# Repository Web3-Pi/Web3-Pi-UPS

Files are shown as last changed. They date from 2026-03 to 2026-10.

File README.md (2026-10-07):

# Web3 Pi UPS

**Open-source DC Uninterruptible Power Supply for Raspberry Pi 5**

**[Product page](https://www.web3pi.io/products/ups)** · **[Watch on YouTube](https://www.youtube.com/watch?v=3EgSPatHWfY)** · **[Web panel](https://panel.web3pi.io)** · **[User guide](https://docs.web3pi.io/ups/)**

<p align="center">
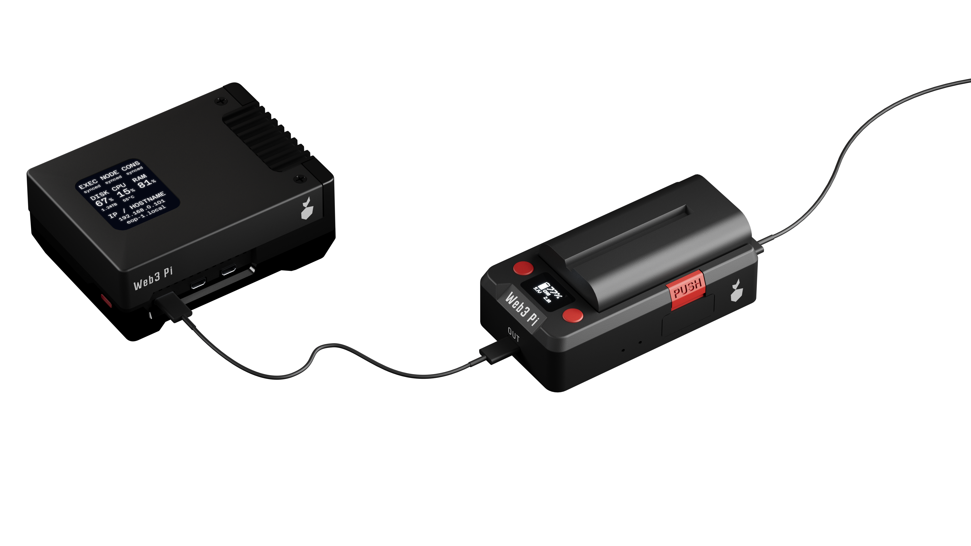
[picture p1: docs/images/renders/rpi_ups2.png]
Web3 Pi UPS with Raspberry Pi 5
  
</p>

Start with the [hardware quick start](docs/QuickStart.md), then install the
[Raspberry Pi host service](https://github.com/Web3-Pi/Web3-Pi-UPS-Service)
for OS telemetry and graceful shutdown. Firmware builds and the companion
projects are listed below.

The Web3 Pi UPS is a purpose-built, compact DC UPS designed specifically for the Raspberry Pi 5. Born from the [Web3 Pi](https://www.web3pi.io) project — a platform for running Ethereum nodes on Raspberry Pi — it exists because nothing else on the market solved the problem properly.

Running an Ethereum node requires 24/7 uptime. A power outage doesn't just interrupt service — it can corrupt the node database, requiring hours or even days of re-synchronization. For solo stakers, downtime means missed attestations and real financial penalties. We needed a UPS that actually fits the Raspberry Pi form factor, and when we couldn't find one, we built it ourselves.

## Why Not an Existing UPS?

Traditional UPS units are massive compared to a Raspberry Pi. They convert mains AC to DC to charge a battery, then invert DC back to AC for output, only for your Raspberry Pi's power supply to convert it back to DC again. Each conversion wastes energy and generates heat.

HAT-style UPS boards for Raspberry Pi stack on top via GPIO, making them incompatible with most enclosures and adding mechanical complexity.

**Web3 Pi UPS takes a different approach.** It sits between your charger and the Raspberry Pi, connected by a single USB-C cable. No GPIO, no stacking, no enclosure conflicts. It's a true DC UPS — power flows from input to battery to output without any AC conversion. Compact, silent, and efficient.

<p align="center">
  Web3 Pi UPS — multiple battery sizes
</p>

## Key Features

### Three Independent Power Sources

The UPS accepts power from three sources — any single one is enough to keep the output running:

- **USB-C PD input** (9–20 V profiles, selected through HUSB238) — primary power from a USB-C PD charger
- **DC barrel jack** (12–20 V) — alternative input for standard DC power supplies
- **Sony NP-F battery** — backup power when both external sources are lost

The power path seamlessly and instantly switches between sources with zero interruption. When external power is present, the battery charges. When external power drops, the battery takes over — no gap, no glitch.

### Sony NP-F Battery Ecosystem

<p align="center">
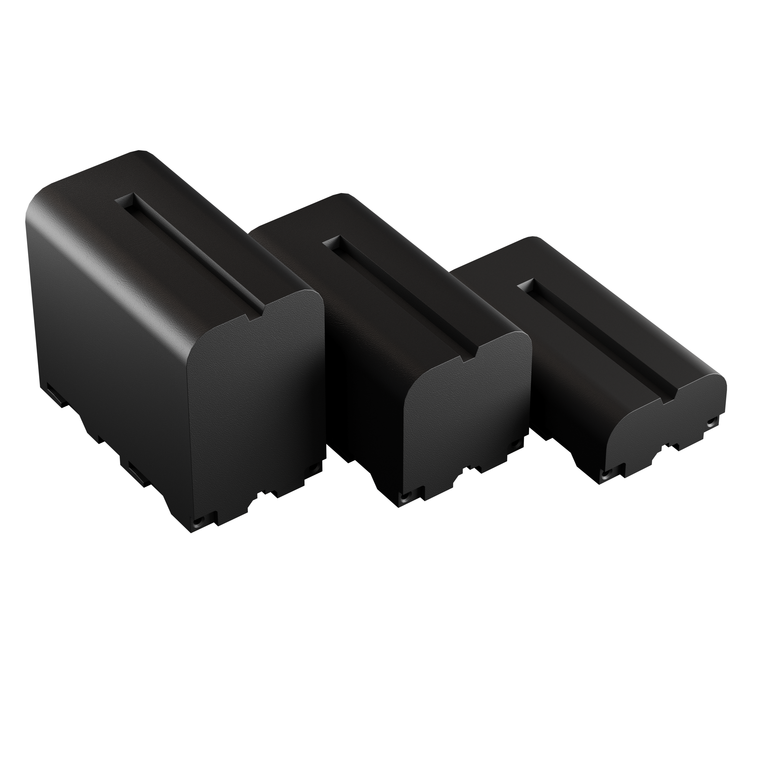
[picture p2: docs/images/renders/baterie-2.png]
Sony NP-F batteries
  
</p>

We chose the Sony NP-F battery system for a reason. These Li-ion cells are one of the most popular battery standards in the world, widely used in photography and videography equipment. You can buy them anywhere — online, in camera stores, globally. They come in multiple capacities to match your needs:

| Battery | Typical Capacity | Approximate Runtime* |
|---|---|---|
| NP-F570 | 2900 mAh | Shorter runtime, most compact |
| NP-F770 | 5200 mAh | Mid-range |
| NP-F970 | 6600 mAh | Longest runtime |

*Runtime depends on your Raspberry Pi's workload and connected peripherals.*

Batteries are **hot-swappable** — you can replace them while the system is running, as long as external power is connected. No downtime, no shutdown. You can also mix and match different NP-F sizes depending on your use case.

### Single USB-C Cable for Power and Communication

Here's something most people don't know: the USB-C port on the Raspberry Pi 5 isn't just for power. It also supports USB data transfer when enabled in `config.txt`. Web3 Pi UPS takes advantage of this — **one USB-C cable carries both power delivery and a data channel** between the UPS and the Raspberry Pi.

This data link enables:

- **Graceful shutdown** — when battery reaches a critical level, the UPS tells the OS to shut down cleanly, preventing filesystem and database corruption
- **Real-time telemetry** — battery level, charging status, input source, voltage, current, and temperature are all accessible from the Raspberry Pi
- **Remote monitoring** — integrate UPS status into your monitoring stack (Grafana, scripts, etc.)

### Built-in User Interface

The UPS has an OLED display (SSD1306) and two tactile buttons for local status monitoring and configuration — no need to SSH in just to check battery level. An onboard buzzer provides audible alerts for power events.

<p align="center">
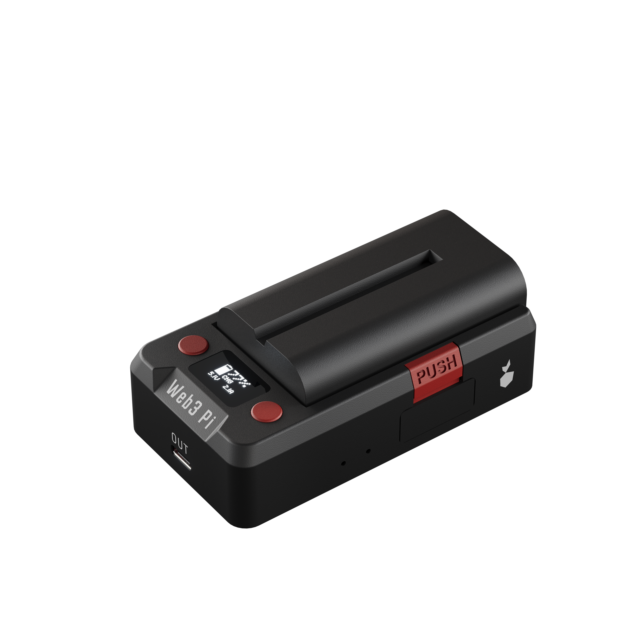
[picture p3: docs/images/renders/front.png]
Web3 Pi UPS — front view
  
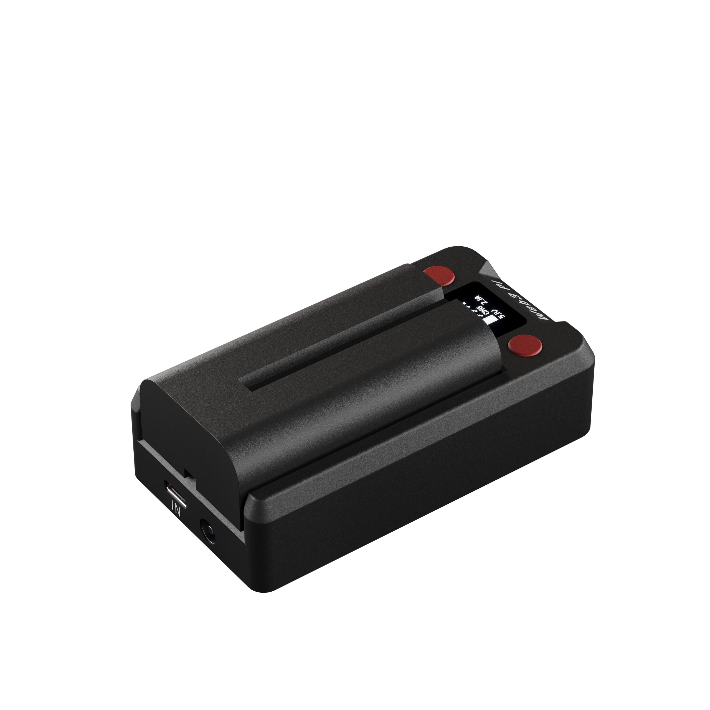
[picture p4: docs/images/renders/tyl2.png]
Web3 Pi UPS — rear view
  
</p>

### USB-C PD Output

The output port supports USB Power Delivery with multiple voltage profiles:

- **5 V / 5 A, 9 V / 3 A, 12 V / 2.25 A, 15 V / 1.8 A** — four advertised profiles, up to **27 W**
- Fully compatible with Raspberry Pi 5 power requirements
- Also works with other USB-C PD powered devices

### Smart Battery Management

The onboard charger (MP2762A) handles 2S Li-ion charging with temperature monitoring via an LM75B sensor. The power path management reduces battery wear by limiting charge when the battery is full — extending its lifespan over hundreds of cycles.

## A Raspberry Pi for Raspberry Pi

A fun detail: the UPS uses a **Raspberry Pi RP2040** microcontroller for the UI panel and system monitoring. So it's a Raspberry Pi-powered device, built for Raspberry Pi.

The current rev.3 power board uses a **CH32X035** RISC-V MCU for USB-PD
output and power management. A separate **HUSB238** negotiates USB-C input
power. The RP2040 also routes the shared WUPS binary protocol between the
power controller, Raspberry Pi host service and optional LTE-M card.

### Optional LTE-M Expansion

The **W3P MODEM V1** M.2 card combines an **ESP32-S3** with a **SIM7080G**
modem. It provides telemetry, authenticated remote commands and ESP32/RP2040
firmware updates over MQTT, HTTP or Arkiv while operating independently of
the Raspberry Pi's local network. The current firmware targets **LTE Cat-M1
on B3/B20**. See the [LTE-M firmware README](firmware-ESP32-LTE-M/README.md)
for hardware details, APN profiles and update requirements.

<p align="center">
  <a href="docs/images/lte-m-module-perspective.png">
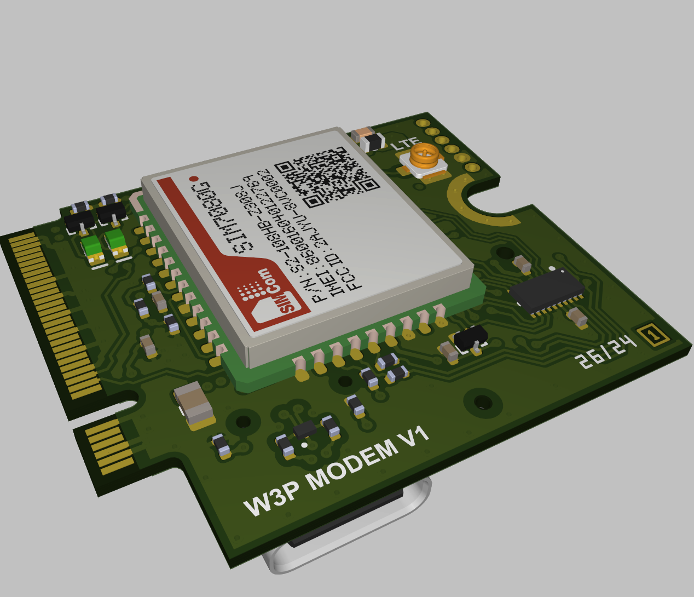
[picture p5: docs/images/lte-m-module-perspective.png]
W3P MODEM V1 M.2 LTE-M expansion card — perspective render
    
  </a>
</p>
<p align="center">
  <a href="docs/images/lte-m-module-modem-side.png">
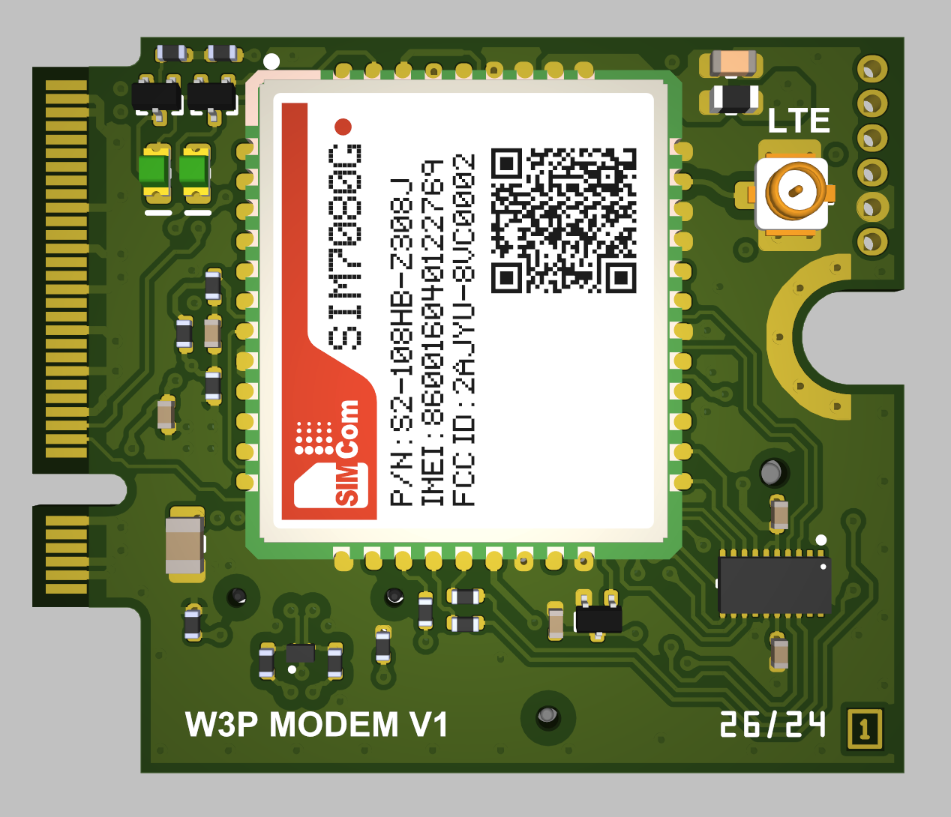
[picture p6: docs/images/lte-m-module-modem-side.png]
W3P MODEM V1 — SIM7080G modem and LTE antenna connector side
    
  </a>
  <a href="docs/images/lte-m-module-reverse.png">
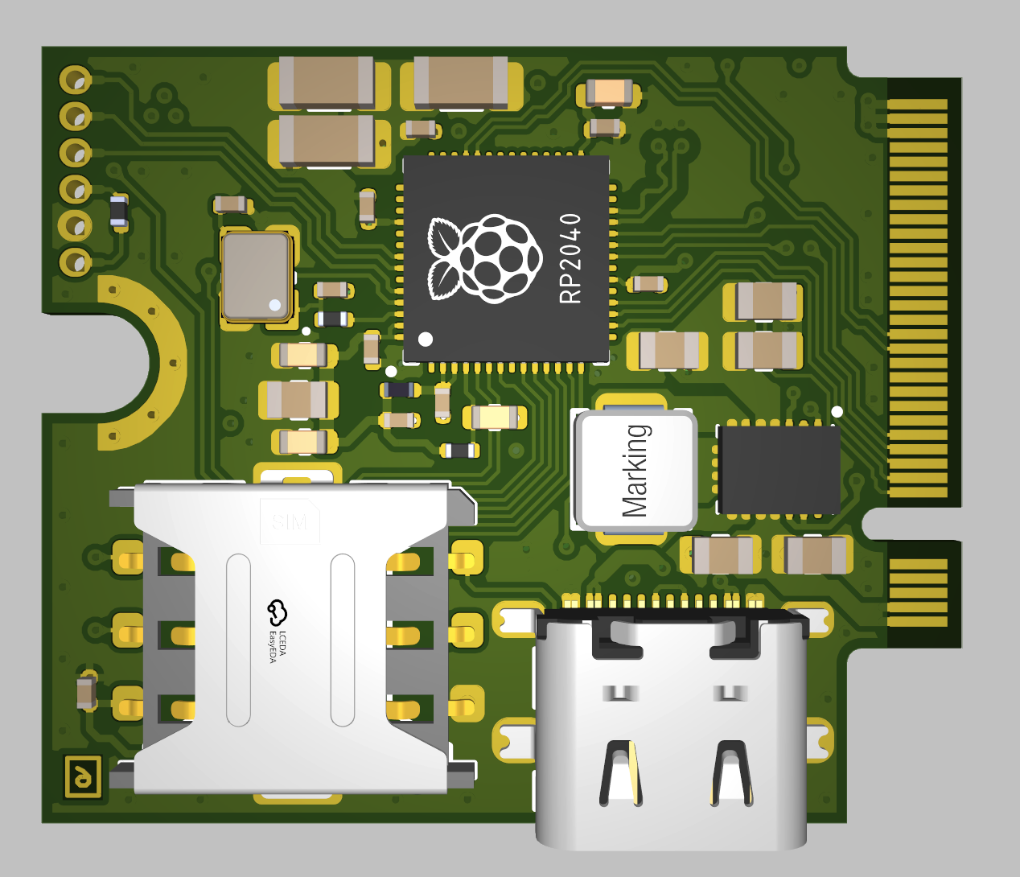
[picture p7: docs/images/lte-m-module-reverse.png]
W3P MODEM V1 — reverse-side render with SIM holder and USB-C connector
    
  </a>
</p>

*W3P MODEM V1 — 3D design renders. The RP2040 marking on the reverse-side
render differs from the current module's documented ESP32-S3 MCU.*

## Web Panel and Remote Management

The [Web3 Pi Control Panel](https://panel.web3pi.io) lets you monitor and
manage your UPS from a browser. With the LTE-M expansion, the UPS communicates
independently of the Raspberry Pi's local network.

<p align="center">
  <a href="https://panel.web3pi.io">
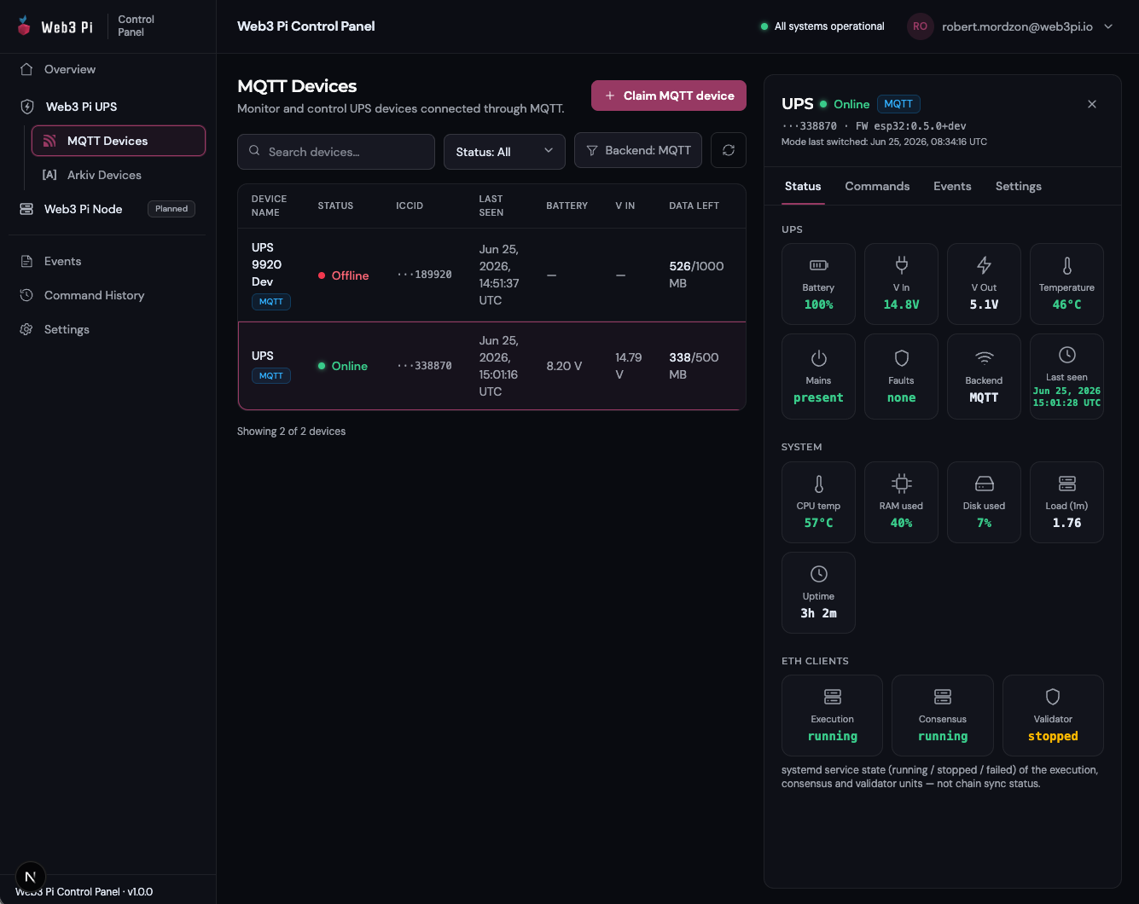
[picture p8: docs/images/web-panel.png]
Web3 Pi web panel showing the MQTT device list, UPS power telemetry, Raspberry Pi metrics and Ethereum service states
    
  </a>
</p>

*MQTT device list and status view, from the project documentation (June 2026).*

- **Live monitoring** — battery, input/output power, temperature, faults,
  LTE radio quality and remaining SIM data.
- **Raspberry Pi status** — CPU temperature, memory, disk, uptime and
  execution/consensus/validator service states, supplied by the
  [host service](https://github.com/Web3-Pi/Web3-Pi-UPS-Service).
- **Remote control and history** — manage the UPS output, reboot or shut
  down the Pi, start/stop/restart allowed services, and review events and
  command results.
- **Firmware updates** — update the ESP32 or RP2040 over LTE and follow
  update progress in the panel.

MQTT devices use an account and sticker claim token; Arkiv devices use
owner-wallet claims and encrypted telemetry. See the
[web panel guide](https://docs.web3pi.io/ups/connectivity/web-panel/) for
setup and the [panel repository](https://github.com/Web3-Pi/Web3-Pi-UPS-Panel)
for source code.

## Technical Summary

| Parameter | Specification |
|---|---|
| **Output** | USB-C PD: 5 V / 5 A, 9 V / 3 A, 12 V / 2.25 A, 15 V / 1.8 A |
| **Input 1** | USB-C PD through HUSB238; 9–20 V profile selection |
| **Input 2** | DC barrel jack (12–20 V) |
| **Input 3** | Sony NP-F battery (Li-ion, 2S) |
| **Battery** | Sony NP-F series — NP-F570 / NP-F770 / NP-F970 |
| **Hot-swap** | Yes (with external power connected) |
| **Communication** | USB data over the same USB-C power cable |
| **Display** | SSD1306 OLED |
| **Controls** | 2 tactile buttons + buzzer |
| **MCU (power)** | CH32X035F8U6 (RISC-V, USB-PD 3.0 PHY) |
| **MCU (UI / protocol router)** | Raspberry Pi RP2040 |
| **Optional connectivity** | W3P MODEM V1: ESP32-S3 + SIM7080G, LTE-M B3/B20 |
| **DC-DC** | TPS55289 buck-boost (3-30V range) |
| **Charger** | MP2762A (2S Li-ion, temp monitored) |
| **Enclosure** | 3D-printed (FDM), snap-fit assembly |

## Electronics

### Main Board

4-layer PCB with USB-PD controller, charger, DC-DC converter, and NP-F battery connector.

<p align="center">
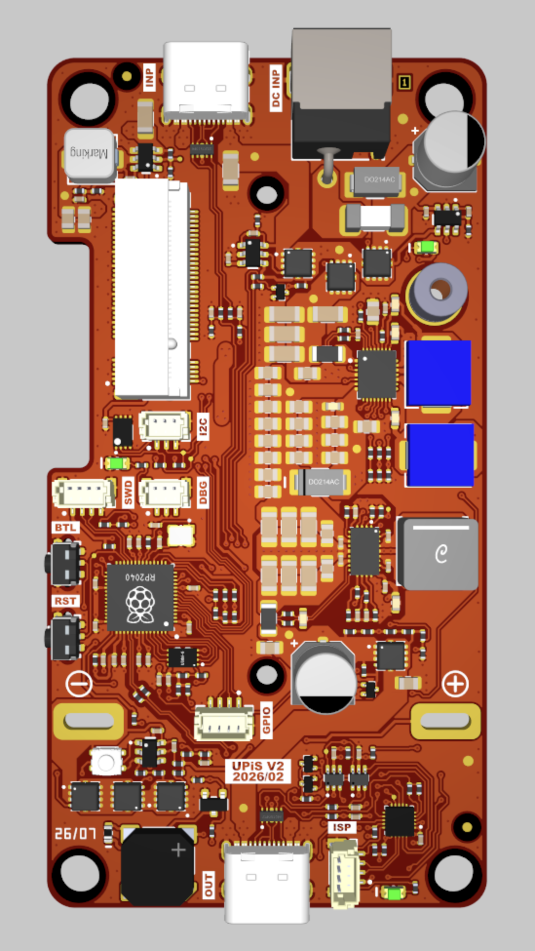
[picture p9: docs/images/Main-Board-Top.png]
Main Board — top
  
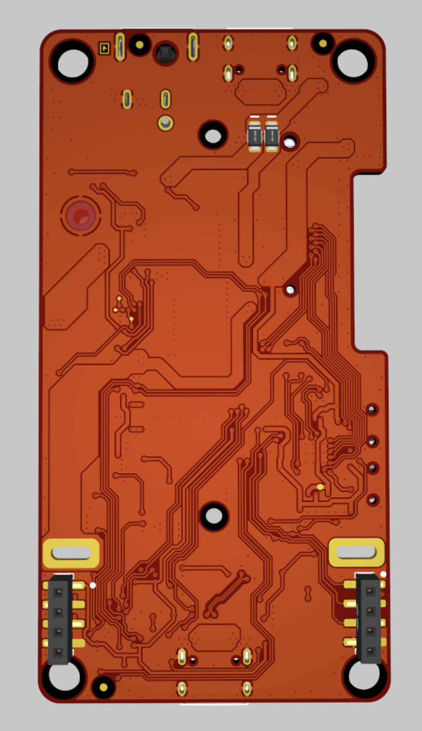
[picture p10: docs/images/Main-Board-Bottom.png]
Main Board — bottom
  
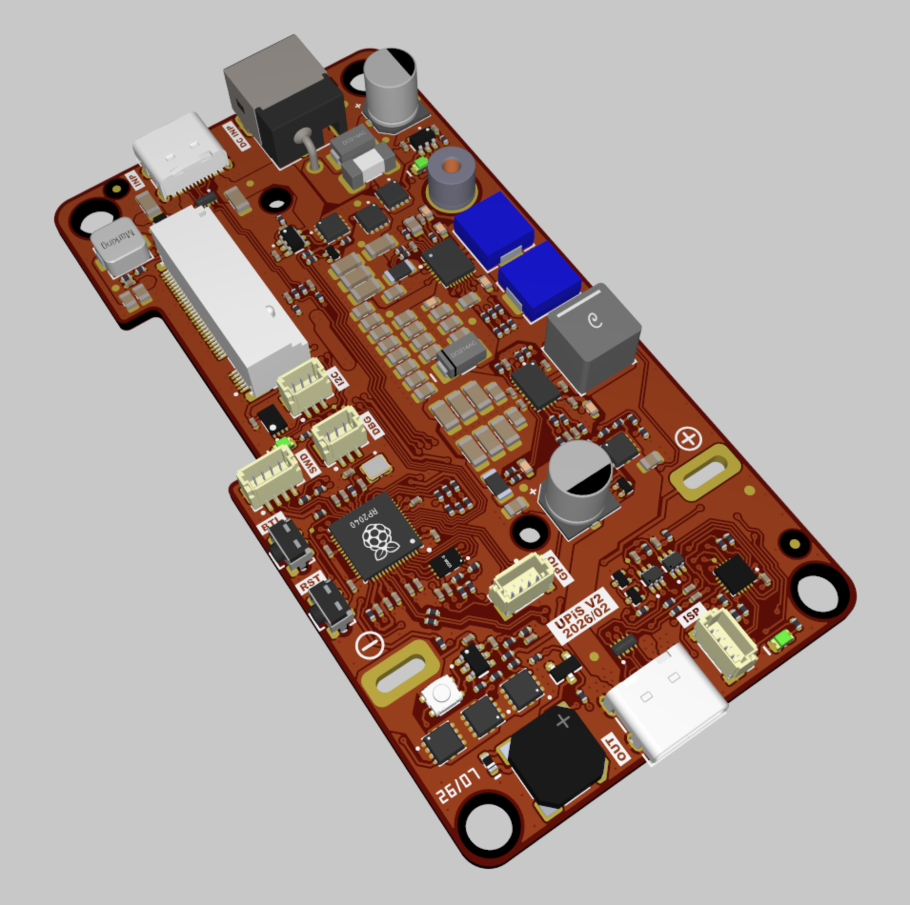
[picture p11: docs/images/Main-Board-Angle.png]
Main Board — angle
  
</p>

### UI Panel

2-layer PCB with SSD1306 OLED display, two tactile buttons, and RP2040 controller.

<p align="center">
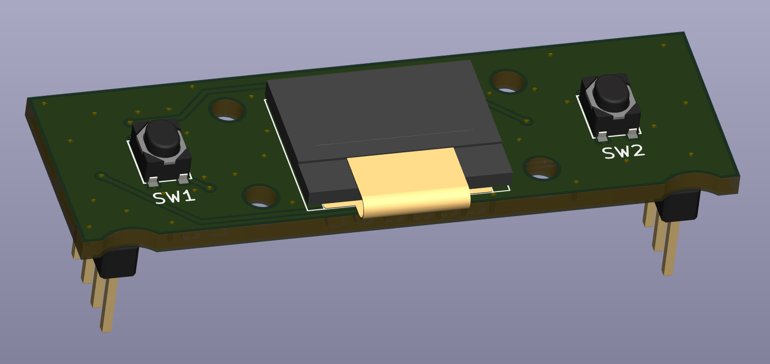
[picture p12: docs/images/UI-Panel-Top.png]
UI Panel — top
  
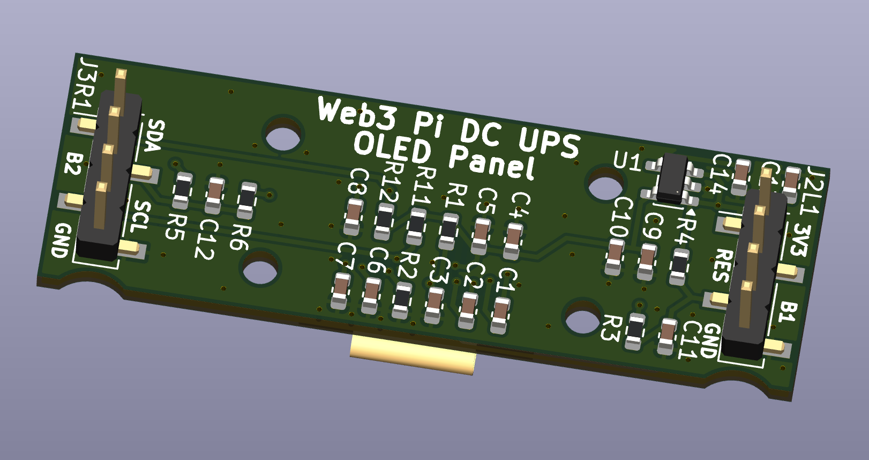
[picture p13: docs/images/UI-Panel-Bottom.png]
UI Panel — bottom
  
</p>

## Enclosure

3D-printed enclosure designed for FDM printing. Multi-part assembly with snap-fit battery latch.

<p align="center">
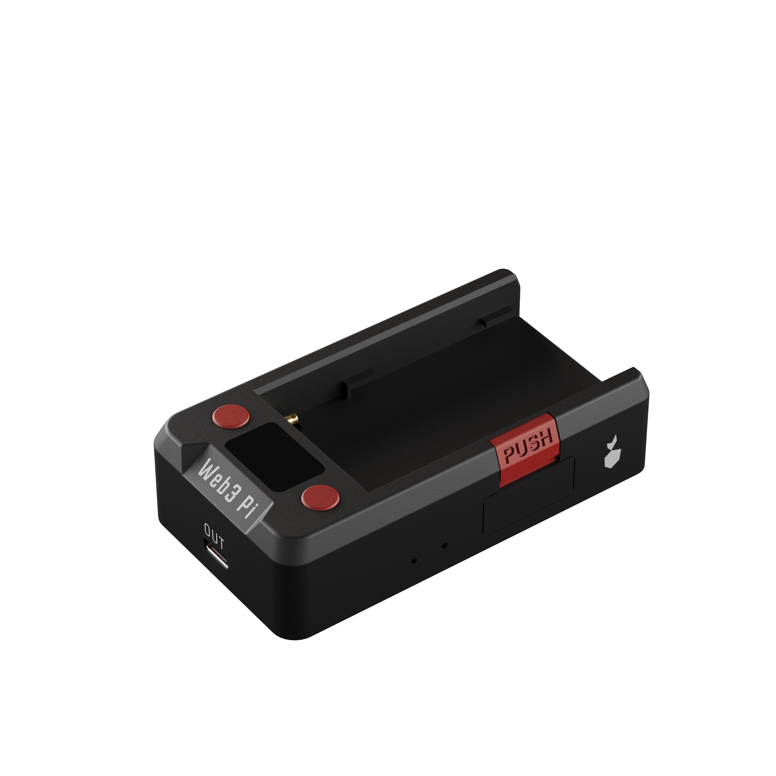
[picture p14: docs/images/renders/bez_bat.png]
Web3 Pi UPS — battery bay
  
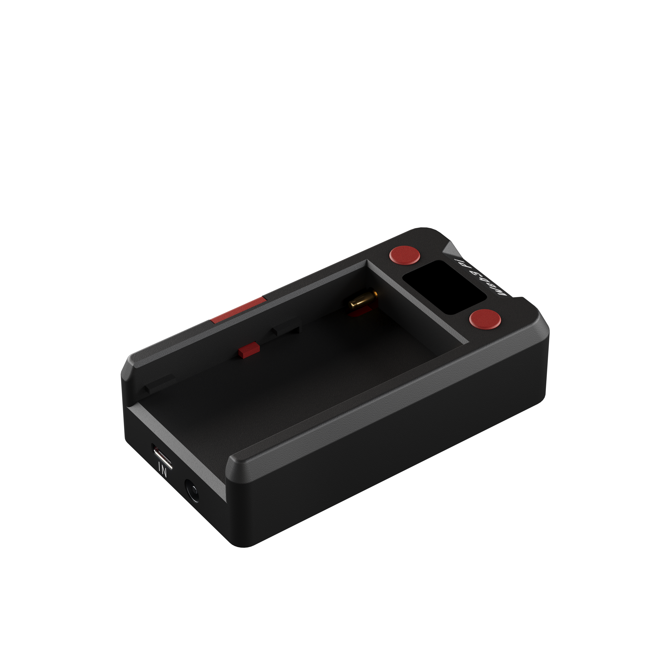
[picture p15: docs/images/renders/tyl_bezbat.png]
Web3 Pi UPS — rear without battery
  
</p>

**Parts:** Enclosure Main, Enclosure Bottom, Side Cover, Buttons, Lock, Press Lock Button, OLED Dimmed Window

Full STEP assembly: [`hardware/enclosure/Web3_Pi_UPS_3DPrinted.step`](hardware/enclosure/Web3_Pi_UPS_3DPrinted.step)

## Repository Structure

```
firmware-ch32x/                     CH32X035 firmware — USB-PD source, power management
firmware-rp2040/                    RP2040 firmware — OLED UI, protocol router, local update receiver
firmware-ESP32-LTE-M/               ESP32-S3 firmware — LTE-M, backends, commands, OTA
common/                            Shared WUPS binary protocol and human-readable specification
tools/                             Host regression tests and development utilities
examples/http-control-server/      Reference HTTP backend
service/                           Historical placeholder; host service is a separate repository
hardware/
├── electronics/
│   ├── main-board/                 Main power board — schematic, STEP, Gerber, BOM, PnP
│   └── ui-panel/                   OLED + buttons panel — schematic, STEP, Gerber, BOM
└── enclosure/                      3D-printed enclosure — STEP assembly, STL parts
docs/images/                        Renders and photos
```

## Firmware and Builds

These are the versions declared in the current source tree; they do not
identify which firmware is installed on a particular device.

| Target | Source version | Build tool | Details |
|---|---|---|---|
| CH32X035 power controller | `ch32x:1.1.1` | WCH GCC / MounRiver Studio 2 | [README](firmware-ch32x/README.md) |
| RP2040 UI and router | `rp2040:1.2.4` | PlatformIO, arduino-pico 5.6.1 | [README](firmware-rp2040/README.md) |
| ESP32-S3 LTE-M card | `esp32:0.8.18` | ESP-IDF v6.0.2 | [README](firmware-ESP32-LTE-M/README.md) |

Build from this repository root, with the corresponding toolchain available:

```sh
# CH32X035: WCH riscv-none-embed-gcc, output in firmware-ch32x/build/
make -C firmware-ch32x

# RP2040: output in firmware-rp2040/.pio/build/pico/
pio run -d firmware-rp2040 -e pico

# ESP32-S3: activate ESP-IDF v6.0.2 first
cd firmware-ESP32-LTE-M
idf.py set-target esp32s3       # first build in a fresh checkout
idf.py build
```

Use each firmware README for flashing instructions and device-specific update
requirements. RP2040 1.2.4 defaults to OLED brightness **Lvl 1/6** and migrates
older saved brightness settings while preserving the sound preference. ESP32
0.8.18 keeps the backend-outage clock across watchdog modem resets, so a
continuous backend outage reaches the `NO UPLINK` alert (issue #20).
0.8.17 uses 300-second MQTT deadlines and 5-second retransmission, building
on 0.8.16 bounded MQTT service and recovery fixes plus the CPU/UART work
from `research`; SINR telemetry and separately selectable fixed-APN builds
remain available. See the ESP32 README for persistent UART migration and
legacy downgrade requirements.

[GitHub Actions](.github/workflows/firmware-ci.yml) builds all three targets
and runs host regressions for MQTT, modem recovery, OTA and protocol handling.
CI builds the default automatic-APN ESP32 image; fixed-APN variants need their
own builds. CI does not flash hardware or establish field reliability.

## Protocol and Companion Projects

The canonical wire definitions are in [common/protocol.h](common/protocol.h),
with a [human-readable protocol guide](common/protocol_desc.md). USB-CDC and
MCU UART links carry binary WUPS frames.

| Project | Role |
|---|---|
| [Web3-Pi-UPS-Service](https://github.com/Web3-Pi/Web3-Pi-UPS-Service) | Raspberry Pi host agent, USB communication, host telemetry and graceful shutdown |
| [Web3-Pi-UPS-Panel](https://github.com/Web3-Pi/Web3-Pi-UPS-Panel) | Web dashboard, device telemetry and remote management |
| [Web3-Pi-UPS-Workbench](https://github.com/Web3-Pi/Web3-Pi-UPS-Workbench) | Local USB diagnostics, HTTP-mode configuration and firmware updates |

For a custom backend, see [HTTP control mode](docs/http-control-mode.md), the
[HTTP server example](examples/http-control-server/README.md) and
[MQTT server setup](docs/mqtt-server-setup.md).

## Links

- [Web3 Pi UPS — product page](https://www.web3pi.io/products/ups)
- [Web3 Pi UPS — video on YouTube](https://www.youtube.com/watch?v=3EgSPatHWfY)
- [Web3 Pi Control Panel](https://panel.web3pi.io)
- [Web3 Pi — project homepage](https://www.web3pi.io)

## License

This project uses dual licensing:

| Component | License | File |
|---|---|---|
| Project firmware and software | [GPL-3.0](LICENSE-SOFTWARE) | `LICENSE-SOFTWARE` |
| `hardware/` | [CERN-OHL-S v2](LICENSE-HARDWARE) | `LICENSE-HARDWARE` |

Bundled third-party components retain their own license notices.

---

*Disclaimer: Raspberry Pi is a trademark of Raspberry Pi Ltd. Sony NP-F is a trademark of Sony Corporation. The use of these trademarks here is solely for descriptive purposes.*

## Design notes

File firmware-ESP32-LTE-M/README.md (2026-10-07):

# Web3 Pi UPS — firmware-ESP32-LTE-M

Firmware for the **W3P MODEM V1 LTE-M expansion card** for Web3 Pi UPS.
Provides cellular telemetry, authenticated commands and firmware updates over
MQTT, HTTP or Arkiv, independently of the Raspberry Pi's local network.

The current firmware uses **LTE Cat-M1 only**, on **B3 (1800 MHz) and B20
(800 MHz)**. NB-IoT selection is disabled. Version 0.8.18 keeps the
[backend-outage clock across watchdog modem resets](docs/RELEASE-0.8.18.md),
so a continuous backend outage reaches the `NO UPLINK` alert (issue #20).
Version 0.8.17 adds
[300-second MQTT deadlines and 5-second retransmission](docs/RELEASE-0.8.17.md).
Version 0.8.16 added
[bounded MQTT/TLS service and guarded modem recovery](docs/MQTT-RECOVERY-15-17.md).
The [0.8.15 release added SINR telemetry and fixed-APN build variants](docs/RELEASE-0.8.15.md).
For the underlying radio and recovery behavior, see the
[0.8.14 integration and validation notes](docs/RELEASE-0.8.14.md).

## Hardware

The committed defaults target the W3P MODEM V1 M.2 card:

- **MCU:** ESP32-S3FH4R2 at 240 MHz, 4 MB flash; PSRAM is disabled.
- **Modem:** SIMCom SIM7080G, controlled over UART1; the configured rate is
  230400 baud. The migration safeguards below may temporarily use 115200.
- **Power:** hardware supplies the modem's 3.8 V rail; this card has no AXP2101
  PMU. The LilyGo PMU path is disabled.
- **UPS link:** UART2 carries the WUPS protocol to the RP2040.

| Modem signal | ESP32 GPIO |
|---|---|
| PWRKEY control | 1 |
| ESP32 TX → modem RX | 2 |
| ESP32 RX ← modem TX | 4 |
| DTR, held low | 5 |
| RI, currently unused by firmware | 6 |

The M.2 connector uses a custom pinout. The earlier
[LilyGo board notes](docs/info.md) and
[LilyGo schematic](docs/T-SIM7080G_Schematic.pdf) are prototype references;
their flash size, GPIO assignments and PMU setup differ from this target.

## Current state

The firmware establishes PPP using `esp_modem`, supervises the selected backend,
exchanges telemetry and commands with the RP2040, and supports ESP32 HTTPS OTA
and relayed RP2040 updates. MQTT producers use bounded application queues;
an independent monitor checks fresh publication proof. ESP32 OTA has bounded
download retries, checked HTTP Range resumption and rollback protection.

The modem's radio configuration is read back and verified before registration.
`CSCLK=0`, `CPSMS=0` and disabled LTE-M eDRX keep the UART and data path available.
The firmware reads these settings before changing them, avoids redundant
persistent writes, and verifies the active PSM/eDRX state after registration.

The default APN profile uses the existing fleet classification: the five
known legacy SIM ICCIDs use `iot.1nce.net`; other SIMs use `sensor.net`. A
fixed-APN build overrides this classification. In either case, the selected
APN is applied to the DCE and `AT+CGDCONT` before PPP and retained on retries.
The profiles below are separate build choices; the firmware does not switch
between APNs automatically after a connection failure.

Version 0.8.15 adds SINR to `net.status` v3, alongside RSRP, RSRQ and RSSI.
Missing or invalid SINR uses the signed `-128` sentinel; `0 dB` is a valid
reading. MQTT and Arkiv carry the extended frame, and HTTP includes `sinr_db`
when available. A compatible panel is needed to display the new measurement.

Full `AT+CEREG?`, `AT+COPS?` and `AT+CPSI?` replies are logged at startup and
during CMUX supervision. Additional diagnostics include `AT+CGDCONT?`,
`AT+CPSMS?`, `AT+CPSMRDP`, `AT+CEDRXS?`, `AT+CEDRX?`, `AT+CEDRXRDP`,
`AT+CSCLK?`, `AT+CPSMCFG?` and `AT+CPSMCFGEXT?`. Captures are bounded and report
completion/truncation status. UTC correlation is labelled synchronized only
after SNTP confirmation; earlier captures are marked unsynchronized.
Optional diagnostics yield to OTA and PPP loss. Plain DATA-mode fallback has
no concurrent AT channel, so periodic modem diagnostics are unavailable there.

See [MQTT resilience and its verification limits](docs/MQTT-RESILIENCE.md) for
queue ownership, recovery and image-confirmation behavior. Short bench tests
and host fault injection do not establish that field LTE outages are resolved.

## Requirements

- **ESP-IDF v6.0.2**, with its ESP32-S3 compiler and Python dependencies.
- macOS / Linux. Windows untested (Bash wrappers, POSIX signals).
- For flashing or monitoring, USB access to the ESP32-S3 programming/console
  interface on the W3P MODEM V1 card.

## Build / flash / monitor

From this directory, with ESP-IDF v6.0.2 activated:

```sh
idf.py set-target esp32s3       # first build in a fresh checkout
idf.py build
```

`tools/idf` is a local wrapper around the same commands. It currently refers to
the maintainer's EIM installation and v6.0.2 checkout; use an activated `idf.py`
directly on another machine. The wrapper coordinates with `tools/serial-monitor`
when an operation needs the serial port:

```sh
# Pane A: serial monitor in the foreground (log → logs/serial.log)
tools/serial-monitor --truncate

# Pane B: build + flash (the monitor yields the port automatically and reconnects after the flash)
tools/idf build
tools/idf flash
```

The generated `sdkconfig` is ignored by Git. For a clean build from the committed
defaults, preserve any intentional local overrides, remove the stale generated
configuration, then reconfigure. Verify **4 MB flash**, the custom two-slot
partition table, rollback support and the incremental MQTT packet-ID option.

The component lock and local MQTT/HTTPS OTA components are part of the build.
Do not remove the local overrides or change their source hashes to bypass a
configuration error; the patches and adapter must be reviewed together.

The research work also provides optional modem CPU1 affinity, unbuffered TX
and sparse CPU/UART diagnostics. The hardware image `0.8.16-1nce-240-c1`
used `CONFIG_WUPS_MODEM_CORE1=y` and `CONFIG_WUPS_MODEM_TX_UNBUFFERED=y`;
these switches remain off in the inherited clean-build defaults. The two
0.8.17 fixed-APN release images retain this profile via `sdkconfig.release-c1`;
see [the release build commands](docs/RELEASE-0.8.17.md). The synthetic
traffic and reconnect benchmarks are test-only options and default off.

### UART speed and OTA rollback

The SIM7080G persists `AT+IPR` across resets. The earlier `main` firmware
through 0.8.15 expects 115200 baud, so changing the saved rate during an
unconfirmed OTA boot would make automatic rollback lose modem communication.
Version 0.8.16 selects the configured rate only when the running partition
already has OTA state `VALID` at modem initialization. Every other state,
including `UNDEFINED`, or a failed state query selects 115200. That selection
is retained for the entire boot, even after publication proof confirms the
image. A subsequent boot of a confirmed image selects the configured 230400
rate. Serial-flashed images without a `VALID` OTA state therefore also retain
115200.

This protects the first OTA migration from a modem initially at 115200. It
cannot undo an earlier change to 230400 before this firmware gets to run.

Before manually installing a legacy 115200-only image, boot a current image
configured with `CONFIG_WUPS_MODEM_UART_115200=y` and verify its UART/IPR log
first. This restores the persistent modem setting before the downgrade.

Production Arkiv images require the locally supplied, gitignored
`main/arkiv_ws_token.h`. Fresh public checkouts and CI compile with the committed
placeholder instead: WSS push cannot connect and command handling falls back
to HTTP polling. Keep the real header out of commits and source archives.

### APN Build Profiles

Use separate build directories so the CMake cache keeps each profile isolated.
From this directory with ESP-IDF activated:

```sh
# Default fleet classification (legacy ICCID list -> 1nce, other SIMs -> sensor)
idf.py -B build-auto -DPROJECT_VER=0.8.18 -DWUPS_FIXED_APN= build

# Always use iot.1nce.net, independent of ICCID
idf.py -B build-1nce -DPROJECT_VER=0.8.18-1nce -DWUPS_FIXED_APN=iot.1nce.net build

# Always use sensor.net, independent of ICCID
idf.py -B build-sensor -DPROJECT_VER=0.8.18-sensor -DWUPS_FIXED_APN=sensor.net build
```

Each directory contains `firmware-ESP32-LTE-M.bin`, the application image for
the existing two-slot OTA layout. The version suffix is also reported in the
runtime `esp32:` identity. A fixed-APN image must match the intended SIM's data
service. Neither profile includes per-device provisioning or changes APN
when registration or data transfer fails. See the
[0.8.15 release notes](docs/RELEASE-0.8.15.md) for validation scope.

### One-time migration to the two-OTA partition table (OTA-1)

The first flash of the OTA-1 layout (`ota_0`/`ota_1` + `otadata`) on a unit
that ran the old single-`factory` table **must erase the old `nvs` region
first**: the partition shrank 0x6000 → 0x4000 in place and `idf.py flash`
never touches it, so a truncated wear-leveled NVS can silently resurrect a
stale WS-9 anti-replay counter (`last_ctr`) or trip
`ESP_ERR_NVS_NO_FREE_PAGES`, which auto-erases all runtime state (including
`backend_mode`). With the serial monitor stopped (or yielded):

```sh
ESPPORT=/dev/cu.usbmodemXXXX  # replace with the connected device
esptool.py --port "$ESPPORT" erase_region 0x9000 0x6000
idf.py -p "$ESPPORT" flash
```

**Never** use `erase_flash` on a provisioned unit — it wipes the per-device
`prov` partition at 0x310000. After the `erase_region`, cmdauth reseeds
`cur_epoch` from `prov` and `last_ctr` restarts at 0 (the panel's counter is
monotonically higher), so no re-provisioning is needed. This jump cannot be
taken over the air; fielded factory-layout devices need this USB flash once.

Reset the currently installed firmware without reflashing (configuration changes
require a rebuild and flash before they take effect):

```sh
tools/reset
```

## Layout

```
firmware-ESP32-LTE-M/
├── CMakeLists.txt           # top-level ESP-IDF project
├── README.md                # this file
├── version.txt              # ESP-IDF application version
├── components/              # local components, including reviewed SDK patches
├── main/
│   ├── CMakeLists.txt
│   ├── main.c               # application initialization and supervision
│   ├── modem.c              # SIM7080G, registration, PPP and diagnostics
│   ├── mqtt.c               # SDK owner, producer queues and health monitor
│   └── fw_ota.c             # ESP32 OTA and RP2040 update relay
├── docs/
│   ├── RELEASE-0.8.15.md     # SINR telemetry and fixed-APN variants
│   ├── RELEASE-0.8.14.md     # integrated changes and validation evidence
│   ├── MQTT-RESILIENCE.md    # behavior, tests and remaining hardware gates
│   ├── info.md              # historical LilyGo prototype reference
│   ├── datasheets/          # PDFs: ESP32-S3-WROOM + SIM7080G (AT, MQTT, TCP/UDP, SSL, SPEC)
│   ├── T-SIM7080G_Schematic.pdf
│   └── LilyGo-T-SIM7080G/   # optional local clone of the upstream repo (gitignored)
└── tools/                   # local copies of the ESP32-Ai-Dev-Loop tools
    ├── idf                  # idf.py wrapper + serial port coordination with the monitor
    ├── idf-mcp-server       # launcher for `idf.py mcp-server`
    ├── serial_monitor.py    # core: serial monitor with auto-reconnect + log file
    ├── serial-monitor       # monitor launcher (uses the IDF venv Python)
    └── reset                # RTS pulse to reset the chip without reflashing
```

## Documentation

In this repo:

- [0.8.15 release notes](docs/RELEASE-0.8.15.md) — SINR telemetry and fixed-APN variants
- [0.8.14 integration notes](docs/RELEASE-0.8.14.md) — modem/PPP/MQTT/OTA changes and validation
- [MQTT resilience](docs/MQTT-RESILIENCE.md) — ownership, proof, recovery and tests
- [MQTT stopped-task adapter](../docs/mqtt-sdk-adapter.md) — pinned SDK contract
- [Local MQTT patch](components/espressif__mqtt/WEB3PI_PATCH.md) and
  [local HTTPS OTA patch](components/esp_https_ota/PROVENANCE.md) — provenance and regressions
- [docs/info.md](docs/info.md) — historical LilyGo prototype pinout and power domains
- [docs/T-SIM7080G_Schematic.pdf](docs/T-SIM7080G_Schematic.pdf) — LilyGo prototype schematic
- [docs/datasheets/](docs/datasheets/) — the datasheets we actually use:
  - [ESP32-S3-WROOM-1/1U Datasheet](docs/datasheets/esp32-s3-wroom-1_wroom-1u_datasheet_en.pdf)
  - [SIM7080G AT Command Manual V1.05](docs/datasheets/SIM7070_SIM7080_SIM7090_AT_Command_Manual_V1.05.pdf) — the canonical AT reference
  - [SIM7080G MQTT(S) Application Note V1.03](docs/datasheets/SIM7070_SIM7080_SIM7090_MQTTS_Application_Note_V1.03.pdf)
  - [SIM7080G TCP/UDP(S) Application Note V1.03](docs/datasheets/SIM7070_SIM7080_SIM7090_TCPUDPS_Application_Note_V1.03.pdf)
  - [SIM7080G SSL Application Note V1.00](docs/datasheets/SIM7070_SIM7080_SIM7090_SSL_Application_Note_V1.00.pdf)
  - [SIM7080 Series Spec](docs/datasheets/SIM7080_Series_SPEC_20200427.pdf)

Upstream reference (not committed to this repo, but useful):

- [LilyGo-T-SIM7080G](https://github.com/Xinyuan-LilyGO/LilyGo-T-SIM7080G) — official board repo: full set of Arduino examples (AT, MQTT, MQTTS, GPS, sleep modes, NB-IoT), 30+ datasheets (Chinese editions, FOTA, GNSS, low-power), pre-built firmware, libraries (TinyGSM, XPowersLib).
  Clone it locally into `docs/LilyGo-T-SIM7080G/` (gitignored) if you need offline access:
  ```sh
  git clone https://github.com/Xinyuan-LilyGO/LilyGo-T-SIM7080G.git docs/LilyGo-T-SIM7080G
  ```

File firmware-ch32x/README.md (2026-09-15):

# Web3 Pi UPS — CH32X035 Power Controller

USB-PD output and power-management firmware for **Web3 Pi UPS hardware
rev.3**. The current source reports **`ch32x:1.1.1`**.

## Architecture

The **CH32X035** controls the USB-C output as a PD source, the TPS55289
buck-boost converter and the MP2762A battery charger. The separate **HUSB238**
handles USB-C input negotiation. CH32X reads the HUSB238 source capabilities
and requests a suitable profile over I²C.

```text
USB-C charger -> HUSB238 input negotiation --+
DC barrel input ----------------------------+-> power path / battery charger
Sony NP-F battery --------------------------+-> TPS55289 -> USB-C output -> Pi
                                                   ^
                               CH32X035: output PD + power control
                                                   |
                                      USART2 / binary WUPS
                                                   |
                                             RP2040 router
```

Earlier board revisions shared SOURCE/SINK duties through a CC mux. The
current main loop no longer runs that role-switching manager: on rev.3, input
PD belongs to HUSB238 and CH32X's PD state machine serves the output port.

## Features

- Four output PD profiles: **5 V / 5 A, 9 V / 3 A, 12 V / 2.25 A,
  15 V / 1.8 A**, with Raspberry Pi 5 PSU identification.
- HUSB238 input profile selection in the **9–20 V** range: prefer a profile
  supplying at least 45 W in the order **15, 12, 18, 20, 9 V**. For weaker
  sources, select near the highest available power with the same voltage
  preference. See [User/husb238.h](User/husb238.h) for the complete policy.
- MP2762A charging and telemetry for a protected 2S Sony NP-F battery pack.
- Voltage/current setpoints, input contract, charger status and fault reporting.
- Binary WUPS status/events and output enable, disable, cycle and reset commands.

## Hardware Interfaces

| Component | Function | I²C address |
|---|---|---|
| HUSB238 | USB-C input PD negotiation | `0x08` |
| LM75B | Board temperature | `0x48` |
| MP2762A | Battery charger and ADC telemetry | `0x5C` |
| TPS55289 | Buck-boost output converter | `0x75` |

The I²C bus uses **PC18 SCL / PC19 SDA**. The RP2040 link is **USART2**, with
**PA2 TX / PA3 RX at 921600 baud**. See [User/main.c](User/main.c) for the
current GPIO map and the [main README](../README.md) for hardware files.

## Building

### Option 1 — MounRiver Studio 2

The project is set up for **[MounRiver Studio 2](http://mounriver.com) (MRS2) V2.4.0**. After cloning:

1. Open MRS2 → **File → Open Folder…** → select this `firmware-ch32x/` directory.
2. The Solution Explorer should populate from the committed `.project` / `.cproject` / `USB-PD.wvproj` files.
3. Build (Ctrl/Cmd + B). Artifacts go to `obj/`.
4. For flashing see **Flashing (macOS)** below — the project does not require a WCH-Link, the CH32X035 USB ISP bootloader is used directly. MRS2 generates a local `.mrs/launch.json` from `USB-PD.wvproj` on first run (it is git-ignored — contains your absolute path).

### Option 2 — Standalone GCC

Use the **WCH** `riscv-none-embed-gcc` toolchain (GCC 8.2 in the CI
MounRiver V1.92 bundle), which supports `rv32imacxw` and WCH interrupt
attributes. Run from this directory:

```bash
make            # build into build/
# Or select the WCH toolchain explicitly:
make CROSS=/path/to/toolchain/bin/riscv-none-embed-
make clean      # remove command-line build artifacts
```

### Output Files

| Build route | Artifacts |
|---|---|
| Committed [Makefile](Makefile), used by CI | `build/USB-PD.elf`, `build/USB-PD.hex`, `build/USB-PD.map` |
| MounRiver Studio 2 | `obj/USB-PD.elf`, `obj/USB-PD.hex`, `obj/USB-PD.map`, `obj/USB-PD.lst` |

The commands below use the MRS2 `obj/` image. Substitute `build/USB-PD.hex`
when flashing a command-line build directly with `wchisp`. The `flash.sh`
helper currently reads `obj/USB-PD.hex` only.

### Toolchain Details

- Compiler: `riscv-none-embed-gcc` (or `riscv32-wch-elf-gcc` in newer MRS_Toolchain bundles)
- Architecture: RV32IMACXW (RISC-V with multiply, atomic, compressed, WCH custom extensions)
- ABI: ilp32
- Optimization: `-Os` (size)
- Linker script: `Ld/Link.ld`

## Flashing (macOS)

Programming uses the **CH32X035 built-in USB ISP bootloader** — no WCH-Link required. On macOS the open-source [`wchisp`](https://github.com/ch32-rs/wchisp) CLI handles erase / program / verify / reset.

### Prerequisites

This project uses a **locally-patched fork of `wchisp`** that adds a `flash --unprotect` flag (`-U`). The flag does WRITE_CONFIG → ISP_KEY → ERASE → PROGRAM → VERIFY in a **single USB session**, mirroring what WCHISPTool's GUI does. With upstream `wchisp` 0.3.0 you have to run `wchisp config unprotect` separately, which sends `IspEnd(1)` and resets the MCU out of the bootloader, forcing a second BOOT+RESET — the patch eliminates that.

The patch is not bundled in this repository. A public checkout of upstream
`wchisp` does not by itself provide the `--unprotect` flag. If using the
maintainer's patched build, verify the capability first:

```sh
wchisp flash --help | grep -- --unprotect
```

With stock upstream, use the documented two-step first-flash sequence below.
The `flash.sh --first` helper requires the patched build and checks for its
flag. Ordinary re-flashing does not require that patch.

### Entering boot mode

The CH32X035 enters USB ISP mode when **BOOT pin is pulled high during reset**. With the board powered off USB:

1. Hold the BOOT button (or jumper BOOT to VCC).
2. Press and release RESET.
3. Release BOOT.
4. The MCU enumerates as a WCH ISP device (USB VID `4348` / `1a86`, PID `55e0`).

Verify it is detected:

```bash
wchisp probe
# Device #0: CH32X035F8U6[0x5e23]
```

### First flash on a fresh CH32X035

Factory chips ship with **read-out protection enabled** (`RDPR = 0xFF`, not `0xA5`). Without unprotecting first, `wchisp flash` writes the firmware fine but **`verify` fails with `mismatch`** because the bootloader returns `0xFF` on read.

With the **patched `wchisp`** (see Prerequisites), one BOOT+RESET is enough:

```bash
wchisp flash --unprotect obj/USB-PD.hex
```

This sends WRITE_CONFIG (unprotect) → ISP_KEY → ERASE → PROGRAM → VERIFY → RESET in one USB session — same flow as WCHISPTool GUI.

> **Stock upstream `wchisp` (no patch)** — you'd need two CLI calls and **two** BOOT+RESET sequences:
> ```bash
> wchisp config unprotect              # sends IspEnd(1) → MCU resets out of bootloader
> # BOOT + RESET again here
> wchisp flash obj/USB-PD.hex
> ```

### Subsequent flashes during development

Once unprotected, the chip stays unprotected across power cycles. BOOT + RESET, then:

```bash
wchisp flash obj/USB-PD.hex
```

### Production flashing

For a chip that still has **RDPR engaged**, the existing production flow
keeps that protection and bypasses readback verification:

```bash
wchisp flash --no-verify obj/USB-PD.hex
```

This skips the readback verification pass and leaves existing protection
unchanged. It does **not** enable protection on an already-unprotected chip;
check the device configuration as part of production programming.

### Helper script: `flash.sh`

A ready-made wrapper lives at [`firmware-ch32x/flash.sh`](flash.sh). Build the `.hex` in MRS2 first, then:

```bash
./flash.sh                    # Dev re-flash (chip already unprotected)
./flash.sh --first            # Fresh chip — single-session unprotect + flash (one BOOT+RESET).
                              # Requires patched wchisp; the script aborts if the --unprotect flag is missing.
./flash.sh --prod             # Production — flashes with --no-verify, RDPR stays engaged
./flash.sh --help             # Usage summary
```

The script waits for the MCU to enter boot mode before flashing, so the batch loop is: plug in next board → BOOT + RESET → script auto-detects and flashes → `✓ Flashed at HH:MM:SS`.

### Troubleshooting

| Symptom | Cause / fix |
|---|---|
| `No WCH ISP USB device found (4348:55e0 ...)` | Not in boot mode. Re-do BOOT + RESET sequence. |
| `Verify failed, mismatch` after `flash` on a fresh chip | RDPR engaged. Use `wchisp flash --unprotect` (patched build) or `wchisp config unprotect` + re-enter boot + `wchisp flash` (upstream), or `--no-verify` for production. |
| `flash.sh --first` aborts with "this wchisp build doesn't support 'flash --unprotect'" | `~/.cargo/bin/wchisp` is the upstream build. Use a build containing the local patch, or the upstream two-step sequence above. |
| Device disappears after `wchisp config unprotect` | Expected — upstream `unprotect` resets the chip via `IspEnd(1)`. Re-enter boot mode, or use the patched `flash --unprotect` instead. |
| Charge-only USB cable | Use a known-good USB-C / USB-A data cable. |

## Binary Status and Commands

The current firmware uses **WUPS wire protocol v1**. It sends
`power.status` **v2** once per second to the RP2040 and emits power events
for mains changes, faults and charge thresholds. Status includes input/output
measurements, the HUSB238 input contract, battery/charger state, temperatures
and fault flags. The old JSON interface is no longer the command/status API.

The authoritative payload definitions are in
[../common/protocol.h](../common/protocol.h), included by
[User/wups_proto.h](User/wups_proto.h). The
[protocol guide](../common/protocol_desc.md) describes addressing, frame
checksums and routing. Diagnostic ASCII may share the UART with framed data;
receivers must synchronize to valid WUPS frames rather than parse lines.

Supported requests include `system.ping`, `system.status_query` and
`power.enable`, `power.disable`, `power.cycle`, `power.reset`. Power-control
commands can interrupt the Raspberry Pi's supply. Coordinate an OS shutdown
through the host service before deliberately cutting power.

## Project Structure

```
Core/           RISC-V core definitions
Debug/          UART debug printf utility (debug.c/h)
Ld/             Linker script (62 KB Flash, 20 KB RAM)
Peripheral/     CH32X035 HAL drivers
  inc/          peripheral headers
  src/          peripheral implementations
Startup/        startup assembly
User/           application code
  main.c             entry point, GPIO/I²C/UART init, main loop
  PD_Process.{c,h}   USB-PD output state machine
  husb238.{c,h}      input PD capabilities, profile selection and telemetry
  wups_proto.h      shared binary protocol include
  tps55289.{c,h}     buck-boost driver
  mp2762a.{c,h}      charger driver
  lm75b.{c,h}        temperature sensor driver
  i2c_lib.{c,h}      software-bitbang I²C
  ch32x035_it.{c,h}  interrupt handlers
  system_ch32x035.{c,h}  clock setup
Makefile        headless build into build/
USB-PD.wvproj   MounRiver Studio 2 project
.project        Eclipse / CDT project descriptor
.cproject       Eclipse / CDT build configuration
.template       MRS chip / toolchain metadata
```

## USB-PD Implementation Notes

- The output PD PHY is integrated in CH32X035. Timing-sensitive responses
  share the main loop with charger and converter polling; avoid adding
  blocking work to interrupt handlers or between PD service calls.
- The HUSB238 input contract is read back after attach. USB-C detach re-arms
  profile selection, independently of barrel-input power.
- The rev.3 board's `PDS_EN` pull-down means a CH32X reset can interrupt the
  output supply. Do not assume a controller reset or flash is transparent
  to a connected Raspberry Pi.

See [the battery-mode telemetry fix](../docs/ch32x-battery-mode-telemetry-fix.md)
for the distinction between charger readings and battery-only operation.

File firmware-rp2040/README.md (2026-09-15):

# Web3 Pi UPS — RP2040 Firmware

Firmware for the Web3 Pi UPS OLED panel and WUPS protocol router. The current
source reports **`rp2040:1.2.4`**. It uses the Arduino framework with the
pinned arduino-pico **5.6.1** core and PlatformIO configuration in
[platformio.ini](platformio.ini).

## What It Does

- Displays input, output, battery and system telemetry on a **64 × 32
  SSD1306 OLED**, with local voltage measurements and two-button navigation.
- Routes binary WUPS frames between the Raspberry Pi host, CH32X035 power
  controller and optional ESP32-S3 LTE-M card.
- Provides a local menu for brightness, sound, information and output power
  control. These settings work without the LTE card; **Network** opens the
  ESP32 menu when the card is present.
- Displays device trust prompts, remote notices, modem alerts and firmware
  update progress.
- Receives RP2040 updates from the ESP32 or a USB host, verifies their SHA-256
  digest, stages them in LittleFS and supports rollback after an unconfirmed
  update.

On the home screen, **hold LEFT** to open the local menu. LEFT moves through
items or changes a value; RIGHT selects. Cutting output power requires the
menu's confirmation screen.

### Current UI Behavior

Version 1.2.4 sets the factory brightness to **Lvl 1/6**. On the first boot
with older version-1 settings, brightness is reset to this level and the saved
sound setting is preserved. Subsequent brightness choices persist. Muting
sound silences all buzzer output, including battery and power alarms.

The **FW UPDATE** banner is silent and displays update progress without the
modem's “no uplink” error line. Ordinary remote notices have their own display
layer and expire after 60 seconds or a button press. They do not replace the
modem alarm state.

## Connections

Pin assignments below come from [src/main.cpp](src/main.cpp).

| Interface | RP2040 pins / transport |
|---|---|
| OLED I²C | GPIO8 SDA, GPIO9 SCL; address `0x3C` |
| CH32X035 | UART0: GPIO16 TX, GPIO17 RX; 921600 baud |
| ESP32-S3 M.2 card | UART1: GPIO20 TX, GPIO21 RX, GPIO22 CTS, GPIO23 RTS; 921600 baud |
| Raspberry Pi host | USB-CDC through the UPS output USB-C port |
| Debug probe UART | J350: GPIO0 TX, GPIO1 RX; PIO UART at 921600 baud |
| Buttons | GPIO13 LEFT, GPIO14 RIGHT; active low |
| Buzzer | GPIO15 |
| Local ADC | GPIO28 battery voltage, GPIO29 output voltage |

The RP2040 is the routing hub. The wire format and payload structures are
shared through [../common/protocol.h](../common/protocol.h); see also the
[protocol guide](../common/protocol_desc.md). USB-CDC carries binary frames,
so a text-only serial monitor is not a telemetry decoder. Use the
[host service](https://github.com/Web3-Pi/Web3-Pi-UPS-Service) or
[Workbench](https://github.com/Web3-Pi/Web3-Pi-UPS-Workbench).

## Build

Install PlatformIO and put `pio` on `PATH` (a standard local installation also
provides `~/.platformio/penv/bin/pio`). Run from this directory:

```sh
pio run -e pico
```

Dependencies include Adafruit GFX, Adafruit SSD1306 and QRCode; PlatformIO
installs them from the committed configuration. Keep the platform commit and
arduino-pico core pins together when upgrading the toolchain.

Build artifacts are in `.pio/build/pico/`: `firmware.uf2`, `firmware.bin` and
`firmware.elf`. The `pico_swd` environment writes to `.pio/build/pico_swd/`.
[CI](../.github/workflows/firmware-ci.yml) builds the `pico` environment.

## Flashing

### SWD — Raspberry Pi Debug Probe

SWD keeps the Raspberry Pi 5 connected to the UPS output USB-C port.

- Wire the Debug Probe's **D** connector to **J401** (4-pin JST SH):
  SC → J401.3 SWCLK, GND → J401.4, SD → J401.2 SWDIO.
- Power the UPS from PD input, barrel jack or battery. The probe does not
  supply the board's 3.3 V rail.

```sh
pio run -e pico_swd -t upload
```

This uses OpenOCD and CMSIS-DAP; a successful upload reports verification.

### USB-C — picotool

Connect the development machine to the UPS **output** USB-C port for bench
flashing. The Raspberry Pi must be disconnected from that port during this
operation.

```sh
pio run -e pico -t upload
```

### Relayed Firmware Updates

The `net.fw_xfer_*` receiver in [src/fw_update.cpp](src/fw_update.cpp) accepts
a firmware image over WUPS. The existing firmware stages the new image and a
rollback snapshot in LittleFS. The new firmware confirms itself after valid
WUPS traffic; missing confirmation or repeated failed boots can trigger
rollback. Failure before the update code can run requires physical recovery.

Keep `board_build.filesystem_size = 1m` stable across compatible updates so
the staged image, rollback snapshot and pending-verification state remain at
the same flash location. Inspect the flash-layout notes in `platformio.ini`
before changing it.

## Source Layout

| File | Purpose |
|---|---|
| [src/main.cpp](src/main.cpp) | Hardware initialization, screens, telemetry and frame dispatch |
| [src/wups_router.cpp](src/wups_router.cpp) | Per-port deframing and WUPS routing |
| [src/local_menu.cpp](src/local_menu.cpp) | Local menu and ESP32 network-menu handoff |
| [src/ui_settings.cpp](src/ui_settings.cpp) | Persisted brightness/sound settings and migration |
| [src/trust_ui.cpp](src/trust_ui.cpp) | Prompts rendered for the ESP32 |
| [src/fw_update.cpp](src/fw_update.cpp) | Update staging, verification and rollback |

See the [main project README](../README.md) for hardware and the other firmware
targets.

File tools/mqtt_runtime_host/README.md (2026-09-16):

# MQTT runtime host boundary tests

`../test_mqtt_runtime.py` compiles the complete current production `mqtt.c`
unchanged, plus the real dispatch queue, health state machine and packet guard.
Each case runs in a fresh process with three pthread-backed FreeRTOS tasks.

The SDK boundary requires every SDK call to come from `mqtt_owner`, outside
the application lock and outside SDK callbacks. The main isolation case holds
the enqueue boundary for **15 real seconds**. Throughout that hold, it checks
that producer, supervisor-style start requests, receipt polling and diagnostics
return within 100 ms on the host. DATA callbacks copy into a bounded command
queue while a separate command handler simulates blocked UART transmission.
It also verifies copied binary data, empty retained messages, queue rejection,
initialization cleanup/retry, pre-initialization OTA state and reconnect backoff
driven by the actual SDK return value.

The `pressure` case controls reported SDK outbox occupancy and injects one
SDK enqueue failure at a time. At 24 KiB, normal traffic waits while critical
traffic can use the reserve; at 32 KiB, both wait. Clearing pressure preserves
retry deadlines and FIFO. Both full (`-2`) and allocation failure (`-1`) leave
messages pending without duplicate SDK admission or same-class overtaking.

The `probe` case publishes a complete cached net.status v2 frame and delivers
PUBACK inside SDK enqueue before it returns. It checks the actual ARMING,
packet-result and health-admission sequence, rejects unrelated and pre-reconnect
ACKs, and requires a new proof after OTA. With the outbox full and then the owner
held at its SDK boundary, the independent monitor reaches admission failure at
the exact virtual 60-second deadline without a producer or diagnostics call
advancing the state first. This case uses virtual time, not another wall-clock
15-second hold.

The 100 ms ceiling is a host regression threshold, not a measured ESP32 latency
guarantee. The UART ACK check is a synthetic next RX-dispatch step; this harness
does not execute the real UART driver or `wups_rx`. Its controlled monotonic
clock accelerates retry deadlines separately from the real SDK hold.

SDK calls are stubs, not a network or TLS emulation. The SDK adapter stub models
its stopped-client contract; a separate adapter test verifies its actual pinned
SDK implementation. Heap/stack metric stubs are fixed synthetic values used for
compilation, not resource measurements. Production client lifetime continues
until reboot; the harness frees it only after all worker threads have joined.

The `ppp_transport` and `ppp_auth` cases replace a PPP generation during a
120-second reconnect backoff. The former must retry promptly once; the latter
must retain the authentication deadline. Repeated start requests cannot bypass
the deadline. `recovery_commit` checks the production reset guard against a
new MQTT connection/generation, OTA, a stalled worker and authentication refusal.
The full runtime suite now contains eleven independently started cases.

Default sanitizer selection is `address,undefined`. Set `MQTT_TEST_SANITIZERS`
to `undefined` or an empty string explicitly on hosts without working ASan.
`MQTT_TEST_SDK_STALL_MS=0` permits a faster development pass; final regression
evidence should use the default full 15-second hold. No silent fallback occurs.
`MQTT_TEST_RUNTIME_CASES=pressure` selects one case; comma-separated names select
a subset. Omit it to run the complete eight-case suite.

## Optional local Linux runner

A native ASan startup failure can be checked in an isolated Linux container:

```sh
docker build -t wups-mqtt-host:local tools/mqtt_runtime_host
docker run --rm --network none --read-only --cap-drop ALL \
  --security-opt=no-new-privileges --tmpfs /tmp:rw,nosuid,nodev,exec \
  --mount type=bind,src="$PWD",dst=/workspace,readonly \
  wups-mqtt-host:local python3 tools/test_mqtt_runtime.py
```

The mount is read-only, there is no runtime network, and compiled tests live in
the disposable executable `/tmp`. Building the image downloads public compiler
packages. The 2026-09-14 Linux GCC 14.2 ASan+UBSan runs passed all eight runtime cases,
including a real 15,000 ms hold and the separately added SDK pressure and probe
cases. This is host evidence, not an ESP32 timing result.

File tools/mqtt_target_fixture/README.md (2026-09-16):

# ESP32 MQTT / TLS loopback qualification

This standalone ESP-IDF 6.0.2 application exercises the repository's actual
opt-in MQTT service, ESP-TLS, mbedTLS and lwIP on an ESP32-S3. A second task is a
minimal TLS 1.2 MQTT broker at `127.0.0.1:18884`. No modem, Wi-Fi, internet,
provisioning, NVS or real MQTT credentials are used. The self-signed certificate
and private key in `main/` are disposable, public test fixtures, unsuitable for
any deployed service. Certificate verification remains enabled. The test sets
its own wall clock to September 2026 so the fixture certificate is valid.

The eight cases cover:

- PUBLISH and PINGRESP combined into one TLS application record, including PUBACK.
- A complete TLS record delivered in small ciphertext fragments.
- Positive ciphertext trickle exceeding the aggregate RX deadline.
- A TLS record prefix followed by silence.
- A missing PINGRESP with a finite response deadline.
- A delayed PINGRESP inside the response interval.
- Real TCP/TLS transmit backpressure with an aggregate operation deadline.
- Stop/cancellation while transmit progress remains blocked.

After the handshake, a custom **server** BIO splits real encrypted record bytes;
the client TLS and network stack are unmodified. Small TCP windows make the
backpressure cases reproducible. Host regression tests separately cover exact
packet ordering, the grace packet limit, outbox expiry and ownership.

Build from this directory with the installed ESP-IDF 6.0.2 environment:

```sh
source /path/to/esp-idf-v6.0.2/export.sh
IDF_COMPONENT_MANAGER=0 idf.py set-target esp32s3 build
```

All component inputs are local, so the component manager is unnecessary. The
app uses the repository vendor component via a relative CMake path. Its flash
header is configured for 4 MB to match the UPS hardware profile.

**Do not flash this fixture's generated partition table or bootloader onto a
provisioned UPS.** Preserve the original flash/partition data and install only
`build/web3pi_mqtt_loopback_test.bin` into an explicitly selected test slot. On
the tested UPS layout, OTA0 begins at `0x10000` and has size `0x180000`; verify the
actual device layout and binary size before using those values. Restore the
full firmware after qualification. Building this fixture never flashes a device.

The application runs once after boot and emits `CASE_RESULT` for every case,
followed by `FIXTURE_RESULT cases=8 failures=0 result=PASS`. Failure tests require
the intended delay and preconditions, so an immediate unrelated disconnect
does not count as a successful timeout test. Results include observed maximum
SDK mutex hold time, cancellation time, and independent observer-call duration.
Every case checks heap integrity after client destruction and reports free and
minimum free heap; TLS caches and task cleanup mean exact baseline equality is
not required.
These measurements cover the controlled loopback workload, not LTE performance
or a universal execution-time bound. The 10 ms service slice is a scheduling
budget; an individual cryptographic operation is not preempted at that limit.
The controlled fixture requires observed maximum lock hold at most 1000 ms,
independent observer calls at most 1000 microseconds, and stop completion below
500 ms. It does not establish a worst-case bound for arbitrary certificates or
workloads. A build or host test pass is not a device
qualification result.

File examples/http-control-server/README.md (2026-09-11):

# HTTP control-mode reference server

A tiny, dependency-free worked example for driving a Web3 Pi UPS from **your
own** infrastructure over HTTP — no EMQX, no Arkiv. This is the HTTP-2
deliverable of plan §4.18a; the interface it speaks is defined in
[`HTTP-1-design-note.md`](../../../web3pi_scope/milestones/M1/evidence/HTTP-1-design-note.md)
and implemented on the device in
[`firmware-ESP32-LTE-M/main/http_backend.c`](../../firmware-ESP32-LTE-M/main/http_backend.c).

## How it works

The UPS (ESP32-S3) is a pure HTTP **client**. On a fixed cadence (~30 s) it
makes one signed `POST` carrying telemetry; your server's **response** to that
POST carries any queued commands; the device dispatches them onto its in-board
bus and **acks** them on the next POST (an ack = dispatched, not executed — see
"What an ack means" below). Nothing connects *to* the device, so it works
behind the 1nce LTE-M carrier NAT exactly like the MQTT and Arkiv backends.

```
[ UPS / ESP32-S3 ] --outbound HTTP(S)--> [ your server ]
   telemetry up in the POST body
   commands down in the POST response
   acks up on the next POST
```

```
POST /api/v1/devices/{device_id}/telemetry
X-W3PUPS-Device: {device_id}
X-W3PUPS-Ts:     {unix_seconds}
X-W3PUPS-Nonce:  {random_hex}
X-W3PUPS-Sig:    hex(HMAC_SHA256(secret, Ts || Nonce || raw_body))
Content-Type:    application/json

{ "ts":…, "fw_ver":…, "uptime_s":…, "power":{…}, "host":{…}, "net":{…}, "acks":[…],
  "rejected":[{"id":…,"reason":…}], "resp_dropped":{"bytes":…,"max":2047} }   // last two optional, esp32:0.8.10+
```

Response:

```json
{ "commands": [ { "id": "c-0007", "cmd": "ui.beep", "args": { "freq_hz": 2000, "dur_ms": 200 } } ] }
```

**Both directions are authenticated** with **HMAC-SHA256**, keyed by the
device's **HTTP key** — a short code the device generates and shows on its OLED
(menu → HTTP Key), separate from the MQTT/Arkiv secret and re-rollable on the
device:

- **Request**: signed over `Ts || Nonce || raw_body`. The timestamp gives a
  ±300 s replay window and the nonce is remembered to reject exact replays.
- **Response**: the server signs `request_Nonce || raw_response_body` and
  returns it in the response `X-W3PUPS-Sig` header. The device verifies this
  before executing any command, so **commands can't be injected even over
  plain HTTP**.

Because of this, **TLS is optional** — it only adds confidentiality (hiding
telemetry contents on the wire). The simplest deployment is "run this on a VPS
and point the device at `http://<ip>:8080`". Add a domain + TLS later if you
want privacy (see below).

## Files

| File | What it is |
|---|---|
| [`server.py`](server.py) | The reference server. Verifies signatures, prints telemetry (incl. the per-cycle `Δtx`/`Δrx` byte readout), lets you enqueue commands from the terminal, returns them within the device's limits (`--max-commands`, ≤ 2047 B), clears them via acks, drops the ones the device reports as `rejected`, and expires any command not acked within `--cmd-max-age` seconds of being queued, delivered or not. |
| [`send_config.py`](send_config.py) | Run on the **RPi host**: points a fielded device at your server by sending a `net.config` frame over the serial link (no ESP32 re-flash). Needs pyserial (`sudo apt install -y python3-serial`). |
| [`test_client.py`](test_client.py) | Simulates a device POST (correct signature) so you can smoke-test the server — or a public TLS deployment — without hardware. |

## Quick start (no hardware)

```bash
# 1. pick a key (with real hardware this is the "HTTP Key" code shown on the
#    device OLED; for a dry run any string works as long as both sides match)
SECRET="ABCD EFGH JKLM NPQR"

# 2. start the server
python3 server.py --secret "$SECRET" --device-id TESTDEV --port 8080
#    (optional: --max-commands 8 --cmd-max-age 600 are the defaults — see
#     "Device limits" below; --cmd-max-age 0 keeps commands forever)

# 3. in another terminal, pretend to be the device
python3 test_client.py --secret "$SECRET" --device-id TESTDEV --url http://127.0.0.1:8080

# 4. back in the server terminal, type a command at the prompt:
> beep 2000 200
# the next POST from the device (or test_client) returns it; the one after,
# carrying acks, clears it.
```

## Supported commands

These map 1:1 onto the WUPS command frames the firmware already understands
(identical to what the web panel emits — see
`Web3-Pi-UPS-Panel/apps/api/src/lib/commands.ts`):

| Prompt | `cmd` / `args` | Effect |
|---|---|---|
| `beep [freq_hz] [dur_ms]` | `ui.beep` | Buzzer on the RP2040 — the easiest end-to-end proof a command landed. |
| `msg <text>` | `ui.display_msg {text}` | Show text on the OLED as a plain **info notice**: 40 visible chars (4 rows × 10 cols, `\n` breaks a row, no word wrap), one short chirp, 60 s, any button closes it. Needs `rp2040:1.2.2`+ — older RP2040 firmware showed it as the MODEM alarm banner. The ESP32 accepts up to 64 B of text; the rest is cut. |
| `shutdown [delay_s]` | `host.shutdown {delay_s}` | Shut down the Raspberry Pi (via the RPi agent). `delay_s` is currently **ignored** by the host service (immediate). |
| `reset [delay_s]` | `host.reset {delay_s}` | Reboot the Raspberry Pi. `delay_s` is currently **ignored** (immediate). |
| `powercycle [off_ms]` | `power.cycle {off_ms}` | Power-cycle the output (via CH32X). `off_ms` is accepted but the CH32X firmware currently always uses **1500 ms**. |

**What an ack means.** The device acks a command once it has dispatched the
corresponding WUPS frame onto its in-board bus (ESP32 → RP2040 → RPi host /
CH32X). It does **not** confirm execution — verify that out of band: hear the
beep, see the OLED, watch the `host` object disappear from the telemetry /
`host.uptime_s` reset after a shutdown or reboot (the spec, §5 "Verifying that
a command took effect", lists the per-command hints). Commands are
**idempotent by `id`**: if the device already applied an id (but the server
hadn't yet seen the ack), it re-acks without re-executing.

**Device limits** (`esp32:0.8.10`+, mirrored by `server.py`). The device
applies at most **8 commands per response**, drops a response body larger than
**2047 B** whole (and reports it back as `resp_dropped`), rejects command ids
longer than **47 chars**, and reports refused commands in a `rejected` list
(`unsupported_cmd` / `bad_args` / `bad_id`) — rejected ids are never acked, so
`server.py` drops them from its queue. It sends at most `--max-commands`
(default 8) commands per response and keeps the body under the cap (both caps
are off with `--max-commands 0`, which exists only to provoke the device's
overflow path), and it expires any command not acked within `--cmd-max-age`
seconds of being queued — delivered or not (default 600; 0 = never).
Full description: spec §4 "Command feedback", §5 "Receiver limits" and
"Server-side requirements" in
[`docs/http-control-mode.md`](../../docs/http-control-mode.md).

**Per-cycle data readout.** Each telemetry line prints the modem's cumulative
`bytes_tx` / `bytes_rx`; whenever a fresh sample arrives (the device refreshes
them every ~60 s, so not on every POST) the server adds
`Δtx=… Δrx=… B since previous net.status sample` — the on-wire cost of the
last cycle(s). Measured on the bench: plain `http://` at 30 s ≈ 1.6 KB per
cycle ≈ 4.7 MB/day. `https://` is **not measured** — estimated at several
times more (≈ 16–26 MB/day), because every POST opens a fresh TLS connection
with a full handshake. The bundled SIM is a 1NCE prepaid pool of 500 MB per
SIM or 10 years, whichever comes first — a lifetime allowance, not a monthly
quota — so see spec §9 before choosing TLS or a cadence.

## Pointing a real device at your server

1. **Get the HTTP key**: on the device, OLED menu → **HTTP Key**. Note the code
   (e.g. `ABCD EFGH JKLM NPQR`); start the server with it as `--secret`.
   (Re-roll anytime with **New key** — then update the server.)
2. **Set the URL** from the RPi (the device chooses its backend on the OLED
   menu: MQTT / Arkiv / **HTTP**; the URL can be set in any mode beforehand):

```bash
# on the Raspberry Pi attached to the UPS
sudo apt install -y python3-serial   # pyserial
python3 send_config.py --url http://<your-vps-ip>:8080   # or https://… if you added TLS
# the serial port is auto-detected (USB descriptor "Web3_Pi_UPS");
# `--list` shows candidates, `--port` overrides.
```

   **Note — the port is held by the `w3p-ups` service.** It owns the serial
   link, so stop it for the moment you run this, then start it again:
   ```bash
   sudo systemctl stop w3p-ups
   python3 send_config.py --url http://<your-vps-ip>:8080
   sudo systemctl start w3p-ups
   ```
   (Long-term this belongs as a `w3p-ups set-http-url` service subcommand — see
   the HTTP-2 evidence note.)

3. **Switch to HTTP mode** on the OLED (menu → Mode → HTTP). The device reboots
   into HTTP mode and starts posting within ~30 s.

The device appends `/api/v1/devices/{device_id}/telemetry` itself.
`device_id` defaults to the SIM ICCID; override it with
`send_config.py --device-id …` if your server keys devices differently.

For a bench/dev build you can instead bake a default into the firmware via
`HTTP_ENDPOINT_BASE` in `main/endpoints.h` — but the runtime `net.config`
value always wins.

## Optional: TLS

`server.py` speaks plain HTTP and that is a fine, secure-against-forgery setup
(both directions are HMAC-signed). Add TLS only if you want **confidentiality**
— i.e. to stop an on-path observer from *reading* your telemetry/commands.
Terminate it with any reverse proxy, e.g. Caddy (automatic Let's Encrypt):

```
ups.example.com {
    reverse_proxy 127.0.0.1:8080
}
```

…or nginx/Traefik with a Let's Encrypt cert. Keep the
`/api/v1/devices/{device_id}/telemetry` path intact, then point the device at
the `https://` URL. The certificate must be publicly trusted (the device
verifies against the Mozilla CA bundle with hostname checking — no self-signed
certs; an IP-literal `https://` URL needs an IP SAN), the URL must have no
trailing slash, and redirects are not followed — point the device at the final
URL. On the bundled SIM every `https://` POST costs a full TLS handshake
(spec §9 — a lifetime 500 MB pool, not a monthly quota), so prefer plain
`http://` there.

## Security notes (read before self-hosting)

- **Keep the HTTP key secret.** It authenticates *both* directions — anyone with
  it can forge telemetry and forge signed commands. It's shown on the OLED on
  request and re-rollable there; it's separate from the MQTT/Arkiv secret, so
  leaking it doesn't affect those backends.
- **Clock**: the device timestamps requests from network time (SNTP). If your
  server clock is wildly off, valid requests look stale — keep NTP running.
- **Nonce store** here is in-memory and per-process: a restart forgets recent
  nonces (a brief replay window). A production server should persist them (or a
  short-TTL store like Redis) and scope them per device.
- **One device, one secret** in this stub. A multi-device server looks the
  secret up by the `{device_id}` in the path / `X-W3PUPS-Device` header.
- This is an **example**, not hardened infrastructure. It has no auth on the
  command prompt, no persistence, and no rate limiting.

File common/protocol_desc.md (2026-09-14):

# Web3 Pi UPS — wire protocol v1

This document describes the binary protocol used between the four firmware
images of the UPS:

- **RPi 5** host service (`Web3-Pi-UPS-Service`, Rust)
- **RP2040** UI / hub firmware (`firmware-rp2040`)
- **CH32X035** power-path firmware (`firmware-ch32x`)
- **ESP32-S3** LTE-M / Arkiv firmware (`firmware-ESP32-LTE-M`)

The canonical machine-readable spec is [`protocol.h`](protocol.h). This file
is the human companion: structure, rationale, routing rules, examples.

## Topology

```
   +-------+   USB-CDC    +---------+   UART0    +--------+
   | RPi 5 | <----------> | RP2040  | <--------> | CH32X  |
   +-------+              |  (hub)  |            +--------+
                          |         |   UART1
                          |         | <-------> +---------+
                          +---------+           | ESP32-S3 |
                                                +---------+
```

RP2040 is the only node connected to all others. It acts as a router for
frames whose `DST` is not itself or a broadcast address.

## Frame format

```
+-----+-----+-----+-----+-------+----+-------+-----+-------+-------+
|0xAA |0x55 | DST | SRC | CLASS | OP | FLAGS | SEQ | LEN_L | LEN_H |
| 1B  | 1B  | 1B  | 1B  |  1B   | 1B |  1B   | 1B  |  1B   |  1B   |
+-----+-----+-----+-----+-------+----+-------+-----+-------+-------+
| payload  ...  LEN bytes (0..240)                                |
+-----------------------------------------------------------------+
| CK_A  | CK_B  | 0x55  | 0xAA  |
|  1B   |  1B   |  1B   |  1B   |
+-------+-------+-------+-------+
```

- **SYNC**: `0xAA 0x55`. Receiver scans for these to start frame parsing.
- **DST / SRC**: see address table below.
- **CLASS / OP**: dispatch keys (e.g. `power.status` = `0x02 0x01`).
- **FLAGS** bitmap:
  - bit 0 `REQ` — request expecting a RESP.
  - bit 1 `RESP` — response. `SEQ` echoes the originating REQ's `SEQ`.
  - bit 2 `EVENT` — unsolicited (periodic status or change event).
  - bit 7 `NEED_ACK` — reserved, no implementation in v1.
- **SEQ**: u8 incrementing counter, scoped per (`SRC`, `DST`). Wraps at 256.
  RESP must echo the REQ's SEQ for correlation.
- **LEN**: u16 little-endian payload length. `0 ≤ LEN ≤ 240`.
- **PAYLOAD**: `LEN` bytes. First byte is conventionally a `version` field
  (matches the v1 suffix on every struct in `protocol.h`).
- **CK_A / CK_B**: Fletcher-8 over `DST..LEN_H..payload[LEN-1]`. Same algo
  as u-blox UBX. SYNC and end marker are NOT covered.
- **End marker**: `0x55 0xAA`. Aids resynchronization after corruption.
- **Guard byte (byte streams only, since 2026-09)**: senders on UART / USB-CDC
  emit one `0x00` (`WUPS_GUARD_BYTE`) after the end marker. It is NOT part of
  the frame (never stored, never relayed inside MQTT payloads or Arkiv
  entities, not covered by the checksum); receivers drop it while hunting
  for SYNC. Rationale below ("Receive state machine").

Total frame size = `14 + LEN` bytes. Max frame = 254 bytes (+1 guard byte on the wire).

## Endianness and alignment

- All multi-byte fields are **little-endian**.
- All four targets are little-endian, so direct struct overlay is byte-correct.
- However, payload buffers are not guaranteed to be aligned, and CH32X
  (Cortex-M0) and RP2040 (Cortex-M0+) **fault on unaligned word access**.
  Always copy structs in/out of the payload buffer with `memcpy`. All structs
  in `protocol.h` are `__attribute__((packed))` as belt-and-suspenders.

## Addresses

| Value | Name | Meaning |
|---|---|---|
| 0x00  | NULL | Unused. Frames with DST=NULL must be dropped. |
| 0x01  | RPI | Raspberry Pi 5 (host service over USB-CDC). |
| 0x02  | RP2040 | UI / hub controller. |
| 0x03  | CH32X | Power path / PD output controller. |
| 0x04  | ESP32 | M.2 LTE-M card (or current devkit T-SIM7080G-S3). |
| 0x05  | INTERNAL  | Multicast to all MCUs **but not** RPi. |
| 0xFF  | BROADCAST | Multicast to all nodes including RPi. |

### Routing rules (RP2040 hub)

For an incoming frame on port `P`:

1. If `DST == self` (RP2040): consume.
2. If `DST == 0xFF` (BROADCAST): consume **and** retransmit on every other
   port (USB-CDC, UART0, UART1) except `P`.
3. If `DST == 0x05` (INTERNAL): consume **and** retransmit on every MCU
   port except `P`. Never forward to USB-CDC.
4. Otherwise: forward on the single port mapped to `DST` (table below).
   If port unknown, drop and emit `system.log` with level=warn.

| Address | Port |
|---|---|
| RPI | USB-CDC (Serial) |
| CH32X | UART0 (GPIO16/17)  |
| ESP32 | UART1 (GPIO4/5) |

Loop prevention: a hub never retransmits a broadcast/internal back on the
port it arrived from. With a star topology this rule is sufficient (no
cycles possible).

## Versioning

- `WUPS_PROTO_VERSION = 1` is the global protocol version. Every node sends
  its `proto_version` in `system.hello` on boot. A mismatch is logged and the
  remote is treated as offline.
- Each payload struct has a `version u8` first byte. New fields are appended
  to a new versioned struct (`_v2_t`). Receivers may accept v1 with reduced
  data while a rolling upgrade is in progress.
- Capabilities are advertised in `system.hello.caps_classes` (u16 bitmap).
  Bit `N` set means the sender implements class `N`.

## Class / Op catalogue

### Class 0x01 SYSTEM (every node)

| Op | Name | Direction | Payload struct |
|---|---|---|---|
| 0x01 | ping | REQ ↔, RESP ← | empty / `wups_sys_pong_v1_t`  |
| 0x02 | hello | EVENT (broadcast)  | `wups_sys_hello_v1_t` |
| 0x03 | status_query | REQ | empty |
| 0x04 | log | EVENT | `wups_sys_log_v1_hdr_t` + ASCII text |
| 0x05 | reset | REQ ↔, RESP ← | `wups_sys_reset_v1_t` (optional) / 1 result byte |

### Class 0x02 POWER (CH32X)

| Op | Name | Direction | Payload struct |
|---|---|---|---|
| 0x01 | status | EVENT (CH32X→RP2040 @1Hz), RESP on query | `wups_power_status_v2_t` (was `_v1_t`) |
| 0x02 | enable | REQ | empty |
| 0x03 | disable | REQ | empty |
| 0x04 | cycle | REQ | `wups_power_cycle_v1_t` |
| 0x05 | reset | REQ | empty |
| 0x10 | event | EVENT (broadcast) | `wups_power_event_v1_t` |

CH32X emits `power.status` autonomously every 1 s, **unicast to RP2040**.
RP2040 caches the latest sample and includes the data in its own
`host.aggregate` frames sent to RPi.

Since 2026-06: the payload is **`wups_power_status_v2_t` (version byte = 2,
40 bytes)** — a redesign, not a v1 superset, so every receiver dispatches on
the version byte (offset 0): `1` → `wups_power_status_v1_t` (legacy), `2` →
`wups_power_status_v2_t`. v2 adds separate INPUT (HUSB238) and OUTPUT PD
contracts, real `vsys_mV`/`iin_mA` (v1 aliased these onto `pd_contract_*`),
split LM75B/MP2762A temperatures, and a packed `flags` byte. Roll-out order:
make all readers version-tolerant (RPi host, RP2040) **before** the CH32X
emitter flips to v2; the RP2040 hub must forward the raw payload length, not
`sizeof(v1)`. ESP32 is a transparent forwarder (v2 ≤ 64 B, no change).

### Class 0x03 NET (ESP32)

| Op | Name | Direction | Payload struct |
|---|---|---|---|
| 0x01 | status | EVENT (ESP32→RP2040), RESP | `wups_net_status_v1_t` / `v2_t` / `v3_t` |
| 0x02 | publish | REQ → ESP32 | `wups_net_publish_v1_hdr_t`  |
| 0x10 | downlink | EVENT → destination | `wups_net_downlink_v1_hdr_t` |
| 0x20 | time_sync | EVENT (INTERNAL broadcast) | `wups_net_time_sync_v1_t` |

ESP32 is a dumb pipe: it never inspects payloads of `net.publish` (the
caller composes whatever bytes go to MQTT). It forwards `net.downlink` to
whichever address the cloud directed (typically `RPI`).

`net.status` v3 is 31 bytes: the 20-byte v1 prefix and 10-byte v2 sys-link
tail keep their offsets, with `sinr_dB` (`int8_t`) appended at offset 30.
The version byte is `3`; `-128` means unknown and **0 dB is valid**.
SIM7080G `AT+CPSI?` reports RSSNR codes `0..25`, converted as
`SINR = 2 * RSSNR - 20` dB (`-20..30`). Readers of older v1/v2 payloads must
treat SINR as absent; invalid/missing CPSI fields are never converted to 0.

### Class 0x04 HOST (RPi)

| Op | Name | Direction | Payload struct |
|---|---|---|---|
| 0x01 | status | EVENT (RPi→RP2040 @5s), RESP | `wups_host_status_v1_t` |
| 0x02 | shutdown | REQ | `wups_host_shutdown_v1_t` |
| 0x03 | reset | REQ | `wups_host_shutdown_v1_t` |
| 0x04 | service_restart  | REQ | `wups_host_service_restart_v1_hdr_t` + unit name |
| 0x10 | event | EVENT (broadcast) | `wups_host_event_v1_t` |

`host.service_restart` carries a target systemd unit name (without `.service`
suffix). The agent on the RPi enforces a whitelist configured locally; units
not on the whitelist are rejected. A master `allow_service_restart` switch in
the agent's config disables the op entirely.

### Class 0x05 UI (RP2040)

| Op | Name | Direction | Payload struct |
|---|---|---|---|
| 0x01 | button_event | EVENT (broadcast) | `wups_ui_button_event_v1_t` |
| 0x02 | set_screen | REQ | `wups_ui_set_screen_v1_t` |
| 0x03 | beep | REQ | `wups_ui_beep_v1_t` |
| 0x04 | display_msg | REQ | `wups_ui_display_msg_v1_hdr_t` + text |

`ui.display_msg` rendering depends on the frame's `SRC` (since rp2040:1.2.2):
from the ESP32 (modem supervisor / OTA) it is the persistent **MODEM** alert
banner with buzzer (text ≤ 23 chars; the OTA text `FW UPDATE` is shown
without the "no uplink" line and without buzzer); from any other source (RPi host service,
HTTP or MQTT downlink — `SRC = 0x01` RPI) it is a plain info notice: 40 visible
chars (4 rows × 10 cols, `\n` breaks a row — no word wrap, so put `\n` in the
text for word-aligned rows), 60 s TTL, no alarm (one short chirp when it first
becomes visible), any button press closes it. `text_len == 0` clears only the
sender's own layer (an HTTP operator cannot clear the modem banner). `line`
and `reserved` are reserved for future use: senders should send 0, receivers
ignore any value today.

## Example: RPi pings CH32X

RPi composes:

```
SYNC=AA 55  DST=03  SRC=01  CLASS=01  OP=01  FLAGS=01  SEQ=42
LEN=00 00   payload=(empty)   CK_A=??  CK_B=??   END=55 AA
```

Flow:
1. RPi writes 14 bytes to USB-CDC.
2. RP2040 deframes; `DST=0x03` → forwards on UART0.
3. CH32X deframes, dispatches `system.ping` REQ.
4. CH32X composes RESP with `FLAGS=0x02`, `SEQ=42`, payload =
   `wups_sys_pong_v1_t{version:1, fw_version:0x0103, uptime_ms:12345}`.
5. RP2040 sees `DST=0x01` (RPI) → forwards on USB-CDC.
6. RPi correlates by `SEQ=42`.

## Example: CH32X periodic status

Every 1 s CH32X emits unicast to RP2040:

```
DST=02  SRC=03  CLASS=02  OP=01  FLAGS=04  SEQ=auto
LEN=28 00  payload=wups_power_status_v2_t (40 B)   # v1 was 20 B (LEN=14 00)
```

RP2040 caches it. RP2040's own `host.status`-equivalent frame to RPi
includes the latest power snapshot via the aggregator (see RP2040 firmware).

## Example: power loss broadcast

CH32X detects mains drop:

```
DST=FF  SRC=03  CLASS=02  OP=10  FLAGS=04  SEQ=auto
LEN=02 00  payload={version:1, event:1 (MAINS_LOST)}
```

RP2040 retransmits to USB-CDC and UART1. Every node reacts:
- RP2040: switches OLED to "ON BATTERY", short beep.
- RPi: starts shutdown timer.
- ESP32: composes a `net.publish` next cycle with low-battery topic.

## Receive state machine (sketch)

```
state = SYNC1
loop:
  byte = uart_read()
  switch state:
    SYNC1: state = (byte == 0xAA) ? SYNC2 : SYNC1
    SYNC2: state = (byte == 0x55) ? HEADER_DST : RESET_WITH(byte)
    HEADER_DST..HEADER_LEN_H: accumulate; after LEN_H known, state = PAYLOAD
                              (LEN > 240 -> RESET_WITH(byte))
    PAYLOAD: accumulate LEN bytes
    CK_A: store; state = CK_B
    CK_B: validate Fletcher-8 over header+payload; on mismatch -> RESET_WITH(byte)
    END1: state = (byte == 0x55) ? END2 : RESET_WITH(byte)
    END2: if byte == 0xAA -> deliver frame, state = SYNC1; else RESET_WITH(byte)

  RESET_WITH(byte): state = (byte == 0xAA) ? SYNC2 : SYNC1
```

**`RESET_WITH` is load-bearing (2026-09-07 field incident).** `END2` and
`SYNC1` are both `0xAA`. A receiver that lost sync mid-frame scans that
frame's tail, takes `END2` for `SYNC1`, and then sees the REAL `SYNC1` of the
next frame where it expects `SYNC2`. A naive `-> SYNC1` reset there discards
the real `SYNC1`, the real `SYNC2` is then skipped in `SYNC1` state, the whole
next frame is lost and the collision repeats at its end — the deframer stays
exactly one frame behind **forever**. The only thing it can still lock onto is
an `AA 55` inside a payload — and every `net.publish` carries a complete inner
frame, so the ESP32 kept decoding (and ignoring) inner `power.status` frames
for days while no wrapper ever reached MQTT. Re-evaluating the failed byte as
a `SYNC1` candidate re-locks on the very next `SYNC2`.

Two further, independent safeguards:

- **Guard byte on the wire** (see frame format): lets a receiver still running
  the naive deframer (e.g. a CH32X that cannot be updated remotely) burn its
  bogus `SYNC2` check on the guard and re-lock on the next frame.
- **Idle reset**: a frame is at most 254 B = 2.8 ms at 921600 baud. A receiver
  that is mid-frame and sees no byte for ~50 ms resets to `SYNC1` — the frame
  can no longer complete (peer reset, overflow).

The end marker plus checksum makes a false-positive deframe extremely
unlikely.

## Limits & timeouts

- **Max payload**: 240 B (`WUPS_MAX_PAYLOAD`). Sized to fit in CH32X's
  256 B circular DMA RX buffer with header overhead.
- **Frame timeout**: receiver should reset to `SYNC1` if no byte arrives
  within 100 ms after starting a frame.
- **REQ timeout**: caller waits 1 s for RESP, then retries up to 3× before
  declaring the destination dead.
- **Retransmission**: not implemented in v1. Every link is reliable enough
  (USB-CDC, UART direct). If we observe loss in production, we add it via
  `NEED_ACK` flag.

## Future v2 considerations (not implemented)

- `NEED_ACK` flag with separate `system.ack` op.
- Encryption between RPi and ESP32 only (cloud-bound payloads).
- OTA fragmentation (class 0x06 `update`).
- Capability negotiation (REQ/RESP) replacing the hello-only advertisement.

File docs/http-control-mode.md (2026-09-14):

# HTTP control mode — specification & self-hosting guide (DOC-HTTP)

Deliverable **DOC-HTTP** (plan §4.17). Companion to the HTTP-1 design note
([`../../web3pi_scope/milestones/M1/evidence/HTTP-1-design-note.md`](../../web3pi_scope/milestones/M1/evidence/HTTP-1-design-note.md))
and the working example HTTP-2. This is the normative description of what the
firmware sends and expects; the reference server lives in
[`../examples/http-control-server/`](../examples/http-control-server/).

> **What this is for.** A worked example for users who want to drive the UPS
> from their **own** infrastructure — no EMQX, no Arkiv. It is one of the
> three runtime-selectable backend modes (ADR-0012): MQTT, Arkiv, **HTTP**.

## 1. Model

The UPS (ESP32-S3) is a pure HTTP **client**. It makes outbound requests only,
so it works behind the 1nce LTE-M carrier-grade NAT exactly like the MQTT and
Arkiv backends — no inbound reachability, no public IP, no VPN needed on the
device side.

```
[ UPS / ESP32-S3 ]  --outbound HTTP(S)-->  [ your server (public IP) ]
   telemetry  : up   in the POST body
   commands   : down in the POST response
   acks       : up   on the next POST
```

Commands are delivered by **polling**: they ride in the HTTP response to the
device's periodic telemetry POST (~30 s cadence). There is no server push and
no long-poll — this keeps the radio idle between posts. Command latency is
therefore up to one cadence interval (~30 s); this is a control channel for
shutdown/reset/beep-class actions, not a real-time link.

The bundled SIM is a **1NCE prepaid pool: 500 MB per SIM or 10 years from
activation, whichever comes first** (top-up is possible via the 1NCE portal,
i.e. by Web3 Pi — not by the end user). That is a **lifetime allowance, not a
monthly quota**, and every poll cycle spends part of it — see §9 for the
measured cost per cycle and how to budget it.

## 2. Endpoint

```
POST  {base}/api/v1/devices/{device_id}/telemetry
```

- `{base}` is the operator-supplied URL (see §6 for how it is configured).
  The device appends the rest of the path.
- `{device_id}` defaults to the SIM **ICCID**; it can be overridden (§6).
- A single endpoint carries both directions: telemetry up in the request,
  commands down in the response, acks up on the following request.

## 3. Authentication

**Both directions are HMAC-SHA256 signed** with the per-device secret, so
neither telemetry nor commands can be forged or injected — independently of the
transport. There is no bearer token; the secret never crosses the wire. **TLS
is therefore optional** (it adds confidentiality only — see §8).

> This supersedes the HTTP-1 design note's "TLS mandatory": the command channel
> is secured by the **response signature** below, not by TLS.

### Request signature (device → server)

| Header | Value |
|---|---|
| `X-W3PUPS-Device` | the `device_id` |
| `X-W3PUPS-Ts` | request time, unix seconds (ASCII decimal) |
| `X-W3PUPS-Nonce` | 8 random bytes, lower-case hex (16 chars) |
| `X-W3PUPS-Sig` | `hex( HMAC_SHA256( secret, Ts ‖ Nonce ‖ raw_body ) )` |

- **Signed input** is the byte concatenation of the ASCII `X-W3PUPS-Ts`
  string, the ASCII `X-W3PUPS-Nonce` string, and the **raw request body bytes**
  — in that order. Signature is lower-case hex.
- The server should reject a stale `Ts` (e.g. ±300 s skew) and a
  recently-seen `Nonce` (replay protection).

### Response signature (server → device)

The server signs its response so the device can trust the commands it returns:

| Response header | Value |
|---|---|
| `X-W3PUPS-Sig` | `hex( HMAC_SHA256( secret, request_Nonce ‖ raw_response_body ) )` |

- Binding to the **request nonce** ties the response to that exact request, so
  a captured-and-replayed old response is rejected.
- The device **verifies this before executing any command**. A response that
  carries commands but is missing/invalid-signed is ignored (fail-closed); a
  response with no commands needs no signature.
- This means a network attacker on a plain-HTTP path **cannot inject
  commands** — they don't have the secret.

### Key — the "HTTP key" shown on the OLED

The key for both signatures is a **dedicated HTTP-mode secret**, separate from
the MQTT/Arkiv per-device secret. The device **generates it itself** on first
use and shows it on the OLED (menu → **HTTP Key**); you can re-roll it from the
same menu (**New key**). So a self-hoster never has to extract a factory secret
— they just read the code off the screen.

- Format: 16 characters of Crockford base32 (≈80 bits), shown as two groups of
  8, e.g. `ABCD EFGH JKLM NPQR`.
- The HMAC key is the **ASCII bytes of the code**, normalised to upper-case with
  any spaces/dashes removed. Type it into the server exactly as shown; case and
  separators don't matter (the reference server normalises it the same way).
- Stored in the device's writable `nvs` (`w3http/secret`); survives reboots and
  mode switches; cleared by a factory reset (a new one is generated next time).
- Re-rolling it on the OLED invalidates the old code immediately — update your
  server's `--secret` to match.

Server responses (what the device does with each status):

| Status | Device behaviour |
|---|---|
| `2xx` | accepted: the carried `acks` / `rejected` / `resp_dropped` are dropped from the device, then the returned commands are applied (subject to the receiver limits in §5). Counts as "uplink alive" for the modem watchdog even when the body is over-size and dropped (§4). |
| `3xx` | **not followed** (`disable_auto_redirect`, since `esp32:0.8.10`): nothing applied, nothing dropped. Device log: `redirect N not followed — point the device at the final URL`. Configure the final URL (§6). |
| `401` | signature/identity rejected; nothing dropped, retried next cadence. The reference server sends no `WWW-Authenticate`, so `esp_http_client` fails before the body is read and the device log shows `POST failed: ESP_ERR_NOT_SUPPORTED (HTTP 401, url=…)` followed by `401 — signature/identity rejected`. The *reason* (bad signature / bad or stale timestamp / replayed nonce) is printed only on the **server** console — the device never sees the 401 body. |
| other `4xx`/`5xx` | nothing dropped, retried next cadence. Device log: `server answered N — nothing dropped, retried next cadence`. No backoff escalation. |
| timeout / no response | per-socket timeout 20 s (`HTTP_TIMEOUT_MS`); device log `POST failed: <esp_err> (no response, url=…)`; nothing dropped, retried next cadence. |

Carried `acks`, `rejected` and `resp_dropped` are removed from the device only
after a `2xx`; a failed POST keeps them for the next poll (bench-verified:
server port blocked for 58 s → `POST failed: ESP_ERR_HTTP_CONNECT (no
response)` → the next POST carried the same 8 acks).

**Uplink watchdog (modem supervisor, `esp32:0.8.7`+).** "Uplink alive" above
refers to the modem supervisor in `firmware-ESP32-LTE-M/main/modem.c`: in HTTP
mode the uplink counts as healthy while the last `2xx` is ≤ 90 s old
(`HTTP_UPLINK_FRESH_SECS`); only a `2xx` refreshes it — a `3xx`, `401`, other
non-2xx or a timeout does not. Once it has been unhealthy for 300 s
(`UPLINK_DEAD_SECS`, i.e. ≈ 6.5 min after the last `2xx`, quantised to the
30 s supervise tick) the firmware first probes the internet (DNS to 1.1.1.1 /
8.8.8.8). If the probes answer, the server is the problem (down, wrong URL,
wrong key) and the firmware **holds** — no modem reset; after 1800 s in that
state (`UPLINK_HOLD_ALERT_S`, ≈ 31 min after the last `2xx`) it raises the
OLED alert `! MODEM / NO UPLINK / no uplink` with the buzzer. Only when the
probes fail too is the cellular link torn down and re-established (escalating
to a modem power-cycle on repeated trips). Both the hold and the alert clear on
the next `2xx`.

## 4. Request body (device → server)

`Content-Type: application/json`. Sub-objects appear only when that telemetry
class has a **fresh** snapshot (observed within ~90 s); otherwise they are
omitted rather than sent stale.

Body as sent by `esp32:0.8.9` with a CH32X that emits `power.status` v2 (the
production case). The `power` object is from a real unit on 15 V USB-C mains
with a full battery and the Pi rail up; the remaining objects are illustrative.
Since `esp32:0.8.10` the body may additionally carry the optional `rejected`
and `resp_dropped` fields next to `acks` — see "Command feedback" at the end
of this section:

```json
{
  "ts": 1780047458,
  "fw_ver": "esp32:0.8.9",
  "uptime_s": 137,
  "power": {
    "version": 2, "flags": 31, "charge_state": 3,
    "vbus_in_mv": 14709, "pd_in_mv": 15000, "pd_in_ma": 1750,
    "vbus_out_mv": 5051, "vout_set_mv": 5000, "vout_read_mv": 5046,
    "iout_limit_ma": 5010, "pd_out_mv": 5000, "pd_out_ma": 3000,
    "vbat_mv": 7897, "ibat_ma": 0,
    "vsys_mv": 7900, "iin_ma": 1200,
    "temp_lm_dc": 350, "temp_mp_dc": 440, "temp_dc": 440,
    "faults": 0, "uptime_s": 86272
  },
  "host": {
    "eth_state": 2, "cpu_temp_dc": 451,
    "mem_pct": 40, "disk_pct": 55, "load_x100": 120, "uptime_s": 99999
  },
  "net": {
    "state": 4, "rssi_dbm": -71, "rsrp_dbm": -98, "rsrq_db": -11,
    "bytes_tx": 12345, "bytes_rx": 67890
  },
  "acks": ["c-0042"]
}
```

**Legacy v1 shape** — no `version` key, the eight original keys (`ibus_out_ma`
and `ibat_ma` are signed). It appears only for units whose CH32X still emits
`power.status` v1:

```json
"power": {
  "charge_state": 1,
  "vbus_in_mv": 5012, "vbus_out_mv": 5050, "ibus_out_ma": 1840,
  "vbat_mv": 7920, "ibat_ma": -200, "temp_dc": 253, "faults": 0
}
```

> **Since `esp32:0.8.9`.** Earlier firmware decoded every `power.status`
> payload through the v1 struct, so a v2-emitting CH32X produced the 8 legacy
> keys with scrambled values (`temp_dc` was really `vout_set_mv`, `faults` was
> `pd_out_mv`, `charge_state` was `flags`) — GitHub issue #7. Servers should
> dispatch on `power.version` to tell the two shapes apart.

Field origins map directly onto the WUPS telemetry structs in
[`../common/protocol.h`](../common/protocol.h). The device dispatches on the
wire version byte (offset 0 of the payload): `power.version == 2` ↔
`wups_power_status_v2_t` (40 B); no `version` key ↔ `wups_power_status_v1_t`
(20 B); any other version byte, or a payload shorter than its struct → the
`power` object is omitted and the device logs one warning per boot. `host.*` ← `wups_host_status_v1_t`, `net.*` ←
`wups_net_status_v1_t` (`net.bytes_tx` / `net.bytes_rx` are the modem's
cumulative PPP byte counters, refreshed every ~60 s, so consecutive POSTs may
repeat a sample — §9 uses them to measure the on-wire cost). Units are as named: `*_mv` millivolts, `*_ma`
milliamps (signed where noted), `*_dc` deci-Celsius (253 = 25.3 °C), `*_pct`
percent, `load_x100` = 1-min load × 100, `*_s` seconds.

`net.status` v3 additionally supplies optional `net.sinr_db` in dB (`-20..30`,
including `0`). It is omitted for v1/v2 telemetry or an unavailable/invalid
measurement; the binary `-128` sentinel is never emitted as a JSON reading.
The v1-prefix network fields above keep their existing names and meaning.

`power` v2 keys (since `esp32:0.8.9`), in emission order:

| key | unit | wire field | note |
|---|---|---|---|
| `version` | — | `version` | always `2` for this shape |
| `flags` | bitmask | `flags` | see legend below |
| `charge_state` | enum | `charge_state` | see legend below |
| `vbus_in_mv` | mV | `vbus_in_mV` | input rail after the ideal-diode OR of USB-C and barrel |
| `pd_in_mv` | mV | `pd_in_mV` | negotiated INPUT PD contract (HUSB238); `0` = no contract |
| `pd_in_ma` | mA | `pd_in_mA` | negotiated INPUT PD contract; `0` = no contract |
| `vbus_out_mv` | mV | `vbus_out_mV` | independent ADC measurement of the Pi rail |
| `vout_set_mv` | mV | `vout_set_mV` | TPS55289 commanded output voltage |
| `vout_read_mv` | mV | `vout_read_mV` | TPS55289 output voltage readback |
| `iout_limit_ma` | mA | `iout_limit_mA` | TPS55289 current **limit** — not a load-current measurement |
| `pd_out_mv` | mV | `pd_out_mV` | OUTPUT PD contract to the Pi; `0` = rail off |
| `pd_out_ma` | mA | `pd_out_mA` | OUTPUT PD contract to the Pi; `0` = rail off |
| `vbat_mv` | mV | `vbat_mV` | battery voltage (authoritative ADC) |
| `ibat_ma` | mA, signed | `ichg_mA` | MP2762A **charge** current; `0` on discharge (not measured) |
| `vsys_mv` | mV | `vsys_mV` | MP2762A VSYS rail (feeds the TPS55289) |
| `iin_ma` | mA | `iin_mA` | MP2762A charger input current |
| `temp_lm_dc` | 0.1 °C, signed | `temp_lm_dC` | LM75B board temperature |
| `temp_mp_dc` | 0.1 °C, signed, or `null` | `temp_mp_dC` | MP2762A junction temperature; `null` when the charger is unpowered (wire sentinel −32768) |
| `temp_dc` | 0.1 °C, signed | derived | aggregate: `max(temp_mp_dc, temp_lm_dc)`, or `temp_lm_dc` when `temp_mp_dc` is `null` — same rule as the OLED, the host service and the Workbench |
| `faults` | bitmask | `faults` | see legend below |
| `uptime_s` | s | `uptime_s` | CH32X uptime (restart detection) — distinct from the top-level ESP32 `uptime_s` |

Legends:

- `flags` bits: 0 `DC_IN_EN` (input path enabled), 1 `VBUS_OUT_EN` (Pi rail
  enabled), 2 `BATT_PRESENT`, 3 `POWER_GOOD` (charger ACOK, mains good),
  4 `USB_C_ATTACH` (HUSB238 PD contract present). Bits 5-7 are currently
  unused (0).
  The example's `31` = all five set.
- `charge_state`: 0 not charging, 1 pre-charge (trickle), 2 fast charge,
  3 charge done. Faults are never signalled here — see `faults`.
- `faults` (identical layout in v1 and v2): low byte = MP2762A REG14H fault
  register; bit 8 = TPS55289 SCP, bit 9 = OCP, bit 10 = OVP. `0` = no fault.
- `temp_dc`: the higher of the two sensors; falls back to `temp_lm_dc` when
  the MP2762A is unpowered (`temp_mp_dc` is `null`, e.g. battery-only
  operation).
- There is **no `ibus_out_ma` in v2** — the board has no load-current
  measurement. `iout_limit_ma` is the converter's current *limit*; `ibat_ma`
  is the *charge* current and reads `0` while discharging.

### Command feedback: `acks`, `rejected`, `resp_dropped`

`acks` lists the `id`s of commands the device **dispatched** since its previous
successful POST (empty array if none).

**Ack semantics (normative).** An ack means the ESP32 has verified the
response signature, translated the command into its WUPS frame and dispatched
that frame onto the in-board bus (`net.downlink` to the RP2040, which routes it
on to the RP2040 itself, the Raspberry Pi host service or the CH32X). An ack
does **not** confirm execution: the ESP32 does not wait for the RP2040 / host /
CH32X command RESP, so a frame that is dropped downstream (e.g. `host.*` while
the Pi service is not running) is still acked. Execution is verified **out of
band** — physically or from later telemetry — see §5 "Verifying that a command
took effect". Using the cmd RESP frames on the bus for an "executed / failed"
report is a documented future extension point, not implemented.

Acks are carried until a POST gets a `2xx`; a failed POST keeps them for the
next one (§3). The pending list holds 8 ids (`ACK_PENDING_MAX`) — exactly the
per-response cap, so since `0.8.10` it cannot overflow: a `2xx` drains every
ack the body carried *before* the response is applied, and applying a response
adds at most 8 (§5). `ack_add()` keeps a defensive oldest-evict for that
impossible case (the server would re-send the command and the device would
re-ack it from its dedup ring without re-executing it).

`rejected` (since `esp32:0.8.10`) — present only when non-empty — lists
commands the device **refused** since its previous successful POST:

```json
"rejected": [ { "id": "c-0044", "reason": "unsupported_cmd" } ]
```

| `reason` | Meaning |
|---|---|
| `bad_id` | `id` missing, not a JSON string, empty, or longer than 47 chars. The first 47 chars are echoed when present; an over-long id is **never** truncated into a different id. (Before `0.8.10` ids were cut to 31 chars, so a 36-char UUID was re-executed every cadence.) |
| `unsupported_cmd` | `cmd` is not one of the five names in §5. (Before `0.8.10` unknown names were only logged.) |
| `bad_args` | `cmd` is not a JSON string, or the payload could not be encoded. |

At most 4 entries are carried per POST (`REJ_MAX`; the oldest are dropped),
deduplicated by id — e.g. every entry without an id collapses into a single
`{"id":"","reason":"bad_id"}` report carrying the last reason seen.
**Rejected ids are never acked** — the server must drop them from its queue,
or they are rejected again on every poll.

`resp_dropped` (since `esp32:0.8.10`) — present only after a `2xx` response
whose body exceeded 2047 B (`HTTP_RESP_MAX` − 1). The body was counted, dropped
**whole** (no commands applied, one warning logged) and is reported once:

```json
"resp_dropped": { "bytes": 2310, "max": 2047 }
```

Such a `2xx` still counts as "uplink alive" for the modem watchdog. Before
`0.8.10` an over-size body was silently truncated, failed to parse, produced no
acks and made the server re-send it forever. Treat `resp_dropped` as a bug on
the server side (see §5 "Server-side requirements").

Like `acks`, both fields are cleared from the device only once the POST
carrying them receives a `2xx`.

A body with all three feedback fields (`esp32:0.8.10`; the telemetry objects
are elided here — their content is exactly as in the first example):

```json
{
  "ts": 1780047488,
  "fw_ver": "esp32:0.8.10",
  "uptime_s": 167,
  "power": { "version": 2, "…": "…" },
  "host":  { "…": "…" },
  "net":   { "…": "…" },
  "acks": ["c-0042", "c-0043"],
  "rejected": [
    { "id": "c-0044", "reason": "unsupported_cmd" },
    { "id": "0f8e7d6c-5b4a-4c3d-9e2f-1a0b9c8d7e6f-extra-long", "reason": "bad_id" }
  ],
  "resp_dropped": { "bytes": 2310, "max": 2047 }
}
```

(The second rejected entry shows a 54-char id echoed as its first 47 chars.)

## 5. Response body (server → device)

```json
{
  "commands": [
    { "id": "c-0043", "cmd": "ui.beep", "args": { "freq_hz": 2000, "dur_ms": 200 } }
  ]
}
```

- `{ "commands": [] }` (or any 2xx with no `commands`) means "nothing queued".
- A response **carrying commands must be signed** (`X-W3PUPS-Sig`, §3); the
  device drops the commands otherwise.
- Commands are **idempotent by `id`**: a server that hasn't seen an ack
  re-sends the command; the device re-acks but does **not** re-execute an `id`
  it already applied. The dedup ring holds the last 16 executed ids
  (`EXEC_RING_MAX`) in RAM — it is lost on an ESP32 reboot.
- The device applies **at most 8 commands per response** and reads **at most
  2047 B** of response body — see "Receiver limits" below (since
  `esp32:0.8.10`).

Each `commands[]` entry is checked in this order (since `esp32:0.8.10`):
`id` invalid → `rejected: bad_id`; id already executed → re-ack, skip; `cmd`
not a string → `bad_args`; unknown name → `unsupported_cmd`; payload encode
failure → `bad_args`; otherwise dispatched → executed + acked (§4).

### Command surface

The `cmd` names map 1:1 onto WUPS frames (identical to what the web panel emits
— `Web3-Pi-UPS-Panel/apps/api/src/lib/commands.ts`), so the ESP32 introduces
no new control semantics: it just translates JSON → the existing frame.

| `cmd` | `args` | WUPS class.op | Target | Notes |
|---|---|---|---|---|
| `ui.beep` | `freq_hz`, `dur_ms` (both optional; clamped to 0..65535 by the ESP32; `0` ⇒ RP2040 default 1500 Hz / 150 ms; the RP2040 clamps `dur_ms` to ≤ 5000) | UI 0x05 / 0x03 | RP2040 | best end-to-end "it landed" proof; silent when the unit is muted in the OLED menu |
| `ui.display_msg` | `text` — accepted up to 64 B by the ESP32; the RP2040 shows the first **40 chars** as 4 rows × 10 cols (`\n` breaks a row, no word wrap, DEL / non-ASCII drawn as `?`). `line` is reserved — send `0`, ignored | UI 0x05 / 0x04 | RP2040 | since `rp2040:1.2.2` rendered as a plain **info notice**: no "MODEM" banner, no alarm, one short chirp when first drawn, 60 s TTL, any button closes it. On `rp2040` ≤ 1.2.1 it rendered as the MODEM alarm banner with the alarm sound |
| `host.shutdown` | `delay_s` (default 5; **currently ignored** by the Raspberry Pi host service, which shuts down immediately) | HOST 0x04 / 0x02 | RPi (via RP2040) | reason = remote_cmd |
| `host.reset` | `delay_s` (default 5; **currently ignored** — the host service reboots immediately) | HOST 0x04 / 0x03 | RPi (via RP2040) | reboot |
| `power.cycle` | `off_ms` (default 1500, clamped to ≤ 60000; accepted but **currently fixed at 1500 ms** by the CH32X firmware) | POWER 0x02 / 0x04 | CH32X (via RP2040) | power-cycle the output |

Unknown `cmd` names are reported as `rejected` with reason `unsupported_cmd`
(since `esp32:0.8.10`; earlier firmware only logged them). The `delay_s` /
`off_ms` gaps are protocol-wide (the same frames from the web panel behave the
same way), not HTTP-specific. `host.service_restart` (whitelisted unit restart)
is supported by the protocol but intentionally not wired into the worked
example.

### Verifying that a command took effect

An ack (§4) only says the frame left the ESP32. Confirm execution out of band:

| `cmd` | How to tell it executed |
|---|---|
| `ui.beep` | audible on the unit (RP2040 buzzer); no telemetry trace. A muted unit stays silent. |
| `ui.display_msg` | visible on the OLED for up to 60 s (info notice, `rp2040:1.2.2`+); no telemetry trace. |
| `host.shutdown` | the `host` object **disappears** from subsequent POSTs within ~2 min (90 s freshness + one 30 s poll): `host.status` is only emitted while the Pi service runs, and a class with no snapshot newer than 90 s (`HTTP_FRESHNESS_MS`) is omitted from the body. |
| `host.reset` | `host.uptime_s` drops to a small value in a later POST — the reliable trace. The `host` object may or may not disappear in between: the last pre-reboot snapshot stays "fresh" for 90 s, so a Pi that is back within that window never drops out (its stale `uptime_s` is repeated until the service resumes). |
| `power.cycle` | `power.flags` bit 1 (`VBUS_OUT_EN`) clears and `power.vbus_out_mv` dips in a later `power` object. `power.status` is produced at a 1 s local cadence but the HTTP body samples it once per 30 s poll, so a 1.5 s dip is usually **missed** — the Pi losing its rail reboots it, so `host.uptime_s` restarting (as for `host.reset`) is the reliable trace. |

A richer "executed / failed" report driven by the RP2040 / CH32X command RESP
frames on the in-board bus is a documented future extension point, not
implemented.

### Receiver limits (device side)

Defined in one place — the "Receiver limits" block at the top of
[`firmware-ESP32-LTE-M/main/http_backend.c`](../firmware-ESP32-LTE-M/main/http_backend.c)
— and mirrored by the reference server.

| Limit | Value | Behaviour when exceeded | Since |
|---|---|---|---|
| Response body | ≤ 2047 B (`HTTP_RESP_MAX` 2048 incl. NUL) | a larger `2xx` body is counted, dropped **whole** (no commands applied, one warning logged) and reported once as `resp_dropped {bytes, max}`; the `2xx` still counts as uplink-alive. Before `0.8.10`: silently truncated → unparsable → no acks → endless re-send. | `esp32:0.8.10` |
| Commands applied per response | ≤ 8 (`CMDS_PER_RESP_MAX` = `ACK_PENDING_MAX`) | entries beyond the 8th are neither applied nor acked; the server re-sends them next poll (converges 8 per cycle). | `esp32:0.8.10` |
| Pending-ack list | 8 ids (`ACK_PENDING_MAX`) | cannot overflow since `0.8.10` (8 applied per response = 8 pending; a `2xx` drains the carried acks before the response is applied). `ack_add()` keeps a defensive oldest-evict: the server would re-send, the device re-ack from the dedup ring. | — |
| Executed-id dedup ring | last 16 ids (`EXEC_RING_MAX`), RAM only | older ids fall out and would be re-executed if re-sent; lost on an ESP32 reboot. | — |
| Command `id` | JSON string of 1..47 chars (`ACK_ID_MAX` 48 incl. NUL) | missing / not a string / empty / longer → `rejected: bad_id` (first 47 chars echoed when present); never truncated into another id. Before `0.8.10`: cut to 31 chars. | `esp32:0.8.10` |
| `rejected` entries carried | ≤ 4 per POST (`REJ_MAX`), deduplicated by id | oldest dropped. | `esp32:0.8.10` |
| Redirects | none followed (`disable_auto_redirect`) | `3xx` logged, nothing applied, nothing dropped (§3). | `esp32:0.8.10` |
| Per-socket timeout | 20 s (`HTTP_TIMEOUT_MS`) | POST fails, retried next cadence; carried feedback kept. | — |
| Poll period | 30 s (`HTTP_PERIOD_MS`, compile-time); first POST ~12 s after the backend starts (`HTTP_SETTLE_MS`) | — | — |
| Telemetry freshness | 90 s (`HTTP_FRESHNESS_MS`) | a class with no snapshot newer than this is omitted from the body. | — |
| Request body | ≤ 2047 B (`HTTP_BODY_MAX` 2048) | typical v2 body 505–510 B; 578–580 B with 8 acks; ~550 B with `resp_dropped`. | `esp32:0.8.10` (was 1536) |
| `ui.display_msg` text | 64 B accepted by the ESP32; first 40 chars shown by the RP2040 | silently cut. | — |
| `ui.beep` args | `freq_hz`, `dur_ms` clamped to 0..65535 by the ESP32 | RP2040 maps `0` → 1500 Hz / 150 ms and clamps `dur_ms` ≤ 5000. | — |

### Server-side requirements

1. **Re-send until acked.** Keep every command in the response until its `id`
   appears in `acks` (or it expires on your side). The device re-acks an
   already-executed id without re-executing it.
2. **At most 8 commands per response, body ≤ 2047 B.** Entries beyond the 8th
   are neither applied nor acked; a body over 2047 B is dropped whole.
3. **Drop ids reported in `rejected`.** They are never acked; re-sending them
   only repeats the rejection.
4. **Treat `resp_dropped` as a bug on your side** — shrink the response (fewer
   commands per poll, shorter ids / args).
5. **Never mint ids longer than 47 chars** (a 36-char UUID fits). Ids must be
   non-empty JSON strings.
6. **Point the device at the final URL.** Redirects are not followed; a `3xx`
   applies nothing.
7. **Keep the response bytes unmodified end-to-end.** `X-W3PUPS-Sig` covers
   the exact body bytes: a proxy that re-serialises, pretty-prints or otherwise
   rewrites the JSON breaks the signature and the device drops the commands
   (fail-closed, §3).
8. **Expire stale commands.** A `host.shutdown` delivered an hour late (device
   was offline) is worse than none. The reference server drops any command
   not acked within 600 s of being queued — delivered or not (`--cmd-max-age`).

## 6. Configuring the endpoint (no re-flash)

You do **not** re-flash the ESP32 to point a fielded unit at your server (the
ESP32's USB may not even be accessible in the enclosure). The endpoint is set
at runtime from the **Raspberry Pi
host**, which sends a `net.config` frame (NET op `0x21`, see `protocol.h`) down
the existing serial link. The RP2040 routes RPi→ESP32 frames unchanged (no
RP2040 firmware change), and the ESP32 persists the value in its writable `nvs`
partition (namespace `w3http`, keys `url` / `devid`). It survives reboots and
backend-mode switches (cleared only by a factory reset).

Value rules — the device checks only the **length**; it applies no scheme
check and no normalisation, so a value that breaks the other rules is stored
as-is and every POST then fails:

- `url`: ≤ 200 chars (`HTTP_CFG_URL_MAX`; longer is refused, and
  `send_config.py` refuses it locally too). Must start with `http://` or
  `https://`. **No trailing slash** — the device appends
  `/api/v1/devices/{device_id}/telemetry` verbatim, so `https://host/` yields
  `//api/…` (404 on the reference server).
- `device_id`: ≤ 64 chars (`HTTP_CFG_DEVID_MAX`); used verbatim in the path and
  in `X-W3PUPS-Device`.
- `https://` requires a **publicly trusted certificate**: the device verifies
  the chain against the full Mozilla CA bundle **with hostname verification**.
  Self-signed or private-CA certificates are rejected; an IP-literal
  `https://203.0.113.10` needs a certificate carrying that IP in its SAN. Plain
  `http://` needs nothing (commands stay HMAC-authenticated, §3) and costs far
  fewer bytes per poll (§9).

From the Pi (see [`../examples/http-control-server/send_config.py`](../examples/http-control-server/send_config.py)):

```bash
sudo apt install -y python3-serial   # pyserial
python3 send_config.py --url http://<your-vps-ip>:8080
# the port is auto-detected by USB descriptor ("Web3_Pi_UPS"); pass --port to override
# optional: --device-id <id>   (default = ICCID)
# clear an override:  --url ""
```

> **Port contention.** The `w3p-ups` host service normally **owns** the RP2040
> serial port (it reads telemetry / sends commands). Two writers on one CDC
> corrupt framing, so `send_config.py` opens the port exclusively and will tell
> you to stop the service briefly if it can't:
> ```bash
> sudo systemctl stop w3p-ups && python3 send_config.py --url … && sudo systemctl start w3p-ups
> ```
> The cleaner production path is to have the service set this itself (a
> `w3p-ups set-http-url <url>` subcommand routing a `net.config` frame on the
> port it already owns) — see "Open / follow-ups" in the HTTP-2 evidence note.

A compile-time default (`HTTP_ENDPOINT_BASE` in `main/endpoints.h`) is
honoured only when NVS has no `url` yet — convenient for bench/dev. The
runtime `net.config` value always takes precedence.

Switching the device into HTTP mode itself is done from the **OLED menu**
(ADR-0012: MQTT / Arkiv / HTTP), which reboots into the selected backend.

## 7. Deployment recipe

The minimal path is "run the Python program on a VPS and point the device at
its IP" — **no TLS or domain required**:

1. On the device: OLED menu → **HTTP Key** — note the code shown (e.g.
   `ABCD EFGH JKLM NPQR`). Generate a fresh one with **New key** if you like.
2. Stand up the reference server on a host with a public IP, passing that code:
   ```bash
   python3 examples/http-control-server/server.py \
       --secret "ABCD EFGH JKLM NPQR" --device-id <iccid> --port 8080
   ```
3. From the Pi, point the device at it:
   ```bash
   python3 send_config.py --port <rp2040-cdc> --url http://<your-vps-ip>:8080
   ```
4. Switch the device to HTTP mode on the OLED (menu → Mode → HTTP). Within ~30 s
   you should see the first telemetry POST in the server log.
5. Enqueue a command at the server prompt (e.g. `beep`) — it is delivered on
   the next poll and its ack (bus-dispatch, §4) rides on the one after. Confirm
   execution by ear / on the OLED / in later telemetry (§5).

**Optional — add a domain + TLS** for confidentiality (telemetry contents are
otherwise readable on the wire; commands are authenticated either way). Put any
reverse proxy in front and switch the URL to `https://…`, e.g. Caddy
(automatic Let's Encrypt):

```
ups.example.com {
    reverse_proxy 127.0.0.1:8080
}
```

(nginx/Traefik with an LE cert work equally well; keep the
`/api/v1/devices/{device_id}/telemetry` path intact. Then
`send_config.py --url https://ups.example.com`.)

The M3 self-hosting acceptance check (criterion #8) validates that a tester can
stand the server up **from these docs alone**.

## 8. Security caveats for self-hosters

- **Guard the HTTP key.** It is the sole authenticator for *both* directions —
  anyone holding it can forge telemetry and forge signed commands. It's shown on
  the OLED on request; re-roll it (menu → HTTP Key → New key) if it leaks, and
  update your server. It is independent of the MQTT/Arkiv secret, so exposing it
  doesn't compromise those backends.
- **TLS is optional and only adds confidentiality.** Without it, telemetry and
  command contents are readable by an on-path observer, but they **cannot be
  forged or injected** (both directions are HMAC-signed). Add TLS (a reverse
  proxy + domain) if telemetry contents are sensitive on your network, or if
  you want defence-in-depth. The device accepts `http://` and `https://`.
- **Clock**: the device timestamps from network time (SNTP). Keep your server
  clock on NTP or valid requests will look stale.
- **Nonce store**: persist recent nonces per device (the reference stub keeps
  them in memory and forgets them on restart — a brief replay window).
- **One secret per device**: a multi-device server looks the secret up by the
  `{device_id}` path segment / `X-W3PUPS-Device` header.
- The shipped server is an **example**, not hardened infra: no auth on the
  operator command prompt, no persistence, no rate limiting.
- **Bounded responses.** The reference server sends at most 8 commands / 2047 B
  per response and drops any command not acked within 600 s of being queued,
  delivered or not (`--max-commands`, `--cmd-max-age`) — matching the device's
  receiver limits (§5). A server of your own must respect the same limits.

## 9. Data budget

The bundled SIM is a **1NCE prepaid pool: 500 MB per SIM or 10 years from
activation, whichever comes first** — a lifetime allowance, not a monthly
quota (top-up is possible via the 1NCE portal, i.e. by Web3 Pi, not by the end
user). Every poll cycle spends part of it, so the transport and the cadence
decide how long the pool lasts.

**Connection mechanics.** `esp_http_client` is created and torn down for every
POST: each cycle opens a **new TCP connection** and, for `https://`, runs a
**full TLS 1.2 handshake** (no TLS session resumption in use — the client
handle is destroyed after every POST and esp-tls session tickets are not
enabled, `CONFIG_ESP_TLS_CLIENT_SESSION_TICKETS`; no keep-alive).
The JSON body itself is ~0.5 KB (§5 "Receiver limits"); connection setup is a
large share of the per-cycle cost, and TLS multiplies it.

| Transport / mode (30 s cadence) | Per cycle | Per day | Per 30 days | 500 MB pool lasts | Basis |
|---|---|---|---|---|---|
| HTTP mode, plain `http://` | **1 629 B** (1 130 up + 498 down) | ≈ 4.7 MB | ≈ 141 MB | **≈ 107 days** | **MEASURED** 2026-09-11 on unit ICCID 8988228066680569990, `esp32:0.8.9`, reference server on a VPS, no commands queued: 78 consecutive POSTs over 39 min, figure = delta of the device's own cumulative PPP counters (`net.bytes_tx` / `net.bytes_rx`) |
| HTTP mode, `https://` | ≈ 5.5–9 KB | ≈ 16–26 MB | ≈ 0.5–0.8 GB | **≈ 3–4 weeks** | **ESTIMATE — not measured**: plain-http figure + Let's Encrypt chain 2.2–3.5 KB per handshake + TLS records + extra TCP segments |
| MQTT mode (for comparison) | — | ≈ 1.66 MB | ≈ 50 MB | ≈ 10 months | measured earlier on the MQTT backend (one persistent TLS session, no per-cycle handshake) |

Cost scales **linearly with the cadence**: a 5 min poll period costs ~10× less
than 30 s (plain http ≈ 0.47 MB/day → the pool lasts ≈ 2.9 years; only at a
cadence of ≥ ~17 min does 500 MB outlast the SIM's 10-year validity).

**Guidance.**

- On the bundled SIM prefer **plain `http://`** with the built-in HMAC signing
  (§3 — TLS adds confidentiality only) and the **widest cadence the use case
  tolerates**.
- Use `https://` only with your own SIM or a topped-up pool.
- Do not plan on more than ~3 months of plain-http polling at the default 30 s
  cadence per 500 MB pool.

**Measuring it yourself.** Every POST carries `net.bytes_tx` / `net.bytes_rx`:
the modem's cumulative PPP byte counters. They are refreshed every ~60 s, so
consecutive POSTs may repeat the same sample; the reference server prints
`Δtx=… Δrx=… B since previous net.status sample` for each *distinct* sample
and skips unchanged or backwards (device rebooted) samples. Divide the delta
by the number of POSTs in the window for the per-cycle figure.

**Future options (not implemented).** The poll period is compile-time today
(`HTTP_PERIOD_MS`); a runtime-configurable period, HTTP keep-alive and TLS
session tickets would each cut the per-cycle cost and are candidate follow-ups,
none of them in the firmware at `esp32:0.8.10`.

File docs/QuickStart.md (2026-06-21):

# Web3 Pi UPS — Quick Start

A compact DC UPS for the **Raspberry Pi 5**: powers the Pi over USB‑C, charges
and switches to a battery seamlessly on power loss, and reports its status to
the Pi over the **same cable** plus a small OLED + 2 buttons.

---

## ⚠️ Read this first

- **This is a prototype.** Always operate it **under supervision**. Do not leave it unattended, especially under havy load.
- **The battery MUST have a built‑in BMS / protection.** This board relies on
  the battery pack's own protection (over‑charge, over‑discharge, over‑current,
  short). All Sony NP‑F packs we know of have it — but **verify** before use,
  especially for third‑party/clone packs. Never use a raw, unprotected cell.
- **Li‑ion safety:** use the correct battery type, don't short the terminals,
  don't charge a damaged/swollen pack.

---
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

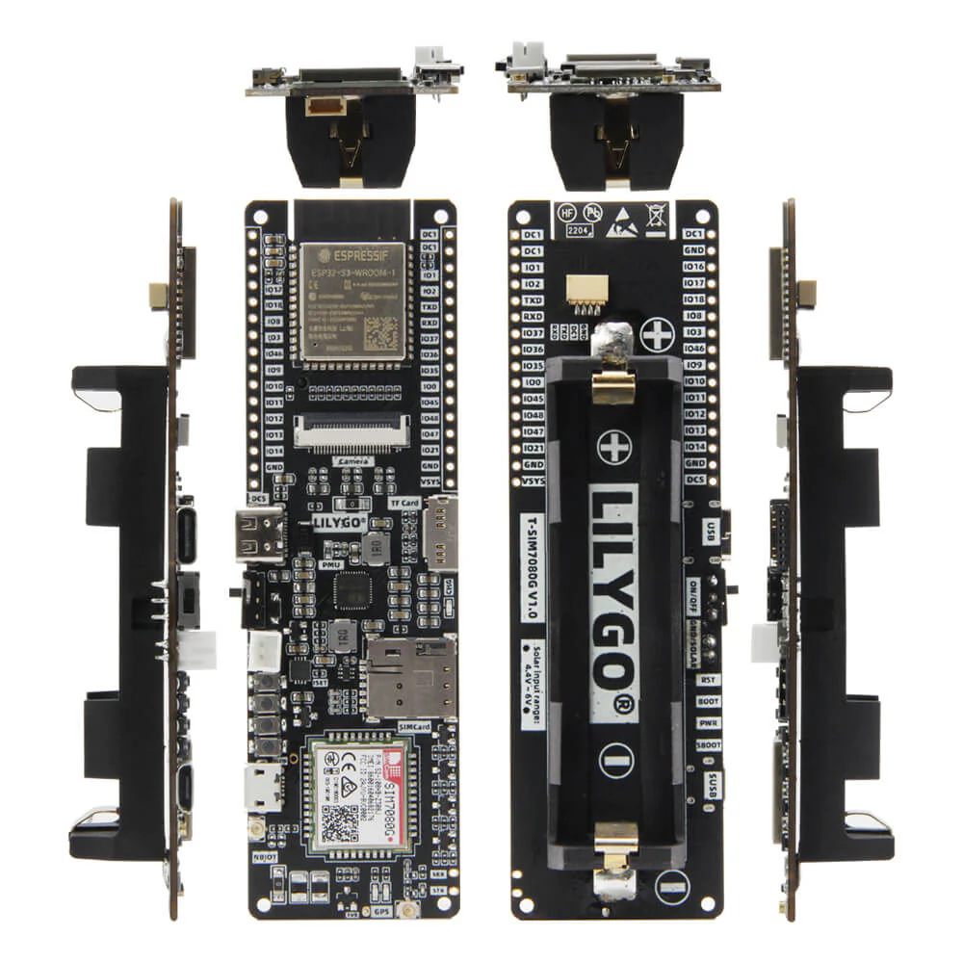
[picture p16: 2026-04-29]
firmware-ESP32-LTE-M/docs/T-SIM7080G-S3-H606_6.jpg.webp

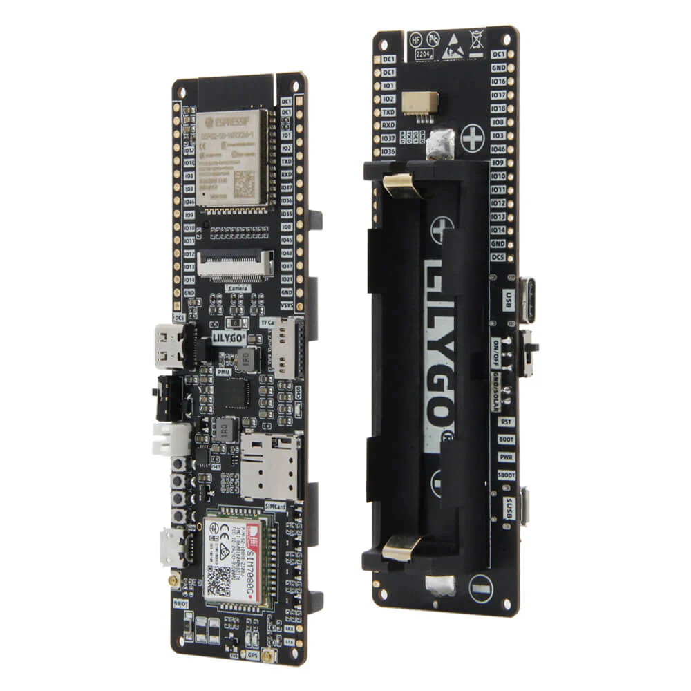
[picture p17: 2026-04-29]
firmware-ESP32-LTE-M/docs/T-SIM7080G-S3-H606_5.jpg.webp

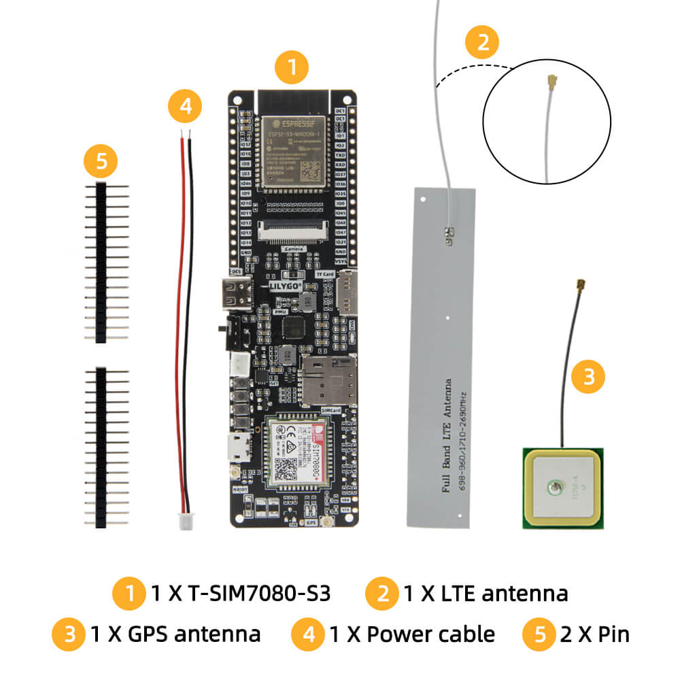
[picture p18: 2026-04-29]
firmware-ESP32-LTE-M/docs/T-SIM7080G-S3-H606_10.jpg

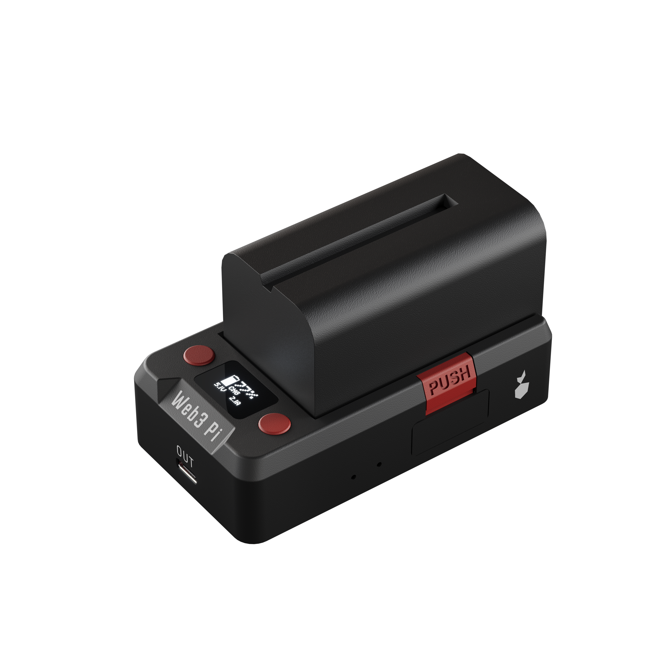
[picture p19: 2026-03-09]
docs/images/renders/front_2.png

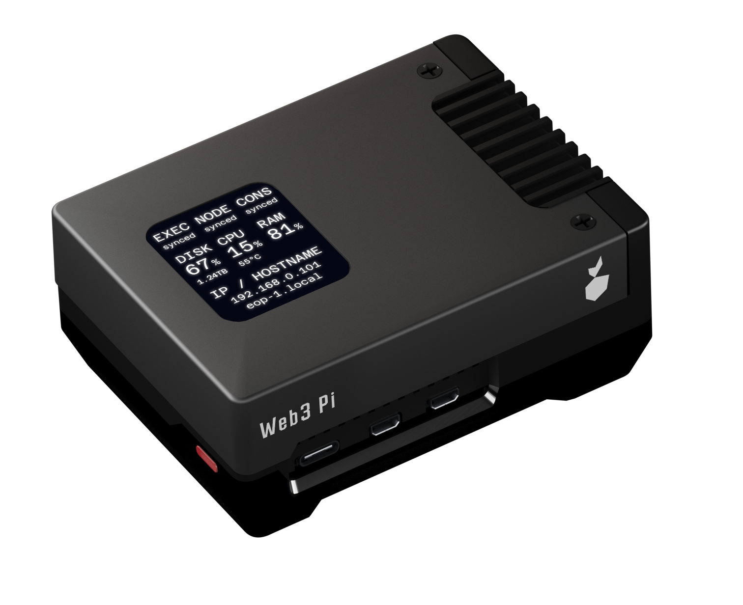
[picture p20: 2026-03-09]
docs/images/renders/rpi-2_samo.png

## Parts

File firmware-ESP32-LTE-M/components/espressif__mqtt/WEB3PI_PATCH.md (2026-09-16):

# Web3-Pi esp-mqtt 1.0.0 patches

This project-local component is selected with `override_path` in the main
component. The installed ESP-IDF and shared managed components are unchanged.
Espressif esp-mqtt is Apache-2.0 licensed; upstream inputs retain their original
license. `UPSTREAM_SHA256.json` pins every original retained build input.
`PATCHED_SHA256.json` pins every changed or added build input. The complete patch
chain reverses exactly to upstream, including the original private/public API.

1. `0001-stop-after-resend-abort.patch`: stop the connected iteration after a
   failed resend, preserving the outbox and emitting a single disconnect.
2. `0002-bounded-mqtt-service.patch`: opt-in cooperative service for issues
   #15 and #16. Legacy mode retains synchronous public publish semantics and its
   original connected branch. Both modes now check failed QoS2 response writes.

## Supported bounded profile

Set `network.bounded_service = true` for the built-in `mqtts` URI with MQTT 3.1.1
and certificate-based TLS 1.2. Custom transports, MQTT 5, secure-element/DS/ECDSA
peripheral and PSK configurations are rejected rather than silently degraded.
Certificate validation, common name, SNI, CA bundle/store, ALPN, interface,
software client certificate/key, cipher list and TCP keepalive remain configured.
The configured broker name remains the TLS verification and SNI name even though
asynchronous DNS gives the TCP connect path a numeric address.

Only the SDK service task enters the bounded TLS context. Public `enqueue()`,
subscribe and unsubscribe admit owned outbox packets; TRANSMITTED and its
retransmission timestamp advance only after the full packet is actually accepted
by TLS. QoS0 stored outbox entries are deleted only then. While an outbox frame is
staged, expiration waits until completion/abort (at most its original operation
deadline), so shared QoS0 packet ID zero cannot resolve to the next unsent item. Synchronous `publish()`
is rejected with `-1` / `errno=ENOTSUP` before admission in this opt-in mode; use
`enqueue()`. Changing config/URI while the bounded client runs is rejected; stop
before reconfiguration so TLS/DNS cannot retain freed configuration pointers.
Stop/disconnect promptly abort rather than promising graceful MQTT
DISCONNECT delivery; the broker may publish the LWT. The original stopped-task
lifecycle contract is preserved, with bounded transport/queue cleanup before its
unchanged close/outbox-delete/DISCONNECTED/STOPPED/task-delete suffix.

## Budgets and protocol state

- Each service turn attempts at most eight complete RX packets within a 10 ms
  CPU budget, then at most one 1024-byte TLS write. A 10 ms RTOS yield occurs
  outside the API mutex, even when the socket remains permanently ready. These
  are network-wait and work-quantity limits, not a hard CPU preemption guarantee:
  certificate crypto and application callbacks may exceed 10 ms. Callbacks must
  remain nonblocking. The measured maximum SDK lock hold is independently
  observable and must be checked on the target.
  The unlocked WAIT_RECONNECT event wait is also capped at 10 ms (at least one
  RTOS tick), because stop changes the run flag without setting RECONNECT_BIT.
  Cancellation therefore does not sleep through the reconnect backoff.
- `network.timeout_ms` is a monotonic, non-renewable deadline per RX packet
  (starting with first ciphertext readiness), per queued TX packet (including
  queue residence), and per connection phase: DNS+TCP+TLS, CONNECT send, CONNACK.
  At 15000 ms, connection establishment has at most three such phase budgets,
  plus CPU scheduling overhead. Progress never resets an operation deadline.
- Partial TLS and MQTT input persists between slices. A complete incoming packet
  is assembled up to a hard 16 KiB limit before callback delivery, avoiding lost
  streaming continuation. Invalid Remaining Length encodings and oversize input
  fail the connection before allocation/delivery. TX copies are capped at 32 KiB
  and 68 frames; 512 bytes are reserved against bulk admission for ACK/PING
  control frames. Normal RX/bulk admission stops at two staged frames; the
  remaining frame slots are reserved for the 64-packet PING grace, so full
  normal control traffic cannot prevent reading a buffered PINGRESP.
  Outbox storage is independent and keeps its existing limit.
- A partial SSL write keeps the same buffer and length for every WANT_READ or
  WANT_WRITE retry. No SSL read runs while that write is suspended. The original
  TX operation deadline bounds this local backpressure interval; producers and
  cancellation continue to run. Renegotiation is disabled on this connection's
  own TLS configuration. An SSL read returning WANT_WRITE means a blocked
  post-handshake alert in this supported profile: the connection fails closed,
  and no application write is attempted afterward. This explicit recovery avoids
  interleaving/duplicating records; it is not a general TLS transport replacement.
- PING response time begins only when the complete PINGREQ finishes sending and
  lasts keepalive/2. Before timeout, the service drains already available input.
  At expiration it gets one bounded 200 ms / 64-packet receive grace. Unrelated
  traffic never renews that grace. A previously suspended TLS write must first
  complete or reach its original TX deadline (at most the network timeout); this
  is local TX backpressure, not a claim that a buffered PINGRESP never arrived.
  No new TLS write starts during grace. Worst-case peer failure detection is
  response deadline + remaining in-flight TX budget + 200 ms + scheduling/CPU
  overhead; TX deadline expiry is a separate transport recovery path.

## ESP-IDF v6.0.2 boundaries

`mqtt_transport_nb.c` uses public ESP-TLS and mbedTLS APIs. DNS runs through a
nonblocking lwIP callback whose job is reference-counted independently of the
client, including cancellation before DNS completes. ESP-TLS async TCP connect
still calls select; its per-call timeout is therefore a positive 1 ms (zero
means infinite). Its CONNECTING fd_sets are modified by select and not rearmed
in this IDF version. The scoped adapter independently polls that socket, checks
SO_ERROR, and invokes the already-ready CONNECTING step with non_block temporarily
false to skip that select. Socket O_NONBLOCK remains set: IDF only changes socket
flags from INIT. The adapter restores the configuration immediately afterward.

`esp_mqtt_client_get_service_status()` reads atomic observations without acquiring
the SDK mutex: slice start/end, maximum SDK lock hold, last complete RX/partial TX
progress, RX/TX remaining budget, queue occupancy, deadline failures and current
operation. Fields are individual observations, not a transactionally coherent
snapshot; timestamps are monotonic milliseconds modulo 2^32. This permits an
independent monitor to observe a stalled operation without joining its lock.

## Verification

`tools/mqtt_sdk_sources.py` verifies both manifests and reverses 0002 then 0001,
checking the intermediate historical client and every upstream input exactly.
`test_mqtt_abort.py` retains mandatory original failures and checks the current
legacy branch. `test_mqtt_sdk_adapter.py` verifies the original stopped-task
lifecycle against its fixture. `test_mqtt_keepalive.py` runs the issue's mandatory
historical counterexamples and current bounded loop with actual MQTT parser,
encoder, outbox and service queue. `test_mqtt_transport_nb.py` compiles the actual
adapter against controlled public-API boundaries, including delayed TCP connect,
DNS cancellation, SNI, WANT retry identity and the blocked-alert terminal path.
Host tests are deterministic boundary checks, not a claim of physical TLS/LTE
qualification. ESP32 builds and hardware/fault-injection results are recorded in
the release report. Never change source pins simply to make a build pass.

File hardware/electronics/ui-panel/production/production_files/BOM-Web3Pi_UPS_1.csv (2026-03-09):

Comment | Designator | Footprint | LCSC | Quantity
100nF | C10,C11,C12,C5,C8 | C_0603_1608Metric | C14663 | 5
10k | R11,R12,R4,R6 | R_0603_1608Metric | C25804 | 4
1k | R3,R5 | R_0603_1608Metric | C21190 | 2
1uF/16V | C1,C13,C2,C9 | C_0603_1608Metric | C15849 | 4
2.2uF/16V | C6 | C_0603_1608Metric | C23630 | 1
22nF | C14 | C_0603_1608Metric | C21122 | 1
4.7k | R1 | R_0603_1608Metric | C23162 | 1
4.7uF | C3,C4 | C_0603_1608Metric | C19666 | 2
4.7uF/16V | C7 | C_0603_1608Metric | C19666 | 1
560k | R2 | R_0603_1608Metric | C23204 | 1
C139797 | SW1,SW2 | SW_SPST_PTS810 | C139797 | 2
Conn_01x04_Pin | J2L1,J3R1 | PinHeader_1x04_P2.54mm_Vertical_SMD_Pin1Left | C5160787 | 2
OLED-SSD1315 (LCSC:C18723009) | DS1 | X049-6432TSWPG02-H14 | C18723009 | 1
RT9193-3.3 | U1 | SOT-23-5 | C22466428 | 1

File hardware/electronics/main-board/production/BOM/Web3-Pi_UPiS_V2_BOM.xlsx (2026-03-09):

Designator | Comment | Footprint | LCSC
BUZ400 | 2700Hz | 7.5x7.5x2.5mm | C95299
C201, C202, C751, C752 | 390pF | 0402 (1005) | C282239
C203, C305, C306, C307, C308, C507, C508, C509, C527, C528, C529, C550 | 10uF | 1206 (3216) | C89632
C205, C511 | 100uF | SMD D8 (6.3x7.7mm) | C264047
C220, C221, C222, C223, C230, C231, C270, C271, C303, C304, C402, C403, C404, C405, C406, C407, C408, C409, C410, C415, C430, C504, C505, C510, C516, C525, C551, C750 | 100nF | 0402 (1005) | C77020
C300, C301, C302 | 470nF | 0603 (1608) | C513577
C309, C320, C321, C506, C512, C518, C526 | 1uF | 0805 (2012) | C28323
C310, C311, C312, C313, C314, C315, C316, C317, C318, C319, C322, C323, C324, C325, C330 | 10uF | 0805 (2012) | C95841
C326, C503 | 4.7uF | 0603 (1608) | C389010
C400, C401 | 15pF | 0402 (1005) | C106997
C411, C412, C413, C414 | 2.2uF | 0402 (1005) | C107371
C500 | 10nF | 0402 (1005) | C60133
C501 | 4.7nF | 0402 (1005) | C106208
C502 | 100pF | 0402 (1005) | C77177
C513 | 220nF | 0603 (1608) | C344195
C552, C553 | 22uF | 0805 (2012) | C907991
C554 | 56pF | 0402 (1005) | C107007
D200 | SMAJ20CA | SMA (DO-214AC) | C113960
D300 | 3A/30V | SMA (DO-214AC) | C41364476
D400 | 20V/1A | SMD 0603 (1608) | C552829
D550, D551 | 2A/40V | SOD-123FL | C22466352
FU200 | 5A/125VDC | SMD 2410 | C48467
J100 | M.2/NGFF B-Key H6.7 | SMD | C41430838
J200, J750 | USB 2.0, 16pins, 5V/20V rated | SMD | C2894897
J202 | DC Barrel Jack, 2.5mm | THT | C963204
J350, J752 | 3-pin, 1mm pitch | SMD | C160389
J400L, J400R | CON 1x4 SMD | SMD 2.54mm | C42379197
J401, J402, J751 | 4-pin, 1mm pitch | SMD | C160390
L300, L301 | 1.5uH | SMD | C167217
L500 | 4.7uH | SMD | C177246
L700 | 4.7uH | SMD | C3911513
LED300, LED420, LED750 | Green | 0805 (2012) | C84260
MECH100 | M2.5, L = 5.0mm | SMD | C2916359
Q201, Q230, Q231, Q501 | DTC143ZE | SOT-523 | C78593
Q220, Q221, Q270, Q271, Q272 | N-MOS 30V 40A | DFN-8 (3x3mm) | C2849568
Q222, Q500 | P-MOS 30V 40A | DFN-8 (3x3mm) | C148390
Q400 | NMOS | SOT23-3 | C181090
R200, R201, R302, R303, R510, R511, R750, R751 | 10R | 0402 (1005) | C138066
R202, R203, R206, R514, R515, R520, R521, R522, R524, R525, R526, R532, R752 | 5.1k | 0402 (1005) | C105872
R205, R504, R527 | 27.4k | 0402 (1005) | C273730
R207, R503, R523, R550, R553 | 150k | 0402 (1005) | C93947
R210, R211, R307, R310, R420, R753 | 15k | 0402 (1005) | C114761
R230, R231, R305, R306, R308, R311, R404, R405, R407, R408, R412, R413, R414, R421 | 10k | 0402 (1005) | C60490
R270, R300, R402 | 100R | 0402 (1005) | C106232
R272, R273, R403, R406, R410, R411, R415, R440, R441, R444, R445 | 1k | 0402 (1005) | C106235
R274, R430, R531 | 100k | 0402 (1005) | C60491
R301, R505 | 0.01R | 1206 (3216) | C364375
R309 | 4.7k | 0402 (1005) | C105871
R400, R401 | 27R | 0402 (1005) | C138021
R431, R551, R554 | 47k | 0402 (1005) | C93943
R432, R512 | 0R | 0402 (1005) | C106231
R500 | 49.9k | 0402 (1005) | C137969
SW1, SW2 | SPST | SMD | C2888437
SW270 | TACT Switch | SMD | C561482
U201, U751 | RCLAMP0524PA | SMD | C40960
U220, U221 | AP74700QW6-7 | SOT26 (SOT23-6) | C5381661
U230, U231 | 74LVC1G3157DW-7 | SOT363
U270 | HY2120-LB | SOT23-6 | C168778
U300 | MP2762A | QFN-30(4x5) | C26697965
U400 | RP2040 | QFN-56 | C2040
U401 | W25Q64JV |  | C2843335
U402 | LM75BTP | HWSON-8 | C5190812
U500 | TPS55289 | VQFN-21-HR | C5942077
U550 | AP63200WU-7 | TSOT-23-6 | C2158012
U750 | CH32X035 | QFN-20-EP | C42442062
X400 | 12.000MHz | SMD 2520 | C2149205

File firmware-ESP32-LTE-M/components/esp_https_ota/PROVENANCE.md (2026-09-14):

# Local ESP HTTPS OTA component

Origin: Espressif ESP-IDF v6.0.2, commit
`7101770dc6db2667b3c477cc31365dd1acd6db4e`, directory
[`components/esp_https_ota`](https://github.com/espressif/esp-idf/tree/v6.0.2/components/esp_https_ota).
The original component was copied from an unchanged checkout of that commit.
All five original component files are included. `LICENSE` is the unchanged
Apache-2.0 license from the root of the same ESP-IDF checkout; original source
copyright and SPDX notices are preserved. No global ESP-IDF file is modified.

`UPSTREAM_SHA256.json` records every original build/configuration/header/source
input and the license. `PATCHED_SHA256.json` records the corresponding current
files. Only `src/esp_https_ota.c` differs. The difference is completely represented
by `0001-return-header-transport-errors.patch`; reverse it with `patch -R -p1`
from this directory to recover the original source, then verify upstream hashes.

The patch returns `ESP_ERR_HTTP_EAGAIN` when reading the image's initial 1024-byte
header times out, instead of looping forever inside the SDK. Zero-length reads
or a completed response shorter than that header return
`ESP_ERR_HTTP_INCOMPLETE_DATA`. Other negative reads return
`ESP_ERR_HTTP_CONNECTION_CLOSED`. The description and perform APIs preserve these
transport codes; ordinary body reads distinguish incomplete EOF and connection
failure in the same way. Body EAGAIN continues to return IN_PROGRESS, as upstream.
Flash-write, erase, image validation and verification error handling is unchanged.

After a header error, the caller must abort the attempt and create a new handle.
Calling perform again on that handle would use its IN_PROGRESS state, without
re-reading and validating the incomplete header. The application owns bounded
retry/backoff, checkpoints and the total elapsed-time policy. No timer closes a
TLS context concurrently with an active read.

This change removes the repeated no-data spin. It is not an absolute wall-clock
deadline for every SDK operation: a single HTTP read can internally gather data
through multiple transport reads, and a sufficiently slow but continuing stream
can delay return. The application checks its deadline when SDK calls return.

`../../../tools/test_fw_ota_transport.py` extracts and compiles the exact
three affected functions with deterministic host I/O stubs. It reverses the patch
in a temporary directory, verifies original hashes, demonstrates original spins
using a test-only read-call ceiling, and checks patched results and successful
complete/fragmented reads. These are host control-flow tests, not hardware,
real-server, TLS, flash or end-to-end deadline evidence.

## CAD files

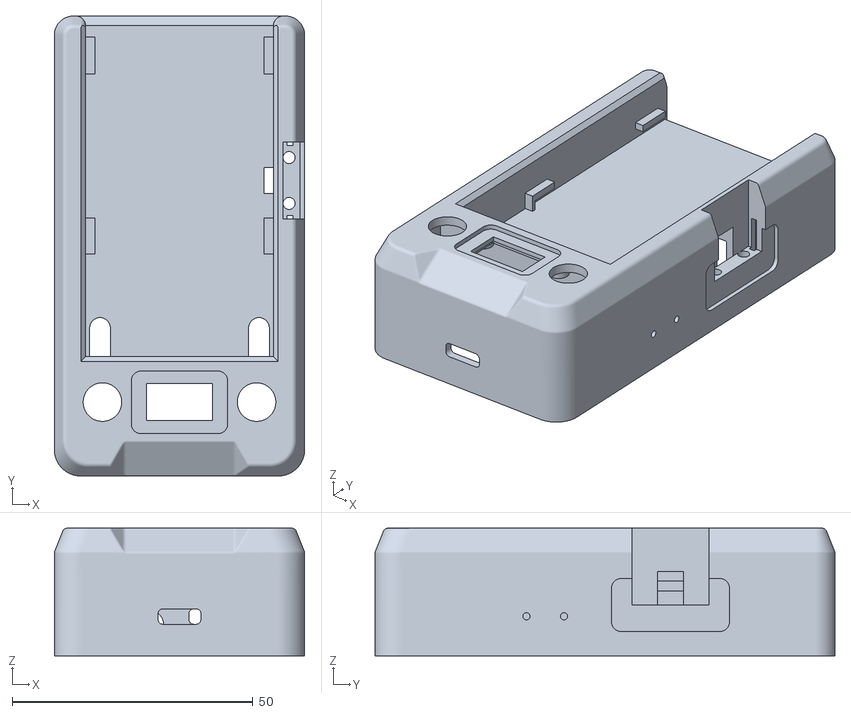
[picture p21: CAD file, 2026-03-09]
hardware/enclosure/Enclosure Main.stl
52.0 x 95.5 x 26.5

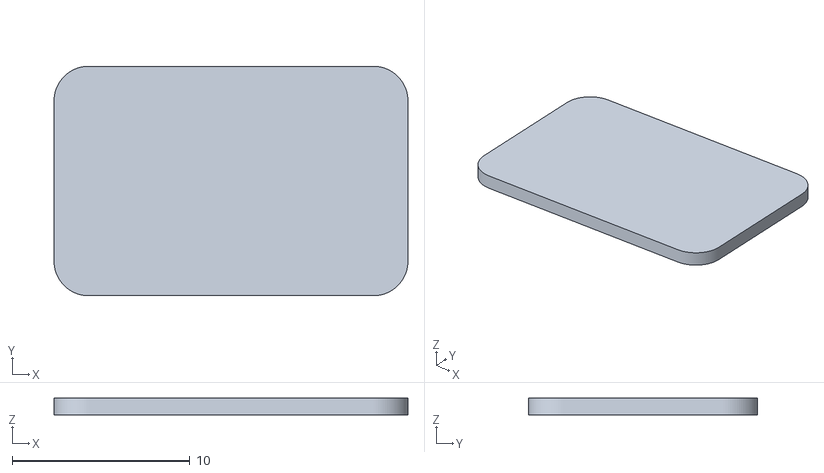
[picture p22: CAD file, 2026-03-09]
hardware/enclosure/OLED Dimmed Window.stl
19.9 x 12.9 x 0.95

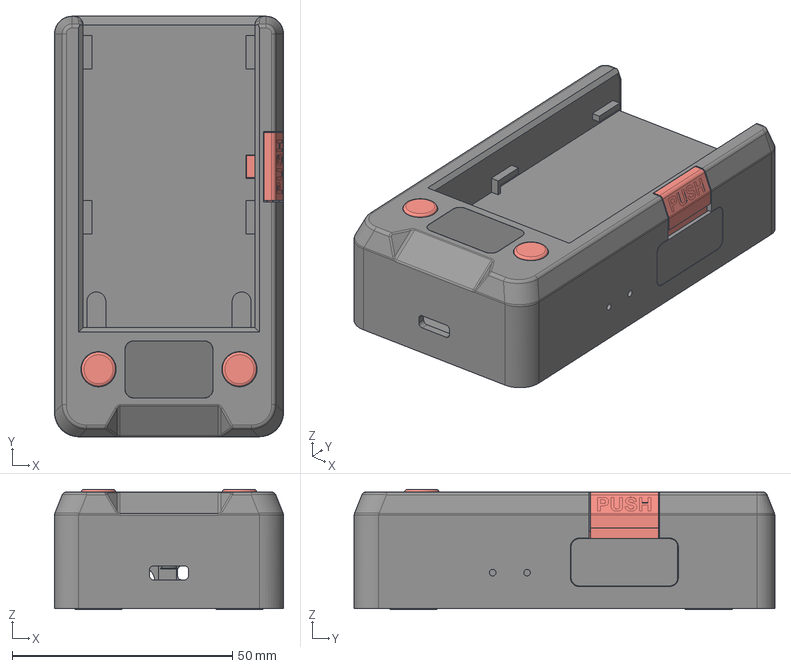
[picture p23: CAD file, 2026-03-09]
hardware/enclosure/Web3_Pi_UPS_3DPrinted.step
52.0 x 95.5 x 27.3 mm
DIN 965 - M2 x 4 - H Steel 4.6 Plain x 4
DIN EN ISO 7046-2 - M2x4 - H Steel 4.6 Black x 2
DIN EN ISO 7046-2 - M2x5 - H Steel 4.6 Black x 4
Rubber Feets

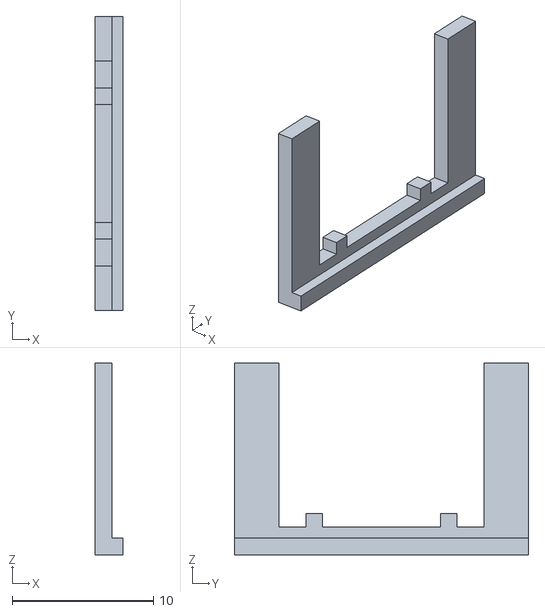
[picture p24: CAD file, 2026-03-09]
hardware/enclosure/Lock.stl
2.00 x 20.8 x 13.6

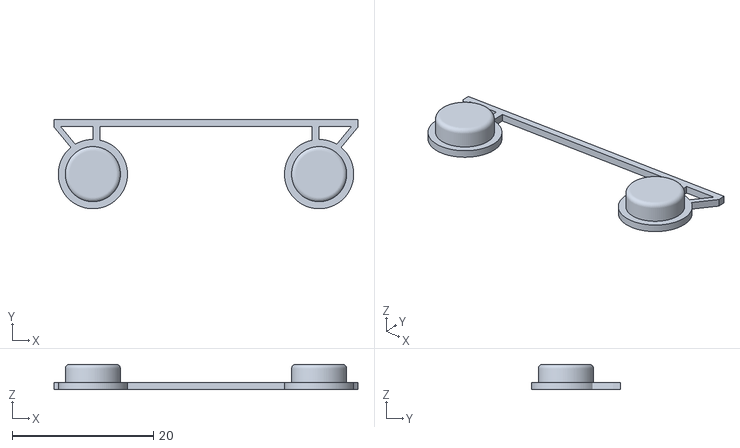
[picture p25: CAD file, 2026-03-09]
hardware/enclosure/Buttons.stl
43.0 x 12.7 x 3.60

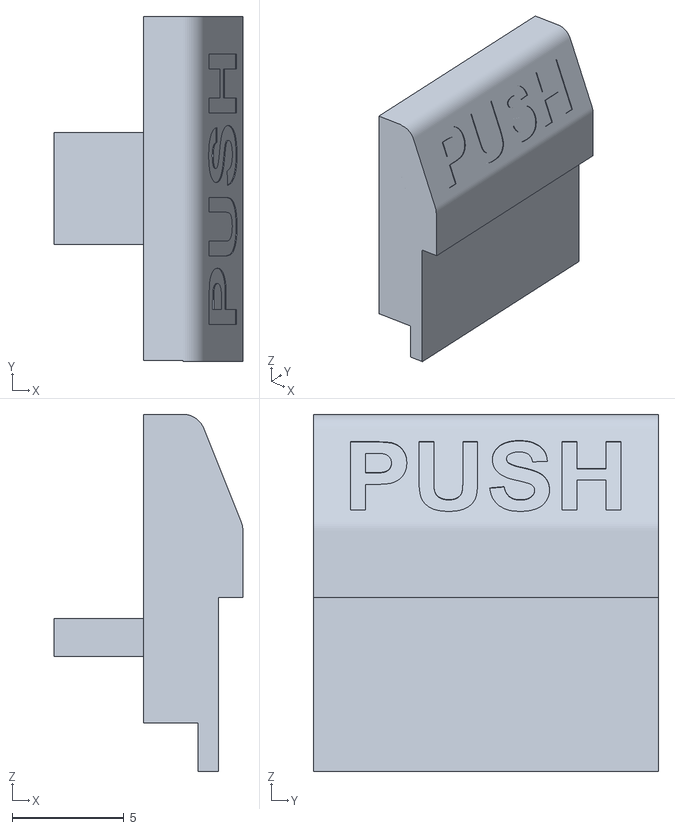
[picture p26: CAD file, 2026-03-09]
hardware/enclosure/Press Lock Button.stl
8.45 x 15.4 x 16.0

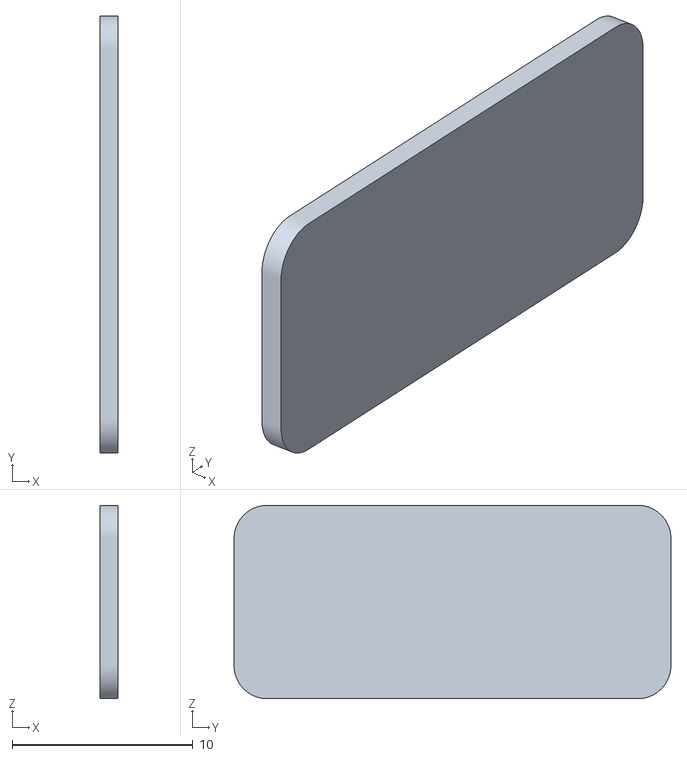
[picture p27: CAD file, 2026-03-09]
hardware/enclosure/Side Cover.stl
1.00 x 24.2 x 10.7

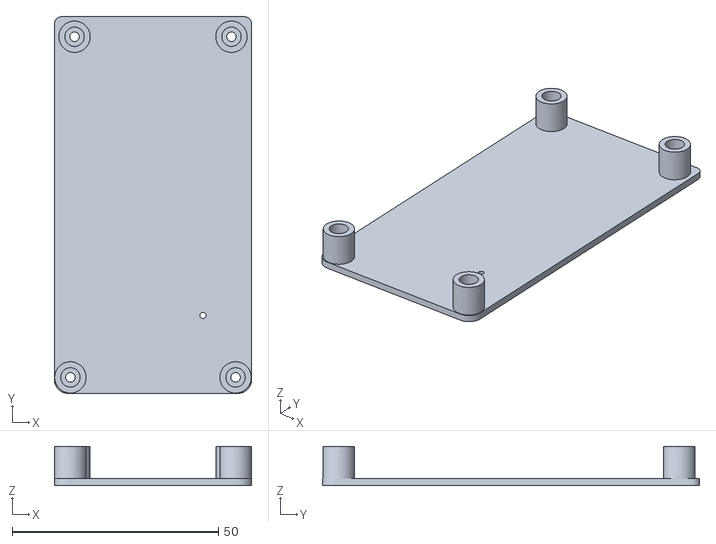
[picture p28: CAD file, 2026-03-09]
hardware/enclosure/Enclosure Bottom.stl
47.8 x 91.3 x 9.45

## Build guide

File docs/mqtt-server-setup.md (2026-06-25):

# MQTT Broker Setup — EMQX on Dokploy with Traefik TLS

A step-by-step guide to standing up your own MQTT broker for the Web3 Pi
UPS fleet (or any IoT project), with proper TLS certificates from
Let's Encrypt and three transports: HTTPS dashboard, MQTT-over-TLS for
embedded clients, and WebSocket Secure for browser / web clients.

This document captures everything we ran into during the first end-to-end
bring-up, so the next person doesn't have to discover the same gotchas.

## What you get

After following this guide:

- **`https://<dashboard>.<your-domain>`** — EMQX admin web UI behind LE TLS
- **`mqtts://<broker>.<your-domain>:8883`** — raw MQTT-over-TLS, native and
  efficient, ideal for embedded ESP32 / cellular clients
- **`wss://<wss>.<your-domain>:443/mqtt`** — MQTT-over-WebSocket-Secure on
  port 443, works through any restrictive firewall

All three share the same EMQX container, the same authentication backend,
and the same Let's Encrypt automation managed by Traefik (Dokploy's
default reverse proxy).

## Architecture

```
                                 the internet
                                       │
                                       │ TCP/443 (HTTPS, WSS)
                                       │ TCP/8883 (mqtts)
                                       │ TCP/80 (ACME challenges)
                                       ▼
            ┌────────────────────────────────────────────────────────┐
            │              VPS (e.g. Hetzner CX32)                   │
            │                                                        │
            │  ┌──────────────────────────────────────────────────┐  │
            │  │                    Traefik                       │  │
            │  │   entryPoints: web, websecure, mqtts             │  │
            │  │   certresolvers: letsencrypt (HTTP-01 challenge) │  │
            │  └────────┬───────────────────────┬─────────────────┘  │
            │           │                       │                    │
            │           │ HTTP/HTTPS routers    │ TCP router         │
            │           │ (Host: ...)           │ (HostSNI: ...)     │
            │           ▼                       ▼                    │
            │  ┌──────────────────────────────────────────────────┐  │
            │  │              dokploy-network (bridge)            │  │
            │  └────────────────────────┬─────────────────────────┘  │
            │                           │                             │
            │  ┌────────────────────────┴─────────────────────────┐  │
            │  │                   emqx container                 │  │
            │  │   :18083 (HTTP dashboard)                        │  │
            │  │   :8083  (WS for WSS termination at Traefik)     │  │
            │  │   :1883  (plain MQTT for mqtts termination)      │  │
            │  │   …                                              │  │
            │  └──────────────────────────────────────────────────┘  │
            └────────────────────────────────────────────────────────┘
```

Key idea: **TLS terminates at Traefik**, not at EMQX. Traefik holds the
LE cert and forwards plain MQTT / plain HTTP to EMQX over the internal
Docker network. EMQX's own TLS listeners (with their bundled
self-signed cert) are unreachable from outside and effectively unused.

## Prerequisites

- A VPS with a public IP address. We used Hetzner Cloud CX32 (Ubuntu
  24.04 LTS, ~€5/month). Anything with Docker support works.
- A domain you control. This guide uses `w3p.ovh`; replace with yours.
- DNS access for the domain (we'll need three subdomains).
- An SSH key pair on your local machine.
- A locally-installed [MQTT Explorer](https://mqtt-explorer.com/) for
  manual verification. Optional but useful.

## Step 1 — Prepare the VPS

Standard Ubuntu hardening. Skip if you already have this.

```sh
# As root, after first login:
adduser robert
usermod -aG sudo robert
mkdir -p /home/robert/.ssh
# (paste your public key into /home/robert/.ssh/authorized_keys)
chown -R robert:robert /home/robert/.ssh
chmod 700 /home/robert/.ssh
chmod 600 /home/robert/.ssh/authorized_keys
```

Then disable root login and password auth in `/etc/ssh/sshd_config`:

```
PermitRootLogin no
PasswordAuthentication no
```

`systemctl reload ssh`.

### Firewall

Two firewalls to think about:

1. **Hetzner Cloud Firewall** (if your VPS is on Hetzner Cloud) — manage
   in the Cloud Console under Firewalls. Open inbound:
   - `TCP/22` (SSH)
   - `TCP/80` (HTTP — needed for Let's Encrypt HTTP-01 challenges)
   - `TCP/443` (HTTPS, WSS)
   - `TCP/8883` (MQTT-over-TLS)

2. **`ufw` on the VPS** — *technically* you can also configure ufw, but
   note that **Docker bypasses ufw** by default (it manipulates iptables
   directly through the `DOCKER` chain, which sidesteps ufw rules on the
   `INPUT` chain for any port mapped via `docker run -p`). In our setup
   we removed the ufw rule for 8883 and it still works because Traefik
   maps port 8883 with `-p 8883:8883`, and Docker punches that through
   iptables before ufw sees it. So ufw is mostly cosmetic here. The
   Hetzner Cloud Firewall (or whatever firewall sits in front of the VM)
   is the one that actually matters.

   If you still want ufw + Docker working "properly":
   <https://github.com/chaifeng/ufw-docker>

## Step 2 — Install Dokploy

```sh
curl -sSL https://dokploy.com/install.sh | sh
```

After install, the admin UI is at `http://<VPS_IP>:3000`. First
visit prompts you to create the admin account. Pick a strong password
and 2FA-enable later.

Dokploy is the reason we get a Traefik instance with ACME on autopilot —
it sets that up for us.

## Step 3 — DNS records

Add three A-records pointing to the VPS public IP:

| Subdomain | Purpose |
| --- | --- |
| `emqx.<your-domain>` | EMQX admin dashboard (HTTPS) |
| `mqtt.<your-domain>` | MQTT over WebSocket Secure (WSS) |
| `broker.<your-domain>` | MQTT over raw TCP/TLS (mqtts://) |

Wait for DNS propagation (`dig +short broker.<your-domain>` should
return your VPS IP).

## Step 4 — Add the `mqtts` entryPoint to Traefik

By default Dokploy's Traefik listens on `:80` (web) and `:443` (websecure)
only. Raw MQTT-over-TLS uses port 8883, so we add a third entryPoint.

### 4a) Edit `traefik.yml`

In Dokploy admin → **Web Server** → look for **"Edit Traefik Configuration"**
or similar, OR SSH to the VPS:

```sh
sudo nano /etc/dokploy/traefik/traefik.yml
```

Add the `mqtts` block to `entryPoints`:

```yaml
entryPoints:
  web:
    address: :80
  websecure:
    address: :443
    http3:
      advertisedPort: 443
    http:
      tls:
        certResolver: letsencrypt
  mqtts:                # ← add this
    address: :8883      # ← add this
```

### 4b) Map port 8883 from the host into the Traefik container

Adding the entryPoint isn't enough on its own — the Traefik *container*
also needs to expose port 8883 to the host network namespace.

In Dokploy admin → **Web Server** → **Additional Port Mappings**
(button labeled like that in v0.20+):

| Target Port | Published Port | Protocol |
| ---: | ---: | :---: |
| 8883 | 8883 | TCP |

Save. The warning that "the Traefik container will be recreated" is
expected — there will be a few seconds of downtime on the dashboard
and any existing WSS connections.

After Save, verify on the VPS:

```sh
sudo ss -tlnp | grep 8883
# expect: LISTEN  0  4096  0.0.0.0:8883  ...  (with traefik PID/process)
```

If you don't see Traefik listening, the recreation didn't apply — try
`sudo docker restart dokploy-traefik` or redeploy from the Dokploy admin
panel.

### Note: this is *not* configurable from the regular Domains GUI

Dokploy → Domains generates **HTTP** routers for Traefik
(`traefik.http.routers.*`). For MQTT-over-TLS we need a **TCP** router
(`traefik.tcp.routers.*`) which only exists as Docker labels (Step 5
below). Do **not** add `broker.<your-domain>` in the Domains GUI — it
would create an HTTP router that conflicts with the TCP router we're
about to define.

## Step 5 — Deploy EMQX via Dokploy Compose

Create a new project in Dokploy → add a "Compose" service. Paste this
`docker-compose.yml`:

```yaml
services:
  emqx:
    image: emqx/emqx-enterprise:6.2.0
    hostname: node1.emqx.com
    environment:
      EMQX_NODE__NAME: emqx@node1.emqx.com
      EMQX_NODE__COOKIE: "PUT_A_LONG_RANDOM_STRING_HERE"
      # Override the default admin/public credentials so the dashboard
      # isn't exposed with well-known defaults the moment LE issues the cert.
      EMQX_DASHBOARD__DEFAULT_USERNAME: "admin"
      EMQX_DASHBOARD__DEFAULT_PASSWORD: "PUT_A_STRONG_PASSWORD_HERE"
    expose:
      - 18083   # Dashboard (HTTP, behind Traefik HTTPS)
      - 8083    # MQTT-over-WebSocket (HTTP, behind Traefik WSS)
      - 1883    # plain MQTT (behind Traefik TCP/TLS termination)
    # NB: NO `ports:` block — we never expose EMQX directly to the host.
    #     All external access goes through Traefik on the dokploy-network.
    volumes:
      - emqx_data:/opt/emqx/data
      - emqx_log:/opt/emqx/log
    networks:
      dokploy-network:
        aliases:
          - emqx-service
    restart: unless-stopped
    healthcheck:
      test: ["CMD", "/opt/emqx/bin/emqx_ctl", "status"]
      interval: 30s
      timeout: 5s
      retries: 3
    labels:
      # Without this, Dokploy's Traefik provider (exposedByDefault=false)
      # ignores ALL the labels below. Symptom: 404 from Traefik for every
      # router pointed at this container.
      - "traefik.enable=true"

      # === EMQX Dashboard — HTTP router ===
      - "traefik.http.routers.emqx-dashboard.rule=Host(`emqx.w3p.ovh`)"
      - "traefik.http.routers.emqx-dashboard.entrypoints=websecure"
      - "traefik.http.routers.emqx-dashboard.tls.certresolver=letsencrypt"
      - "traefik.http.routers.emqx-dashboard.service=emqx-dashboard"
      - "traefik.http.services.emqx-dashboard.loadbalancer.server.port=18083"

      # === MQTT-over-TLS — TCP router with TLS termination ===
      # Note: HostSNI(...), not Host(...). TCP routers match on the SNI
      # value embedded in the TLS ClientHello, since there's no HTTP
      # Host header to look at.
      - "traefik.tcp.routers.emqx-mqtts.rule=HostSNI(`broker.w3p.ovh`)"
      - "traefik.tcp.routers.emqx-mqtts.entrypoints=mqtts"
      - "traefik.tcp.routers.emqx-mqtts.tls=true"
      - "traefik.tcp.routers.emqx-mqtts.tls.certresolver=letsencrypt"
      - "traefik.tcp.routers.emqx-mqtts.service=emqx-mqtt-svc"
      # Backend port = 1883 (plain MQTT inside the container). Traefik
      # decrypts client traffic with the LE cert and forwards plaintext
      # over the docker network to EMQX.
      - "traefik.tcp.services.emqx-mqtt-svc.loadbalancer.server.port=1883"

      # === MQTT-over-WSS — HTTP router (TLS upgraded to WebSocket) ===
      - "traefik.http.routers.emqx-wss.rule=Host(`mqtt.w3p.ovh`)"
      - "traefik.http.routers.emqx-wss.entrypoints=websecure"
      - "traefik.http.routers.emqx-wss.tls.certresolver=letsencrypt"
      - "traefik.http.routers.emqx-wss.service=emqx-wss-svc"
      - "traefik.http.services.emqx-wss-svc.loadbalancer.server.port=8083"

volumes:
  emqx_data:
  emqx_log:

networks:
  dokploy-network:
    external: true
```

Replace the three `*.w3p.ovh` hostnames with your own subdomains.
Replace the placeholders for `EMQX_NODE__COOKIE` and the dashboard
password.

Click **Deploy**. The first deploy:

1. Pulls the EMQX image (~250 MB).
2. Starts the container.
3. Traefik notices the labels (because `traefik.enable=true`) and
   creates routes.
4. Traefik requests three Let's Encrypt certs (one per hostname) via
   HTTP-01 challenges on port 80. The first request takes ~30 s.
5. Routes go live.

## Step 6 — Verify externally

From any other machine:

### Dashboard
```sh
curl -I https://emqx.w3p.ovh/
# expect: HTTP/2 200
```

### MQTT-over-TLS handshake
```sh
echo | openssl s_client -connect broker.w3p.ovh:8883 \
  -servername broker.w3p.ovh -showcerts 2>&1 \
  | grep -E "subject=|issuer=|verify return"
```

Expected output (issuer changes over time as LE rotates intermediates;
R10/R11/R13 are all fine):

```
verify return:1
verify return:1
verify return:1
subject=CN=broker.w3p.ovh
issuer=C=US, O=Let's Encrypt, CN=R13
```

If you instead see `subject=CN=localhost, issuer=…EMQ RootCA…`, you're
hitting EMQX directly — Traefik isn't routing the connection. See
**Pitfalls** below.

### WSS reachability
```sh
curl -I https://mqtt.w3p.ovh/mqtt
# expect: HTTP/2 200 or HTTP/2 426 (Upgrade Required) — both fine,
#         it means Traefik routes to EMQX which then tries the WS upgrade
```

### MQTT Explorer

Set up two profiles to verify both transports:

**MQTT-over-TLS:**
- Protocol: `mqtts://`
- Host: `broker.w3p.ovh`
- Port: `8883`
- Validate certificate: **ON**
- Username / Password: as configured in EMQX

**WSS:**
- Protocol: `wss://`
- Host: `mqtt.w3p.ovh`
- Port: `443`
- Path: `/mqtt`
- Validate certificate: **ON**
- Username / Password: same

Both should show "Connected" with a green padlock.

## Step 7 — Initial EMQX configuration

Dashboard → first login uses the credentials you set via env var.
Change them via UI as well if you like.

### Add an MQTT user

EMQX → Access Control → Authentication → **Built-in Database** is
enabled by default. Add users you'll authenticate from.

> **Note:** the early prototype used a single shared `TestUpsUser`. That
> user is **retired** — the shipping firmware authenticates per-device
> (username = SIM ICCID, password = per-device 32-byte secret from the
> `prov` NVS partition, ADR-0008) with a single EMQX ACL rule keyed on
> `${username}`. Don't recreate `TestUpsUser`.

### Disable the EMQX-internal SSL/WSS listeners

EMQX comes with `ssl/8883` and `wss/8084` listeners enabled, both using
EMQX's bundled self-signed cert (CN=localhost). Since Traefik handles
all TLS termination in our setup, these listeners are unreachable from
the outside, but it's tidier to disable them outright. EMQX dashboard →
**Cluster → Listeners** → toggle `ssl` and `wss` off.

The `tcp` (1883) and `ws` (8083) listeners must stay **enabled** —
Traefik forwards plain MQTT/WS traffic to those after terminating TLS.

## Pitfalls / lessons learned

### `MBEDTLS_ERR_X509_FATAL_ERROR (-0x3000)` from an embedded client

Two common causes:

1. The broker is presenting EMQX's bundled self-signed cert
   (`CN=localhost`) instead of a real LE cert. Either Traefik isn't
   set up correctly, or you're hitting EMQX's own SSL listener directly
   (port 8883 mapped on the host bypassing Traefik). Run
   `openssl s_client` to check what cert is actually served.

2. The chip's wall clock isn't set, so cert validity period checks
   fail (notBefore is "in the future" from the chip's epoch=0 point of
   view). Solution: SNTP-sync time **before** TLS handshake. Our
   firmware does this in `modem.c::wait_for_time_sync()`.

### `Operation timed out` connecting to port 8883

Packets aren't reaching the VPS at all. The host:

- Hetzner Cloud Firewall blocking 8883 (most common — default is "only
  open what you add")
- Traefik not listening on host:8883 (the Additional Port Mapping wasn't
  saved or the container didn't recreate). Check
  `sudo ss -tlnp | grep 8883` on the VPS.

### `Connection refused` on port 8883

Different signal: packets reach the VPS, but nothing is listening. The
process for resolution:

- Verify the Traefik container exposes 8883:
  `sudo docker port dokploy-traefik` should include `8883/tcp -> 0.0.0.0:8883`
- Verify the entryPoint is in `traefik.yml`:
  `cat /etc/dokploy/traefik/traefik.yml | grep -A1 mqtts:`

### `traefik.enable=true` is mandatory

Dokploy's Traefik provider is configured with `exposedByDefault: false`
(security default — opt-in routing). Without `traefik.enable=true` on
the container, **all** Traefik labels on it are silently ignored, so
none of the routes work. Symptom: every domain returns 404.

When using Dokploy GUI's **Domains** feature, this label is added
automatically. When defining routes via Compose labels (the only way
for TCP routers), you must add it yourself.

### Don't double up on Domains GUI vs Compose labels

A specific gotcha: the Dokploy Domains GUI generates HTTP routers. If
you also have an HTTP router for the same domain in your compose
labels, Traefik may pick either one. Worse, if you accidentally add an
HTTP router for `broker.w3p.ovh` in the Domains GUI while we're trying
to use a TCP router for that domain, the HTTP router "wins" on
:443/HTTPS and you get bad gateway errors.

Recommendation: pick one source. We use compose labels for everything
related to our stack, and leave Dokploy → Domains empty for the
EMQX project.

### Don't expose EMQX ports directly to the host

The `ports: ["8883:8883"]` style mapping in EMQX's compose service
(present in the original Dokploy template) **bypasses Traefik
entirely** — anyone hitting the VPS on 8883 talks to EMQX directly,
including its bundled self-signed cert. Remove the `ports:` block from
EMQX once Traefik is doing TLS termination. Use only `expose:` for
documentation; ports are reachable from other containers on
`dokploy-network` regardless.

### Default credentials change

EMQX ships with `admin` / `public` for the dashboard. Anyone who
guesses your dashboard hostname and tries default creds gets full
access (creating users, reading retained messages, etc.). Change the
default via the `EMQX_DASHBOARD__DEFAULT_USERNAME` and
`EMQX_DASHBOARD__DEFAULT_PASSWORD` env vars in the compose service so
the change is reproducible across container recreations.

### TCP routers match on `HostSNI(...)`, not `Host(...)`

A subtle but important difference. HTTP routers inspect the `Host:`
header in the HTTP request. TCP routers inspect the SNI value in the
TLS ClientHello (because there's no HTTP layer to look at — it's raw
TCP/TLS).

If you mix these up:

- `Host(...)` on a TCP router never matches; Traefik returns nothing
  (client times out or sees connection close)
- `HostSNI(...)` on an HTTP router never matches either

Always: `HostSNI` for `traefik.tcp.routers.*`, `Host` for
`traefik.http.routers.*`.

### Backend port = `1883`, not `8883`

For the TCP-with-TLS-termination pattern, Traefik takes the TLS
connection from the client, decrypts it, and forwards the **plaintext**
MQTT bytes to the backend. EMQX's plaintext MQTT listener is on 1883,
not 8883. If you point the loadbalancer at 8883 instead, Traefik tries
to TLS-handshake again with EMQX's listener (which has its own
self-signed cert), and you get cryptic errors.

```yaml
- "traefik.tcp.services.emqx-mqtt-svc.loadbalancer.server.port=1883"   # ✅
# - "traefik.tcp.services.emqx-mqtt-svc.loadbalancer.server.port=8883" # ❌
```

## Maintenance

### Cert renewal

Traefik handles ACME automatically. Let's Encrypt certs are valid for
90 days; Traefik renews them at ~60 days. Watch:

```sh
sudo docker logs dokploy-traefik 2>&1 | grep -i acme | tail -20
```

You should see periodic renewal events. If a renewal fails (e.g. due
to rate limits or a momentary DNS issue), Traefik retries automatically.

### Backups

`emqx_data` and `emqx_log` are persistent volumes containing:
- Built-in DB users + ACL rules
- Retained messages
- Cluster config

Snapshot regularly:

```sh
sudo docker run --rm \
  -v emqx_data:/source:ro \
  -v $(pwd):/backup \
  alpine tar czf /backup/emqx_data_$(date +%Y%m%d).tgz -C / source
```

Or use Dokploy's built-in backup feature if your version exposes one.

### Version updates

When updating EMQX (e.g. 6.2.0 → 6.3.0):

1. Read EMQX release notes for breaking changes.
2. Backup `emqx_data` first.
3. Bump the `image:` tag in compose.
4. Redeploy in Dokploy.

EMQX major versions are not always rolling-upgrade safe — read the
upgrade guide before bumping major.

## Total cost estimate

Annual operating cost for the setup above (single-broker, fits 100s
of devices comfortably):

| Item | Cost |
| --- | ---: |
| Hetzner Cloud CCX11 (4 vCPU, 16 GB) | ~€60/year |
| Domain registration (`.ovh`) | ~€5/year |
| Let's Encrypt certificates | €0 |
| Dokploy / EMQX OSS | €0 |
| **Total** | **~€65/year** |

For a 50-unit Web3 Pi UPS deployment, that's roughly €1.30 per device
per year just for broker infrastructure. Plenty of headroom to scale
into the thousands without changing anything.

## References

- Dokploy docs: <https://dokploy.com/docs>
- The discussion that documented the original `mqtts` setup template
  used by Dokploy:
  <https://github.com/Dokploy/dokploy/discussions/3126>
- EMQX docs: <https://docs.emqx.com/en/emqx/v6/>
- Traefik TCP routers: <https://doc.traefik.io/traefik/routing/routers/#tcp-routers>
- Traefik labels reference: <https://doc.traefik.io/traefik/providers/docker/#routing-configuration-with-labels>
- Let's Encrypt rate limits: <https://letsencrypt.org/docs/rate-limits/>
- ufw + Docker interaction: <https://github.com/chaifeng/ufw-docker>

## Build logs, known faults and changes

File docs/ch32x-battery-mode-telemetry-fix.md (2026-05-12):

# CH32X telemetry fix — battery mode (no mains) reports garbage

**Status**: hardware fix applied (R433 = 100 Ω), firmware change pending.
**Affected file**: `Web3-Pi-UPS/firmware-ch32x/User/main.c` (+ `mp2762a.c`, `ADC_Function_Init`).
**Target**: CH32X035 firmware. RP2040 firmware unchanged.

---

## 1. Observed bug

When external power (USB-C **or** barrel jack) is disconnected and the UPS runs from battery, the `power.status` frame emitted by CH32X over WUPS contains nonsensical data. Captured frames from a live unit:

### Mains ON (frame seq=74, sane)

```
payload @ off+10:  01 02 a8 2f 88 13 88 13 dc 20 00 00 9b 01 d0 20 32 01 00 00
parsed:
  version=1  charge_state=2 (DONE)
  vbus_in_mV   = 12200
  vbus_out_mV  = 5000
  ibus_out_mA  = 5000
  vbat_mV      = 8412     ← 2S Li-Ion fully charged ✓
  ibat_mA      = 0
  temp_dC      = 411      ← 41.1°C ✓
  pd_contract  = 8400 mV @ 306 mA  (aliased to VSYS/IIN per main.c:509-515)
  faults       = 0
```

### Mains OFF (frame seq=75, broken)

```
payload:           01 00 00 00 88 13 88 13 00 00 00 00 ae 0d 00 00 00 00 00 00
parsed:
  version=1  charge_state=0 (NOT_CHARGING)
  vbus_in_mV   = 0        ← correct (mains gone)
  vbus_out_mV  = 5000     ← TPS55289 OK, alive on battery
  ibus_out_mA  = 5000     ← suspicious (separate latent bug, see §7)
  vbat_mV      = 0        ✗ battery is physically connected and full (~8.4 V)
  ibat_mA      = 0
  temp_dC      = 3502     ✗ 350.2°C — IC fire?
  pd_contract  = 0 mV @ 0 mA
  faults       = 0
```

The frame CRC is valid; the bytes in the payload are exactly what CH32X put on the wire. The bug is in the **source data**, not transport.

The RP2040 OLED, fed from the same `power.status` stream, mirrors the issue: shows "no battery" + a residual voltage reading.

---

## 2. Hardware context — why the chip is dead

```
USB-C (PPVAR_VBUS_INP)  ┐
                        ├─[ideal-diode OR]─→ PPVAR_INP_COM ─┬─→ ADC: R205(27.4k)/R206(5.1k) → PA1 (DC_INP_ADC_SRC)
Barrel  (PPVAR_DC_INP)  ┘                                   │
                                                            └─→ Q222 P-MOS (gate driven by Q201, controlled by PA6 = DC_INP_EN_SRC)
                                                                       │
                                                                       ↓
                                                                PPVAR_INP_SYS  (10–20 V, only present when mains AND Q222 ON)
                                                                       │
                                                                       ↓
                                                                  MP2762A — IN pin (powers the entire chip including its internal LDO at VCC pin)
```

Key fact: **MP2762A is exclusively powered from `PPVAR_INP_SYS`**. When mains is disconnected, or when Q222 is opened by `DC_INP_EN_SRC = 0`, the chip has no Vcc and is completely dead — its I²C pins do not respond, its ACOK output is undefined, its internal ADC isn't running. The chip cannot fall back to battery-powered operation in this hardware configuration.

When the chip is dead, the bit-banged I²C in `i2c_lib.c::I2C_read_reg()` blindly clocks 8 bits without checking ACK. The dead chip's I/O pins, with their substrate body diodes shunting current from the bus pull-ups to GND, clamp SDA low enough that the master reads **0x00 from every register**. The firmware happily treats those zeros as valid measurements.

The temperature `350.2°C` is the smoking gun. In `mp2762a_get_junction_temp_c10()`:

```c
int32_t dC = ((903 - tj) * 10000) / 2578;   // tj = raw_reg16 >> 6
```

With `raw = 0` → `tj = 0` → `dC = 903 × 10000 / 2578 = 3503` → 350.3°C. Matches exactly what we see.

---

## 3. Why earlier hypotheses are wrong

Two dead ends, documented so we don't go back:

- **"REG 0x0B ADC_START needs re-arming after VIN cycle"** — irrelevant. Chip has no Vcc, can't accept I²C writes anyway. The mp2762a.c:71-77 comment claiming `REG0BH is NOT an ADC config register` is also misleading per datasheet but doesn't matter for this bug.
- **"Use ACOK pin to detect mains state"** — ACOK is an open-drain output of MP2762A. When the chip is dead, the pin's state is whatever R311 (10k pull-up to PP3300_PD) decides, which is "high" = "no input" — coincidentally correct, but it's not a real signal, just the absence of one. Not a reliable source-of-truth.

The **clean** signal is `DC_INP_EN_SRC` (PA6 output) state. The firmware controls this pin via hysteresis on PA1 in `TIM1_UP_IRQHandler` (main.c:1053-1087). When `PA6 = 1`, MP2762A has power; when `PA6 = 0`, it doesn't. Read back the GPIO output register and you know with certainty whether the chip is alive.

---

## 4. Hardware change — already done

The CH32X has a dedicated VBAT ADC pin (PA5 = ADC_Channel_5 = PD_SRC_VBAT) that reads `PPVAR_VBAT+` through a divider:

```
PPVAR_VBAT+ ─── R430 (100k) ─┬─── R431 (47k) ─── GND
                              │
                              ├─── C430 (100 nF) ─── GND     (filter)
                              │
                              ├─── R433 (DNP, now 100R) ─── PA5 (CH32X)
                              │
                              └─── R432 (0R)             ─── VBAT_RP_ADC (RP2040)
```

**Until this fix R433 was DNP**, so PA5 floated and the firmware (correctly) didn't sample it.

**Now**: R433 = 100 Ω soldered. PA5 reads `0.3197 × VBAT` (47/(100+47)).

Schematic reference values:

| VBAT | PA5 voltage |
|---|---|
| 8.4 V | 2.686 V |
| 7.2 V | 2.302 V |
| 6.0 V | 1.918 V |

With CH32X ADC Vref ≈ Vdd ≈ 3.3 V, 12-bit, the formula:

```
VBAT_mV = ADC_count × (3300 / 4096) × ((100 + 47) / 47)
        = ADC_count × 3300 × 147 / (4096 × 47)
        ≈ ADC_count × 10322 / 4096
```

Check at VBAT=8.4 V: ADC ≈ 2.686/3.3 × 4096 ≈ 3333. `3333 × 10322 / 4096 ≈ 8398 mV` ≈ 8.4 V ✓.

R432 stays at 0 Ω (RP2040 side untouched — its calibration and OLED display remain valid).

---

## 5. Required firmware changes

All in `Web3-Pi-UPS/firmware-ch32x/`.

### 5.1 Enable PA5 as analog input — `User/main.c` `ADC_Function_Init()` (~ line 1163)

Current code at line 1177-1180:

```c
//PA5: input floating (battery ADC divider - not used, MP2762A provides VBAT)
GPIO_InitStructure.GPIO_Pin = GPIO_Pin_5;
GPIO_InitStructure.GPIO_Mode = GPIO_Mode_IN_FLOATING;
GPIO_Init(GPIOA, &GPIO_InitStructure);
```

Change to analog mode:

```c
//PA5: PD_SRC_VBAT — battery voltage ADC via R430/R431 divider (R433=100R since 2026-05-11)
GPIO_InitStructure.GPIO_Pin = GPIO_Pin_5;
GPIO_InitStructure.GPIO_Mode = GPIO_Mode_AIN;
GPIO_Init(GPIOA, &GPIO_InitStructure);
```

Note: the existing init only configures ADC for `ADC_Channel_1` (line 1195). `Get_ADC_Val(uint8_t ch)` at line 1142 calls `ADC_RegularChannelConfig(ADC1, ch, ...)` dynamically each call, so it can sample `ADC_Channel_5` on demand without additional init. Verify this works (the channel switch + EOC poll path is shared). If `Get_ADC_Val()` returns 0 or garbage for ch=5, add an explicit `ADC_RegularChannelConfig(ADC1, ADC_Channel_5, 1, ADC_SampleTime_11Cycles)` call somewhere reasonable.

### 5.2 Sample PA5 periodically and cache — `User/main.c` (TIM1 IRQ or main loop)

Option A (preferred — main loop, just before `wups_send_power_status`):

```c
// Add near other static globals (~line 81 area)
volatile u16    Vbat_ADC_Val = 0;
static UINT16   Vbat_Voltage_mV = 0;

// In the main loop's 1 Hz block (around line 1027 where DC_Inp_Voltage_mV is computed):
Vbat_ADC_Val    = Get_ADC_Val(ADC_Channel_5);
Vbat_Voltage_mV = (UINT16)((UINT32)Vbat_ADC_Val * 10322u / 4096u);
DC_Inp_Voltage_mV = (UINT16)((UINT32)DC_Inp_ADC_Val * 21029u / 4096u);
wups_send_power_status(WUPS_ADDR_RP2040, WUPS_FLAG_EVENT, Wups_Tx_Seq++);
```

Option B (TIM1 IRQ — only if you want faster updates than 1 Hz). The IRQ already does one `Get_ADC_Val` per tick for PA1; adding a second call costs ~1.4 µs and is fine. But the WUPS frame only emits at 1 Hz so there's no consumer for higher-rate samples — Option A is cleaner.

### 5.3 Detect "MP2762A powered" cleanly — new helper

In `User/main.c` near other static helpers:

```c
// True iff PA6 (DC_INP_EN_SRC) is currently driving Q222 ON, which is the
// only condition under which MP2762A has VCC. When this returns false, do
// not touch the I²C bus to address 0x5C — every read will return 0x00 from
// the dead chip's clamped pins and pollute Chg_Data with bogus values.
static inline UINT8 mp2762a_powered(void) {
    return (GPIO_ReadOutputDataBit(GPIOA, GPIO_Pin_6) == Bit_SET) ? 1 : 0;
}
```

### 5.4 Skip MP2762A reads when dead — `User/mp2762a.c` `mp2762a_read_all()` (line 324)

Add early-out at the top. Either: a) export `mp2762a_powered()` to mp2762a.c via a header, or b) take a "powered" hint as a parameter, or c) do the GPIO read inline. Option (a) is cleanest:

```c
void mp2762a_read_all(mp2762a_data_t *data) {
    extern UINT8 mp2762a_powered(void);   // or move helper to a shared header

    if (!mp2762a_powered()) {
        data->chg_state  = CHG_STATE_NOT_CHARGING;  // semantically "discharging" — see §6
        data->power_good = 0;
        data->vin_mv     = 0;
        data->iin_ma     = 0;
        data->vbat_mv    = 0;       // signal: not measured here (PA5 path owns this on battery)
        data->ichg_ma    = 0;
        data->vsys_mv    = 0;
        data->tjunc_c10  = INT16_MIN;  // sentinel "n/a" — see §5.6
        data->fault      = 0;
        return;
    }

    // ... rest of existing function unchanged
}
```

### 5.5 Swap data sources in `wups_send_power_status` — `User/main.c` line 489

Current (lines 493-507):

```c
s.vbus_in_mV  = (uint16_t)Chg_Data.vin_mv;   // ← MP2762A: zeros when on battery
// ...
s.vbat_mV     = (uint16_t)Chg_Data.vbat_mv;  // ← same problem
// ...
{
    int16_t lm = Board_Temp_c10;
    int16_t tj = Chg_Data.tjunc_c10;
    s.temp_dC = (tj > lm) ? tj : lm;          // ← 350.3°C from raw=0
}
```

After (replace exactly these lines):

```c
// vbus_in: always from our own PA1 ADC. Works in every state — mains
// present, mains absent, Q222 cut, MP2762A dead. The MP2762A's VIN
// reading is redundant and unavailable on battery; we ignore it.
s.vbus_in_mV  = DC_Inp_Voltage_mV;
// ...
// vbat: always from our own PA5 ADC. Available whether MP2762A is alive
// or not; with mains on and no battery present, MP2762A's BATTFET leakage
// can leave residual voltage on PPVAR_VBAT+, but that's a separate
// edge-case handled below (faults flag).
s.vbat_mV     = Vbat_Voltage_mV;
// ...
{
    int16_t lm = Board_Temp_c10;
    int16_t tj = Chg_Data.tjunc_c10;
    // Skip MP2762A's TJ when the chip is unpowered — it's INT16_MIN
    // (sentinel set in mp2762a_read_all). Use LM75B alone in that case.
    s.temp_dC = (tj == INT16_MIN) ? lm : ((tj > lm) ? tj : lm);
}
```

### 5.6 `INT16_MIN` sentinel

If `INT16_MIN` is not already imported, `#include <stdint.h>` and use `INT16_MIN` or define `MP2762A_TJ_NA (-32768)`. Don't pick `0` as the sentinel because 0 °C / 0.0 dC is a legitimate reading on a cold device.

### 5.7 `charge_state` and `ibat_mA` on battery

After §5.4, when on battery `Chg_Data.chg_state = CHG_STATE_NOT_CHARGING (0)` and `ibat_ma = 0`. The downstream `wups_power_status_v1_t::charge_state` semantics in `common/protocol.h` say `0=idle 1=charging 2=charged 3=fault`. There's no "discharging" code today. Two options:

- **Now**: leave `0` (NOT_CHARGING) as the on-battery indicator. The panel can derive "on battery" from `vbus_in_mV < 4500 && vbat_mV > 2500` (it already does — see `panel/api/lib/wupsproto.ts::powerToSnapshotPart`).
- **Later (protocol v2)**: add a dedicated state, e.g. `4 = DISCHARGING`. Out of scope for this hotfix.

Battery discharge current measurement is **physically unavailable** with current hardware — MP2762A is dead, there's no shunt on the BATT→VSYS path readable by CH32X. `ibat_mA = 0` is the best we can do until a hardware addition (shunt + amp into a free CH32X ADC channel).

### 5.8 Move `mp2762a_powered()` helper to a shared header (optional but tidy)

Put the inline in `mp2762a.h` (or a new small `power_state.h`) so both `main.c` and `mp2762a.c` can use it without `extern` games.

---

## 6. Verification plan

After flashing, **before merging**:

1. **Sanity check PA5 reading via serial debug**. Add a temporary printf next to the Vbat sampling:

   ```c
   printf("VBAT: raw=%u mv=%u\r\n", Vbat_ADC_Val, Vbat_Voltage_mV);
   ```

   With mains on **and** battery connected (fully charged): expect `raw ≈ 3300–3340` and `mv ≈ 8300–8400`. Measure with a multimeter across the battery and confirm ±2%.

2. **Without battery, mains on**: PA5 will read whatever BATTFET leakage holds on the BATT cap bank (C322–C326 = ~50 µF + C320 1 µF + C321 1 µF on `PPVAR_VBAT+`). This may settle anywhere from `0 V` to `VSYS − Vf(body diode)` depending on the chip's BATTFET state. **Don't use this run for calibration**. Use it just to verify the reading isn't pinned at 4096 (would indicate ADC misconfig).

3. **Battery only (mains pulled)**: PA5 should read true VBAT continuously. Multimeter cross-check expected ±2%. If gain or offset is off by more than ~5%, the math constant `10322` needs adjustment per actual measured Vdd of CH32X (the ADC ratiometric to Vdd, not to a 3.3 V reference — if the 3V3 rail is actually 3.28 V or 3.32 V under the load, scale changes proportionally).

4. **Capture a `power.status` frame in each state** via the WUPS MQTT debug tool (`Web3-Pi-UPS-Panel/tools/mqtt-debug/index.html`). Expected fields after fix:

   | state             | vbus_in | vbat       | temp                 | charge_state |
   |-------------------|---------|------------|----------------------|--------------|
   | mains, charging   | ~12000  | 6000–8400  | ~max(LM75B, MP2762A) | 1 (FAST)     |
   | mains, full       | ~12000  | ~8400      | same                 | 2 (DONE)     |
   | battery only      | 0       | true VBAT  | LM75B only           | 0 (NOT_CHG)  |
   | no input, no bat  | 0       | ~0         | LM75B only           | 0            |

   Specifically: **`temp_dC` MUST NEVER be 3502 again**. If it is, §5.5 or §5.4 didn't take.

5. **OLED check on RP2040 side**: pull mains, confirm display shows real VBAT (~8 V) and not "no battery". RP2040 firmware is **not** changed in this fix; it derives its UI state from the same `power.status` frame, so once CH32X reports honest data the OLED follows.

6. **No-regression check with mains on**: charging state, ACOK, temperature, etc. should look exactly like before this change. The §5.5 swap only changes which source feeds `vbus_in_mV` and `vbat_mV`; for mains-on this is a wash (PA1 and MP2762A agree on VIN within ADC tolerance, PA5 and MP2762A agree on VBAT within ADC tolerance).

---

## 7. Out of scope (separate commits)

These items are tangentially related, do **not** fix as part of this hotfix:

- **`ibus_out_mA = 5000` always**: `Tps_Iread_a10` is the TPS55289 current-limit register, not a measurement. The field name in the frame implies measurement; consumers (panel, OLED) treat it as such. Either change the source, rename the field, or document explicitly. Latent UX bug, not data-corruption.
- **`pd_contract_mV/_mA` aliased to VSYS/IIN**: documented hack in `wups_send_power_status` lines 509-525. Becomes a real protocol bug if anything starts reading these fields literally. Resolve in protocol v2.
- **Misleading comment in `mp2762a.c:71-77`** about REG 0x0B not being ADC config — datasheet says otherwise. Doesn't impact this fix (chip is dead anyway, can't write any register).
- **v3 dead code**: per the user, the v3 hardware moves all SINK-side PD work to a dedicated PD-Trigger IC. The CH32X firmware still contains dual-role state machine, `PD_Switch_To_Sink`, `PD_Role_Manager_Tick`, and references to `PB11 = PDC_CC_DET` / `PB3 = PDC_CC_SEL` that are NC on v3. Removing this code frees flash (62 KB target is tight) and eliminates any risk of stray GPIO activity on reused pins. Audit + clean as a separate pass.
- **Discharging state in protocol** (see §5.7): add `wups_power_status_v1_t::charge_state = 4 (DISCHARGING)` and bump struct version. Coordinate with RP2040 OLED and panel decoders.

---

## 8. Files touched by this fix

```
Web3-Pi-UPS/firmware-ch32x/User/main.c        (ADC_Function_Init, main loop, wups_send_power_status)
Web3-Pi-UPS/firmware-ch32x/User/mp2762a.c     (mp2762a_read_all early-out)
Web3-Pi-UPS/firmware-ch32x/User/mp2762a.h     (optional: move mp2762a_powered() helper here)
```

No changes to:
- `Web3-Pi-UPS/common/protocol.h` (protocol schema unchanged)
- `Web3-Pi-UPS/firmware-rp2040/**` (RP2040 reads the same frame, will see correct data automatically)
- `Web3-Pi-UPS-Panel/**` (backend/parser unchanged)

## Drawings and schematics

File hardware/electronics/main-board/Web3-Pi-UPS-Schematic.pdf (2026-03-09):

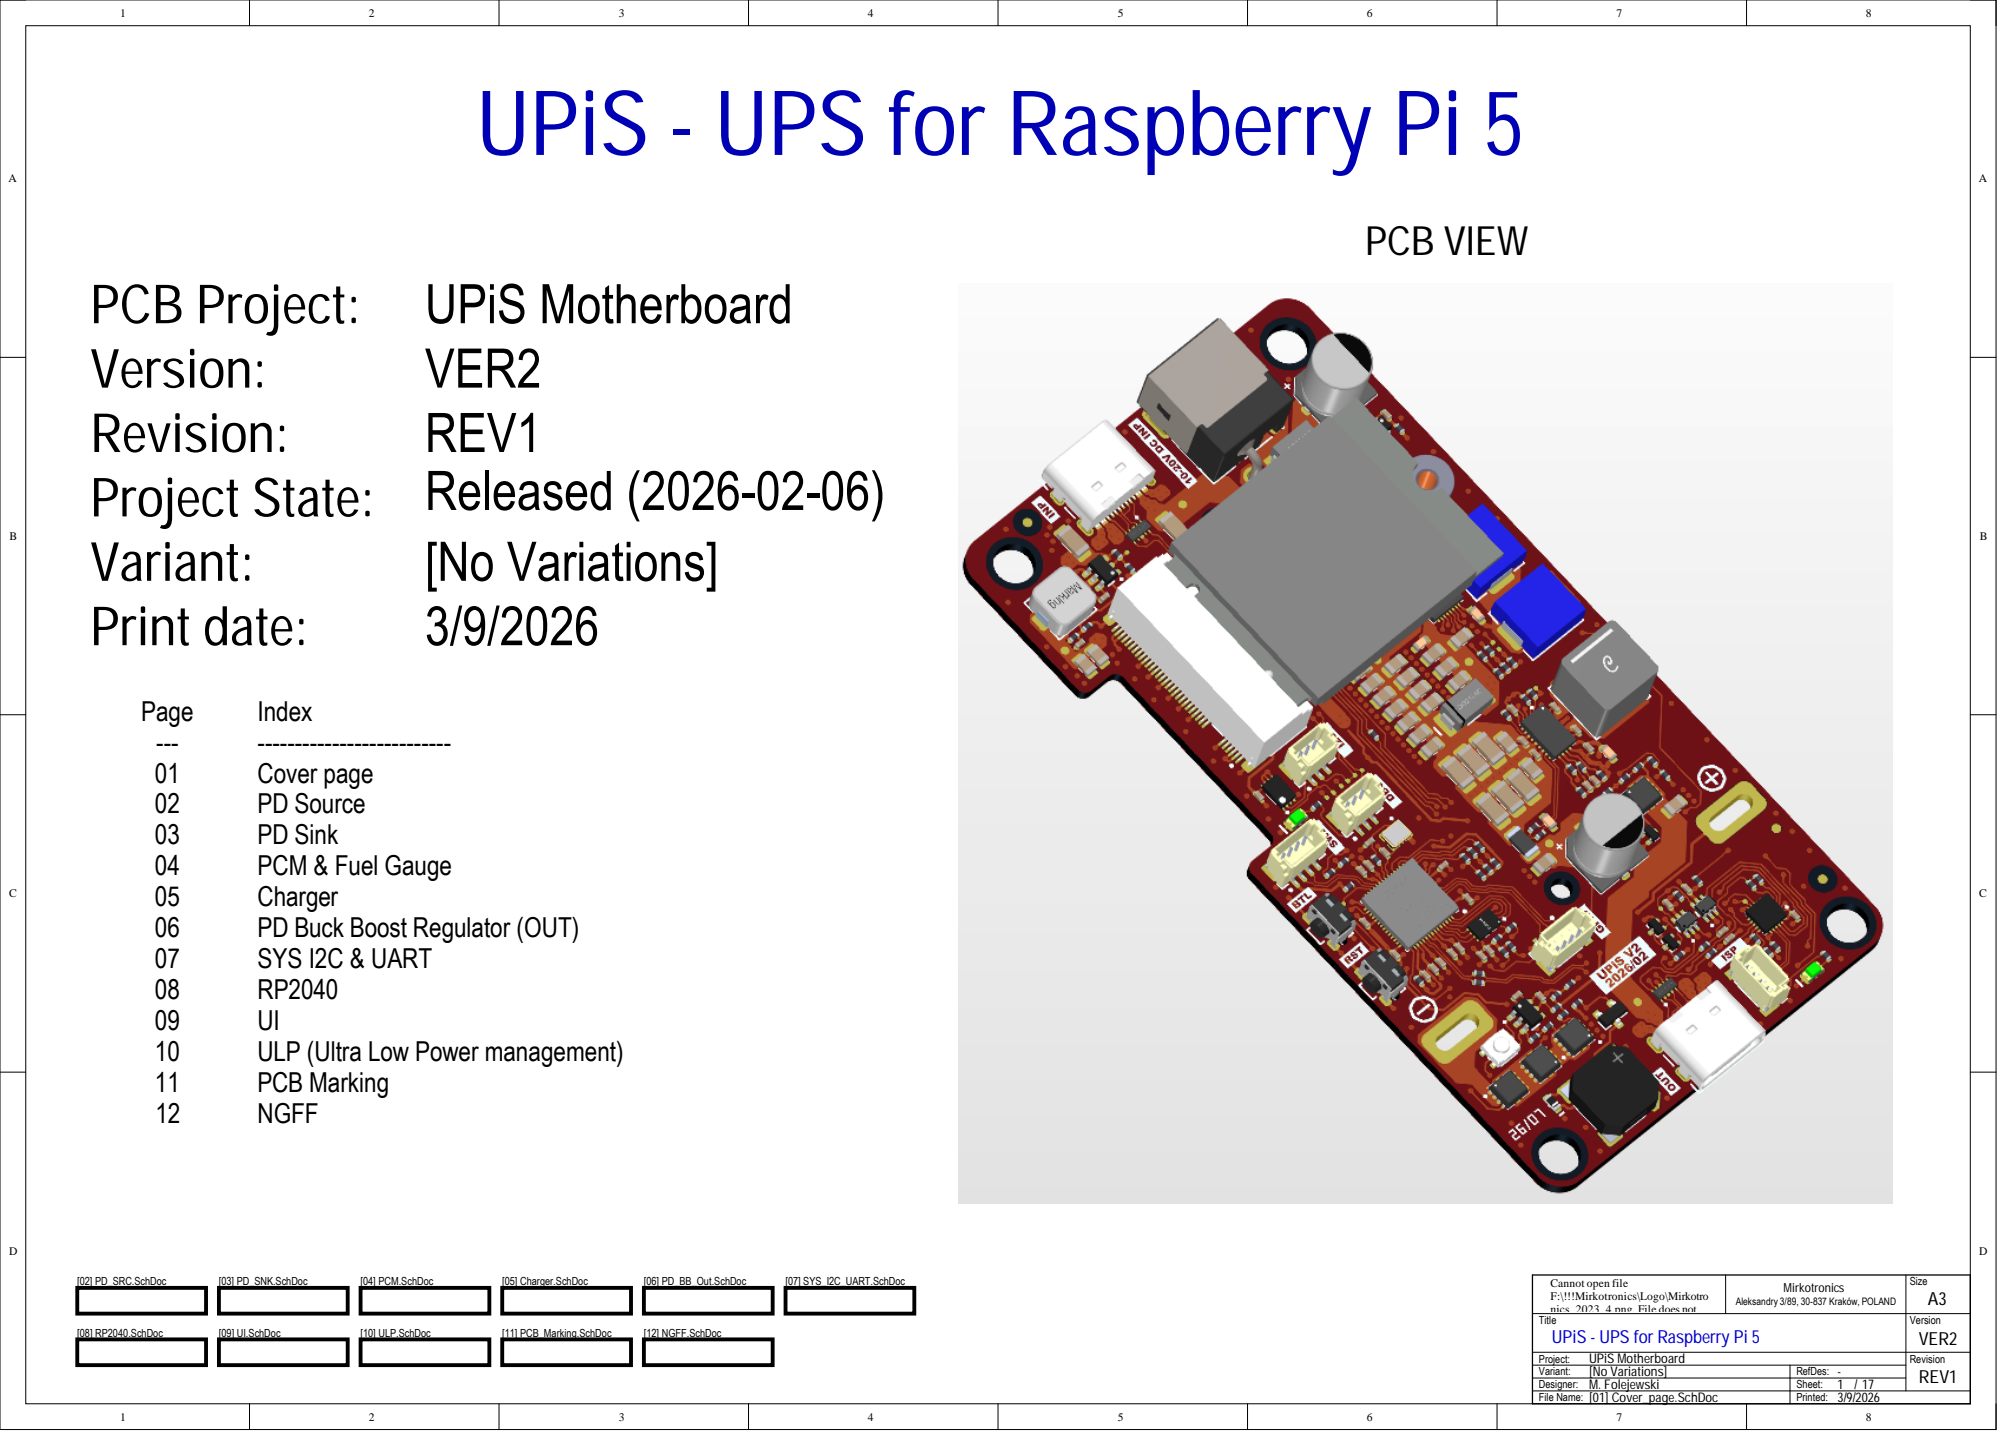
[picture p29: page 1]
PCB VIEW; Project State:; PCB Project:; [No Variations]; Released (2026-02-06); UPiS Motherboard; Print date:; [02] PD_SRC.SchDoc; [03] PD_SNK.SchDoc; [04] PCM.SchDoc; [05] Charger.SchDoc; [06] PD_BB_Out.SchDoc; [07] SYS_I2C_UART.SchDoc; [08] RP2040.SchDoc; [09] UI.SchDoc; [10] ULP.SchDoc; [11] PCB_Marking.SchDoc; [12] NGFF.SchDoc

UPiS - UPS for Raspberry Pi 5

Index
Cover page
PD Source
PD Sink
PCM & Fuel Gauge
Charger
PD Buck Boost Regulator (OUT)
SYS I2C & UART
ULP (Ultra Low Power management)
PCB Marking
NGFF

Cannot open file F:\!!!Mirkotronics\Logo\Mirkotro nics_2023_4.png. File does not | Mirkotronics Aleksandry 3/89, 30-837 Kraków, POLAND | Size A3

Title UPiS - UPS for Raspberry Pi 5 | | Version VER2

Project: UPiS Motherboard | | Revision REV1
Variant: [No Variations] | RefDes: -
Designer: M. Folejewski | Sheet: 1 17 /
File Name: [01] Cover_page.SchDoc | Printed: 3/9/2026

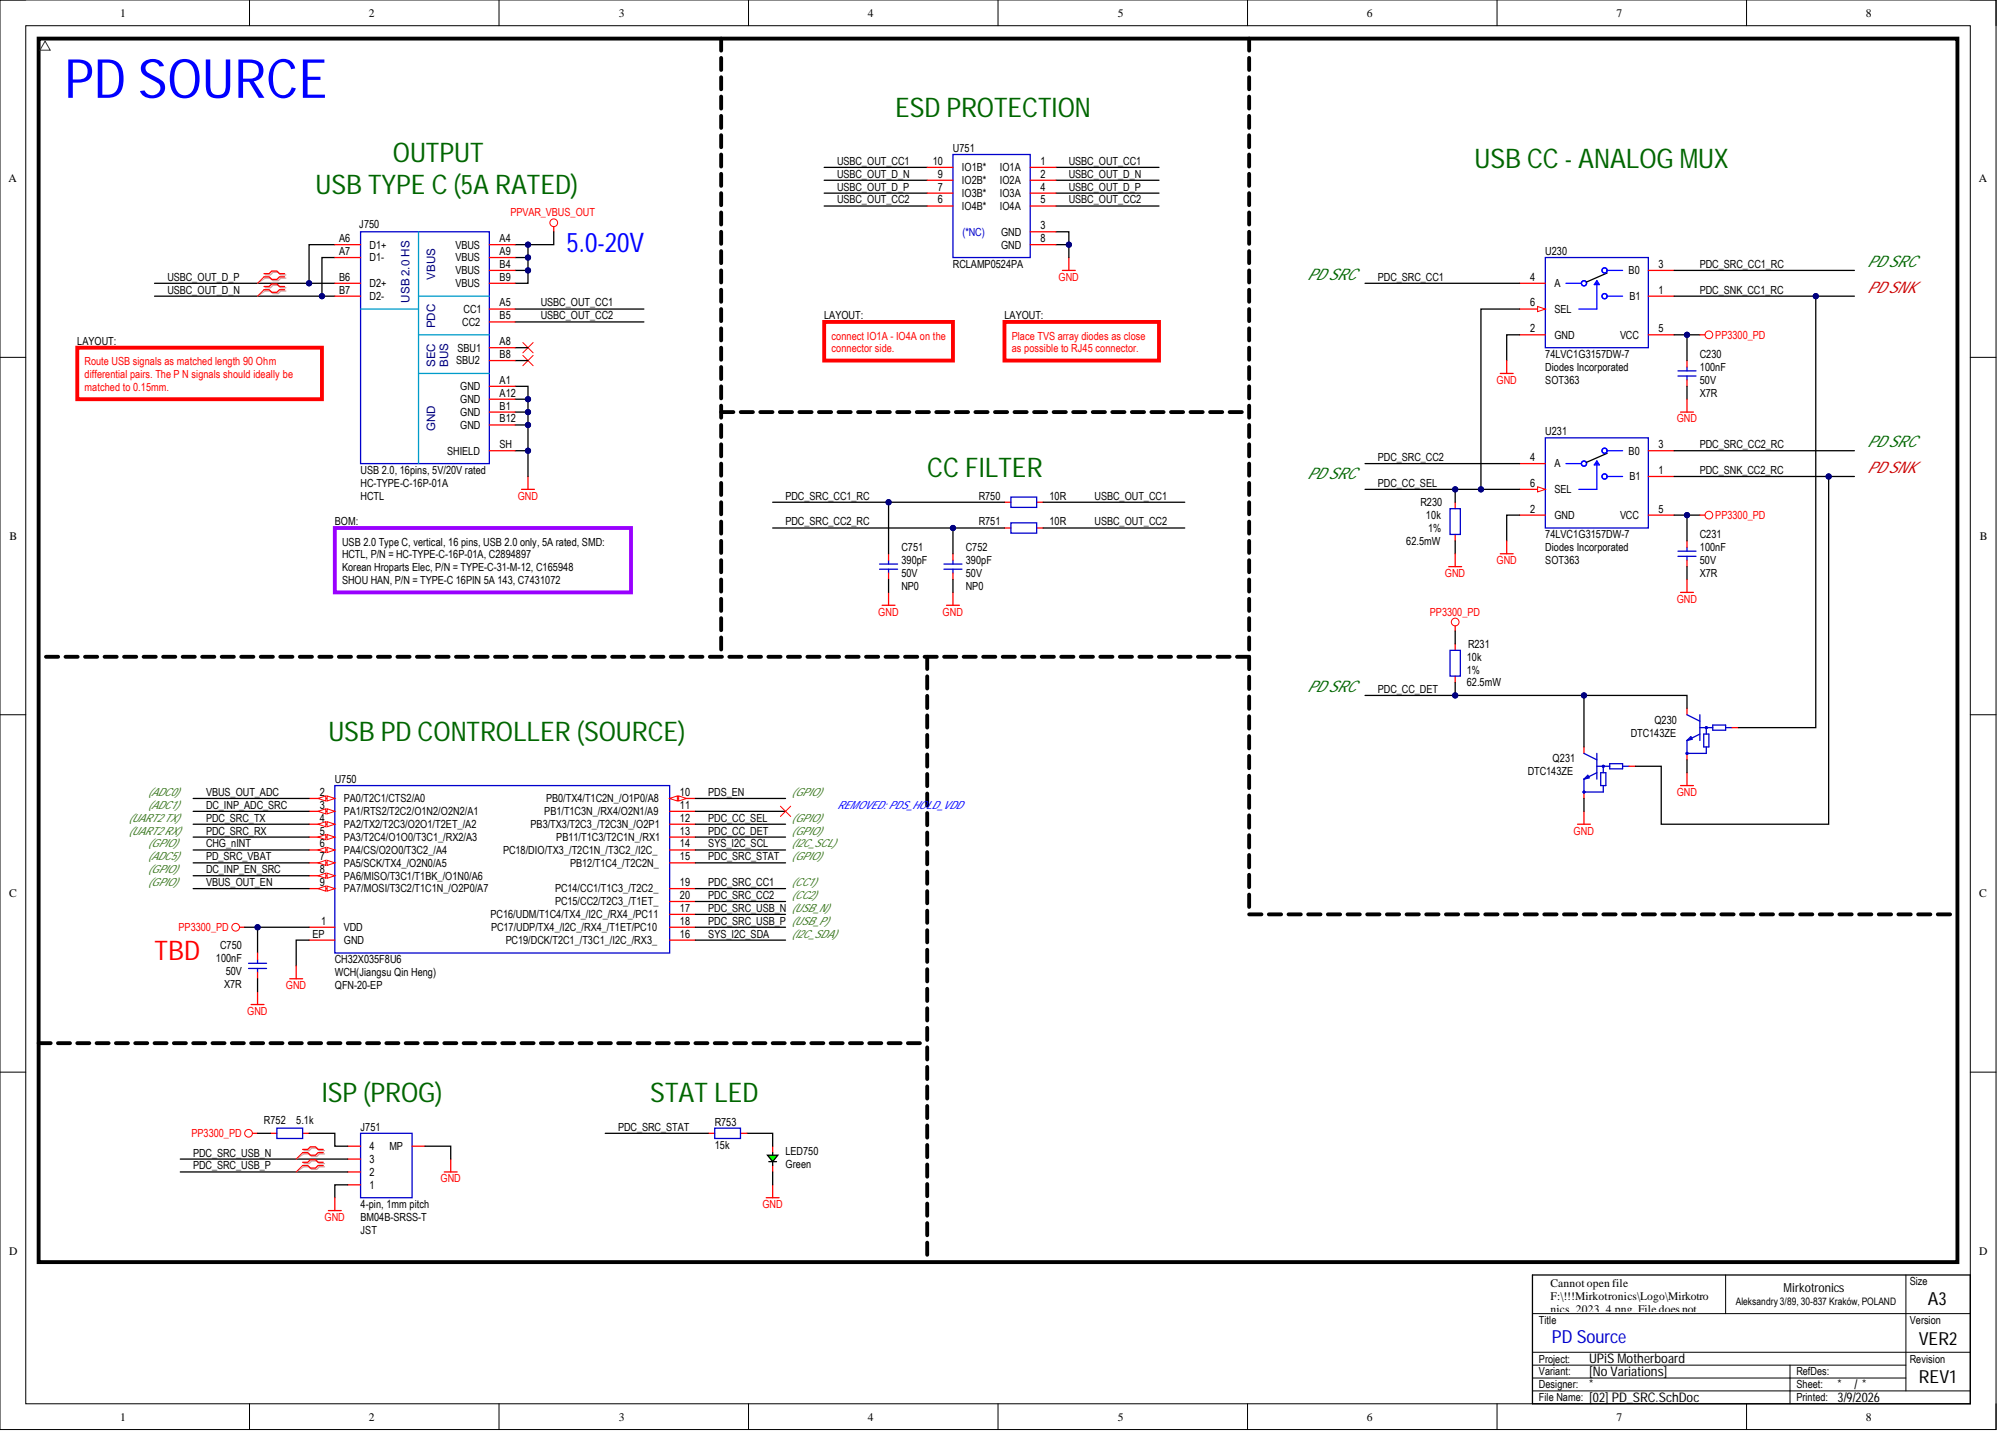
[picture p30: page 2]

USB CC - ANALOG MUX

GND VBUS PDC SEC

LAYOUT:
Place TVS array diodes as close
as possible to RJ45 connector.

Route USB signals as matched length 90 Ohm
differential pairs. The P N signals should ideally be
matched to 0.15mm.

BOM:
USB 2.0 Type C, vertical, 16 pins, USB 2.0 only, 5A rated, SMD:
HCTL, P/N = HC-TYPE-C-16P-01A, C2894897
Korean Hroparts Elec, P/N = TYPE-C-31-M-12, C165948
SHOU HAN, P/N = TYPE-C 16PIN 5A 143, C7431072

USB PD CONTROLLER (SOURCE)

WCH(Jiangsu Qin Heng)
QFN-20-EP

Cannot open file F:\!!!Mirkotronics\Logo\Mirkotro | Mirkotronics Aleksandry 3/89, 30-837 Kraków, POLAND | Size A3

PD Source | | VER2

RefDes:

Designer: * | * *
File Name: [02] PD_SRC.SchDoc | Printed:

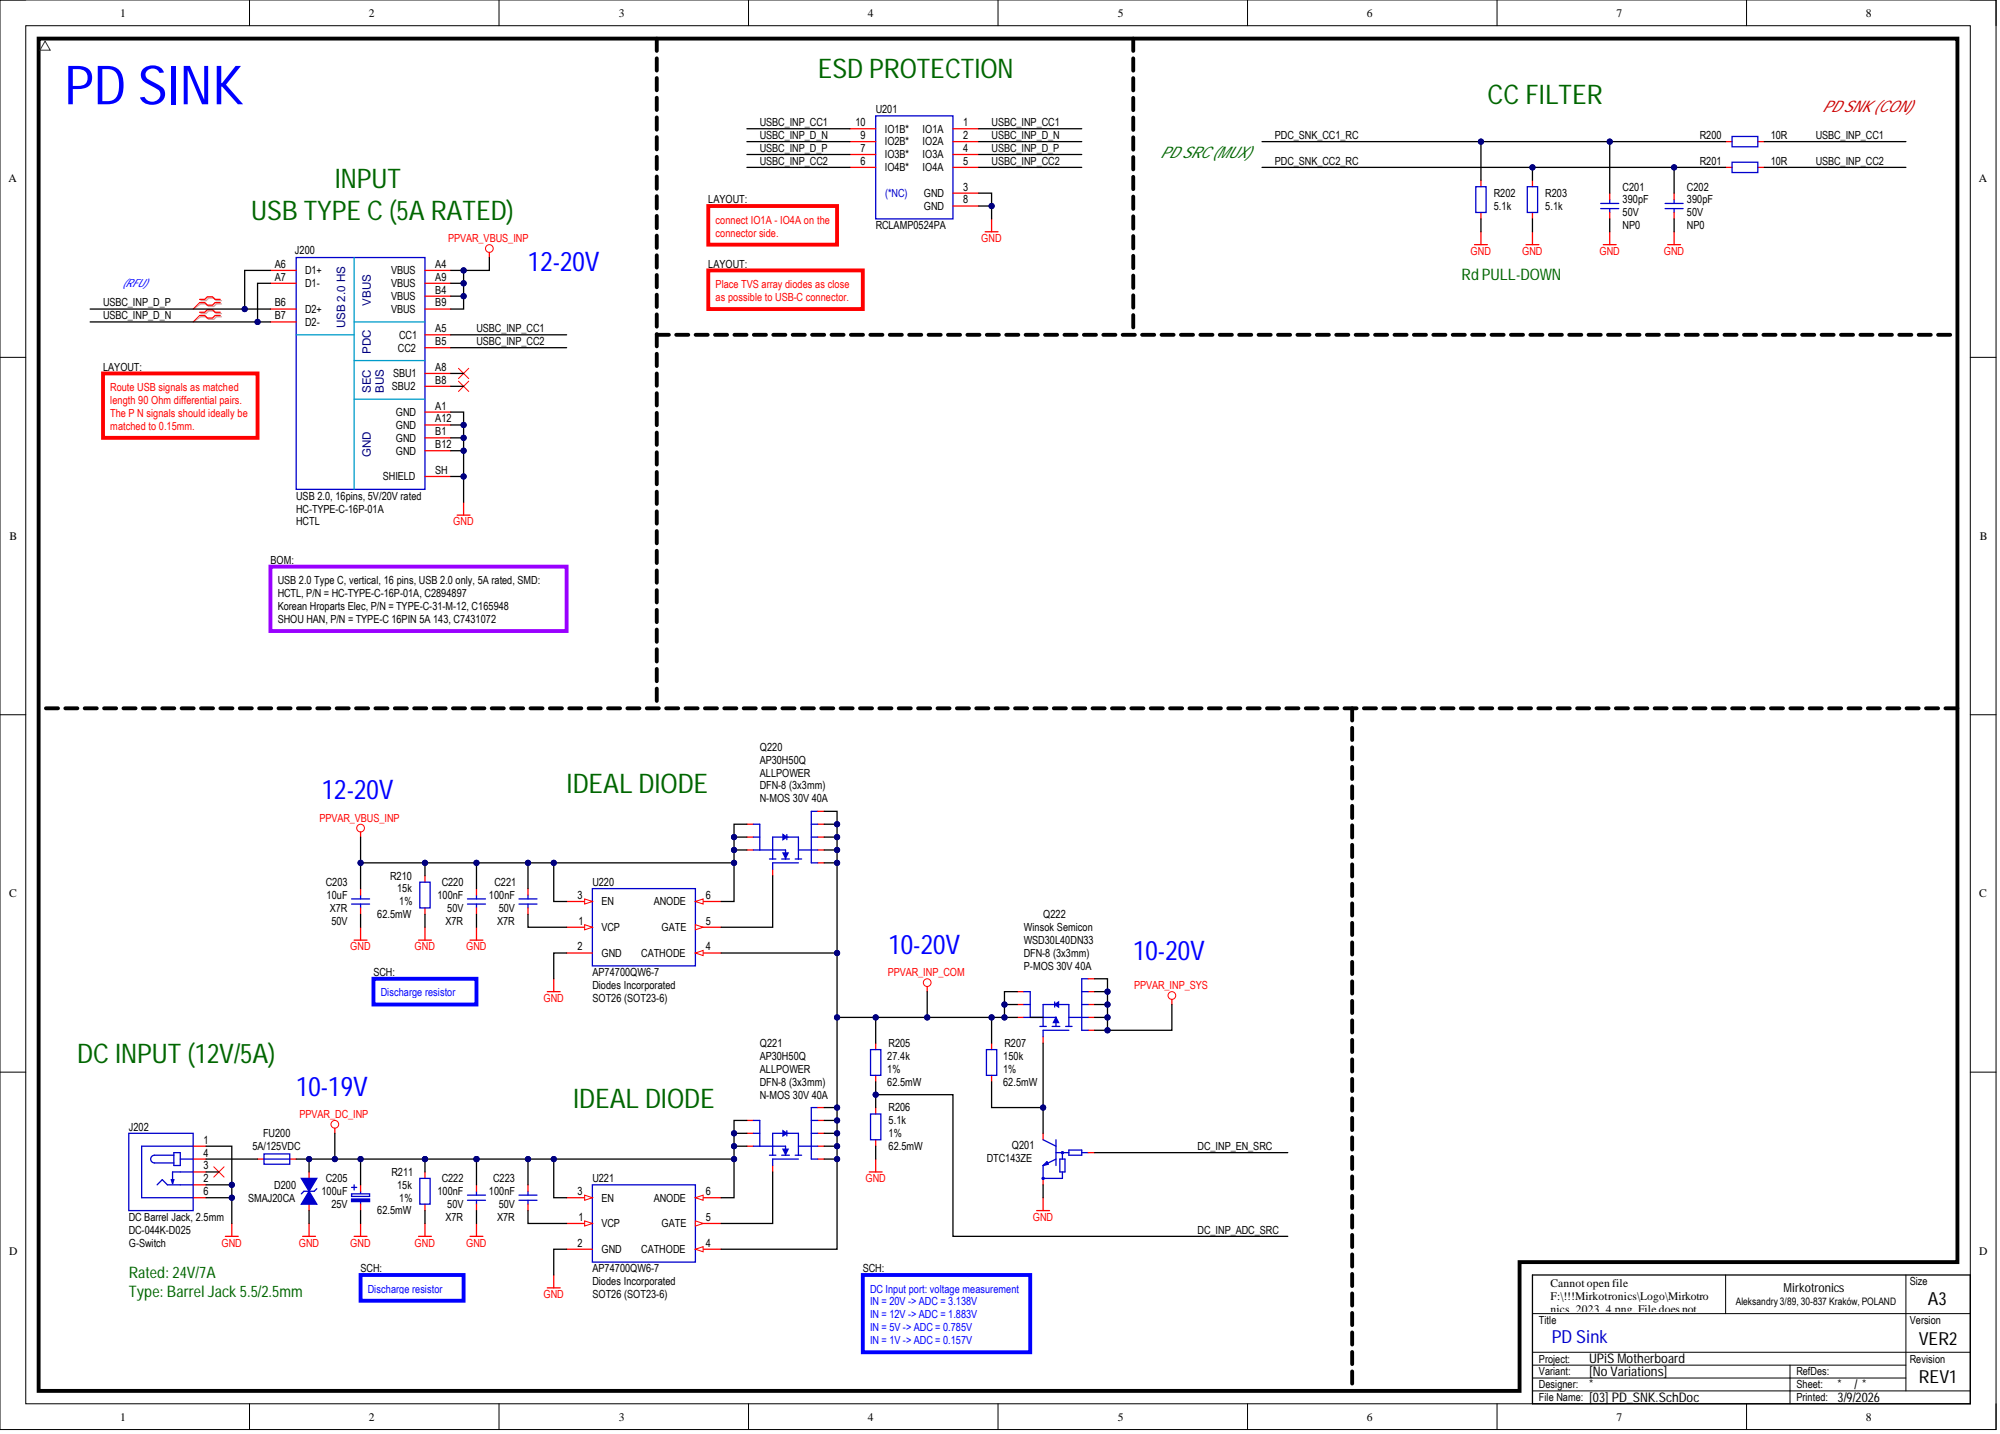
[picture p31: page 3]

LAYOUT:
Place TVS array diodes as close
as possible to USB-C connector.

GND VBUS PDC SEC

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

SCH:
DC Input port: voltage measurement
IN = 20V -> ADC = 3.138V
IN = 12V -> ADC = 1.883V
IN = 5V -> ADC = 0.785V
IN = 1V -> ADC = 0.157V

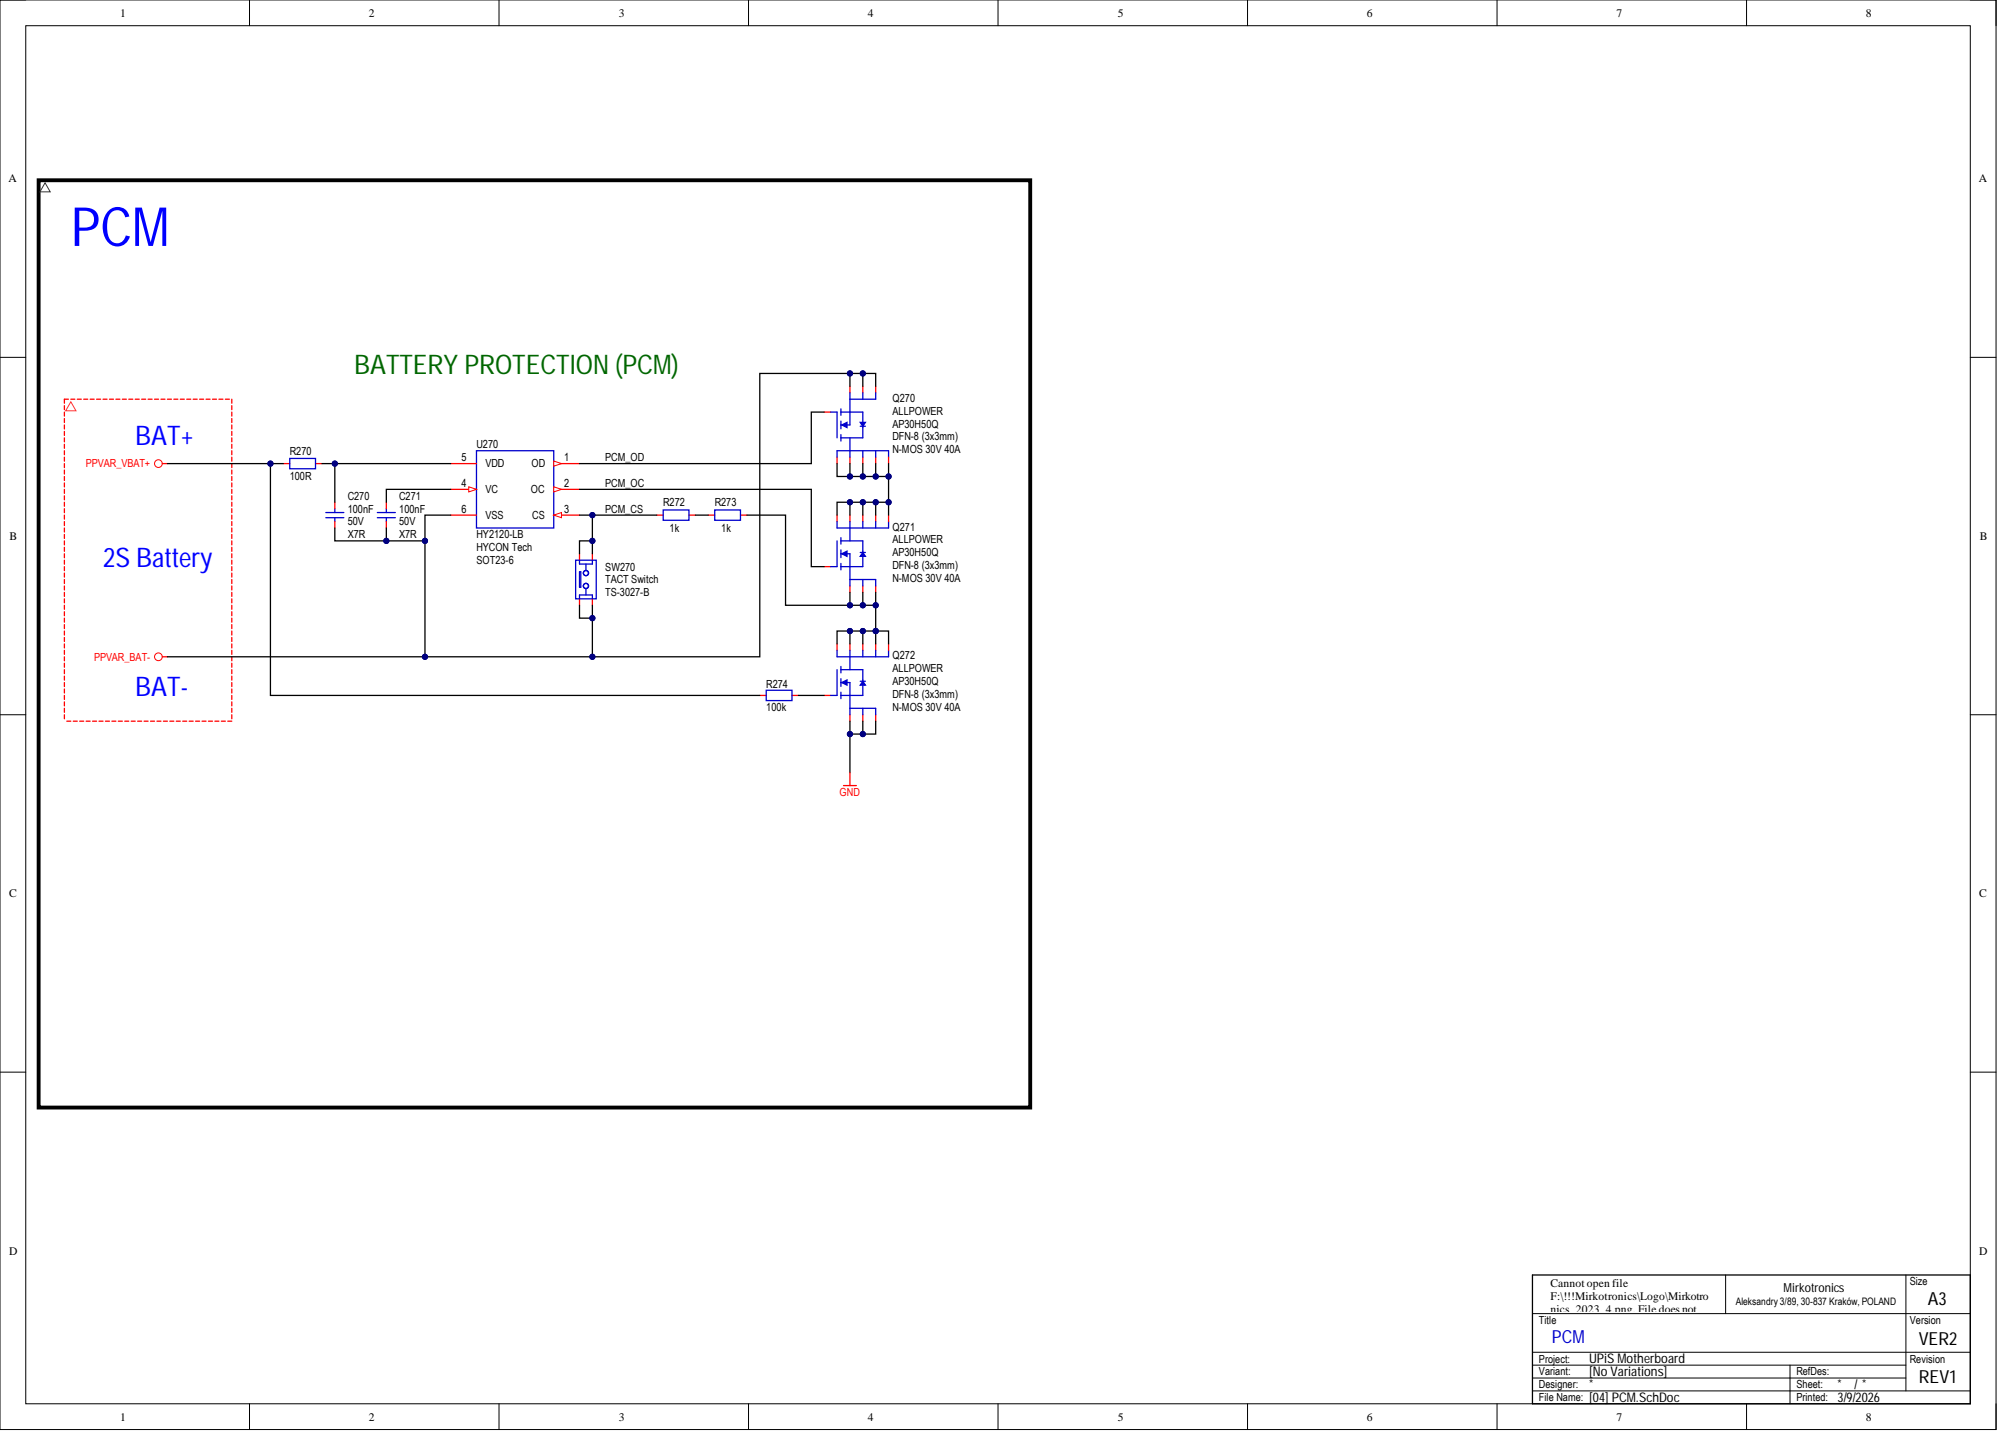
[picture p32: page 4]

PCM_OD

100nF | OC | 2 VC 4 | PCM_OC

C271 | | VSS 6 | | | R272 R273

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

PCM | | VER2

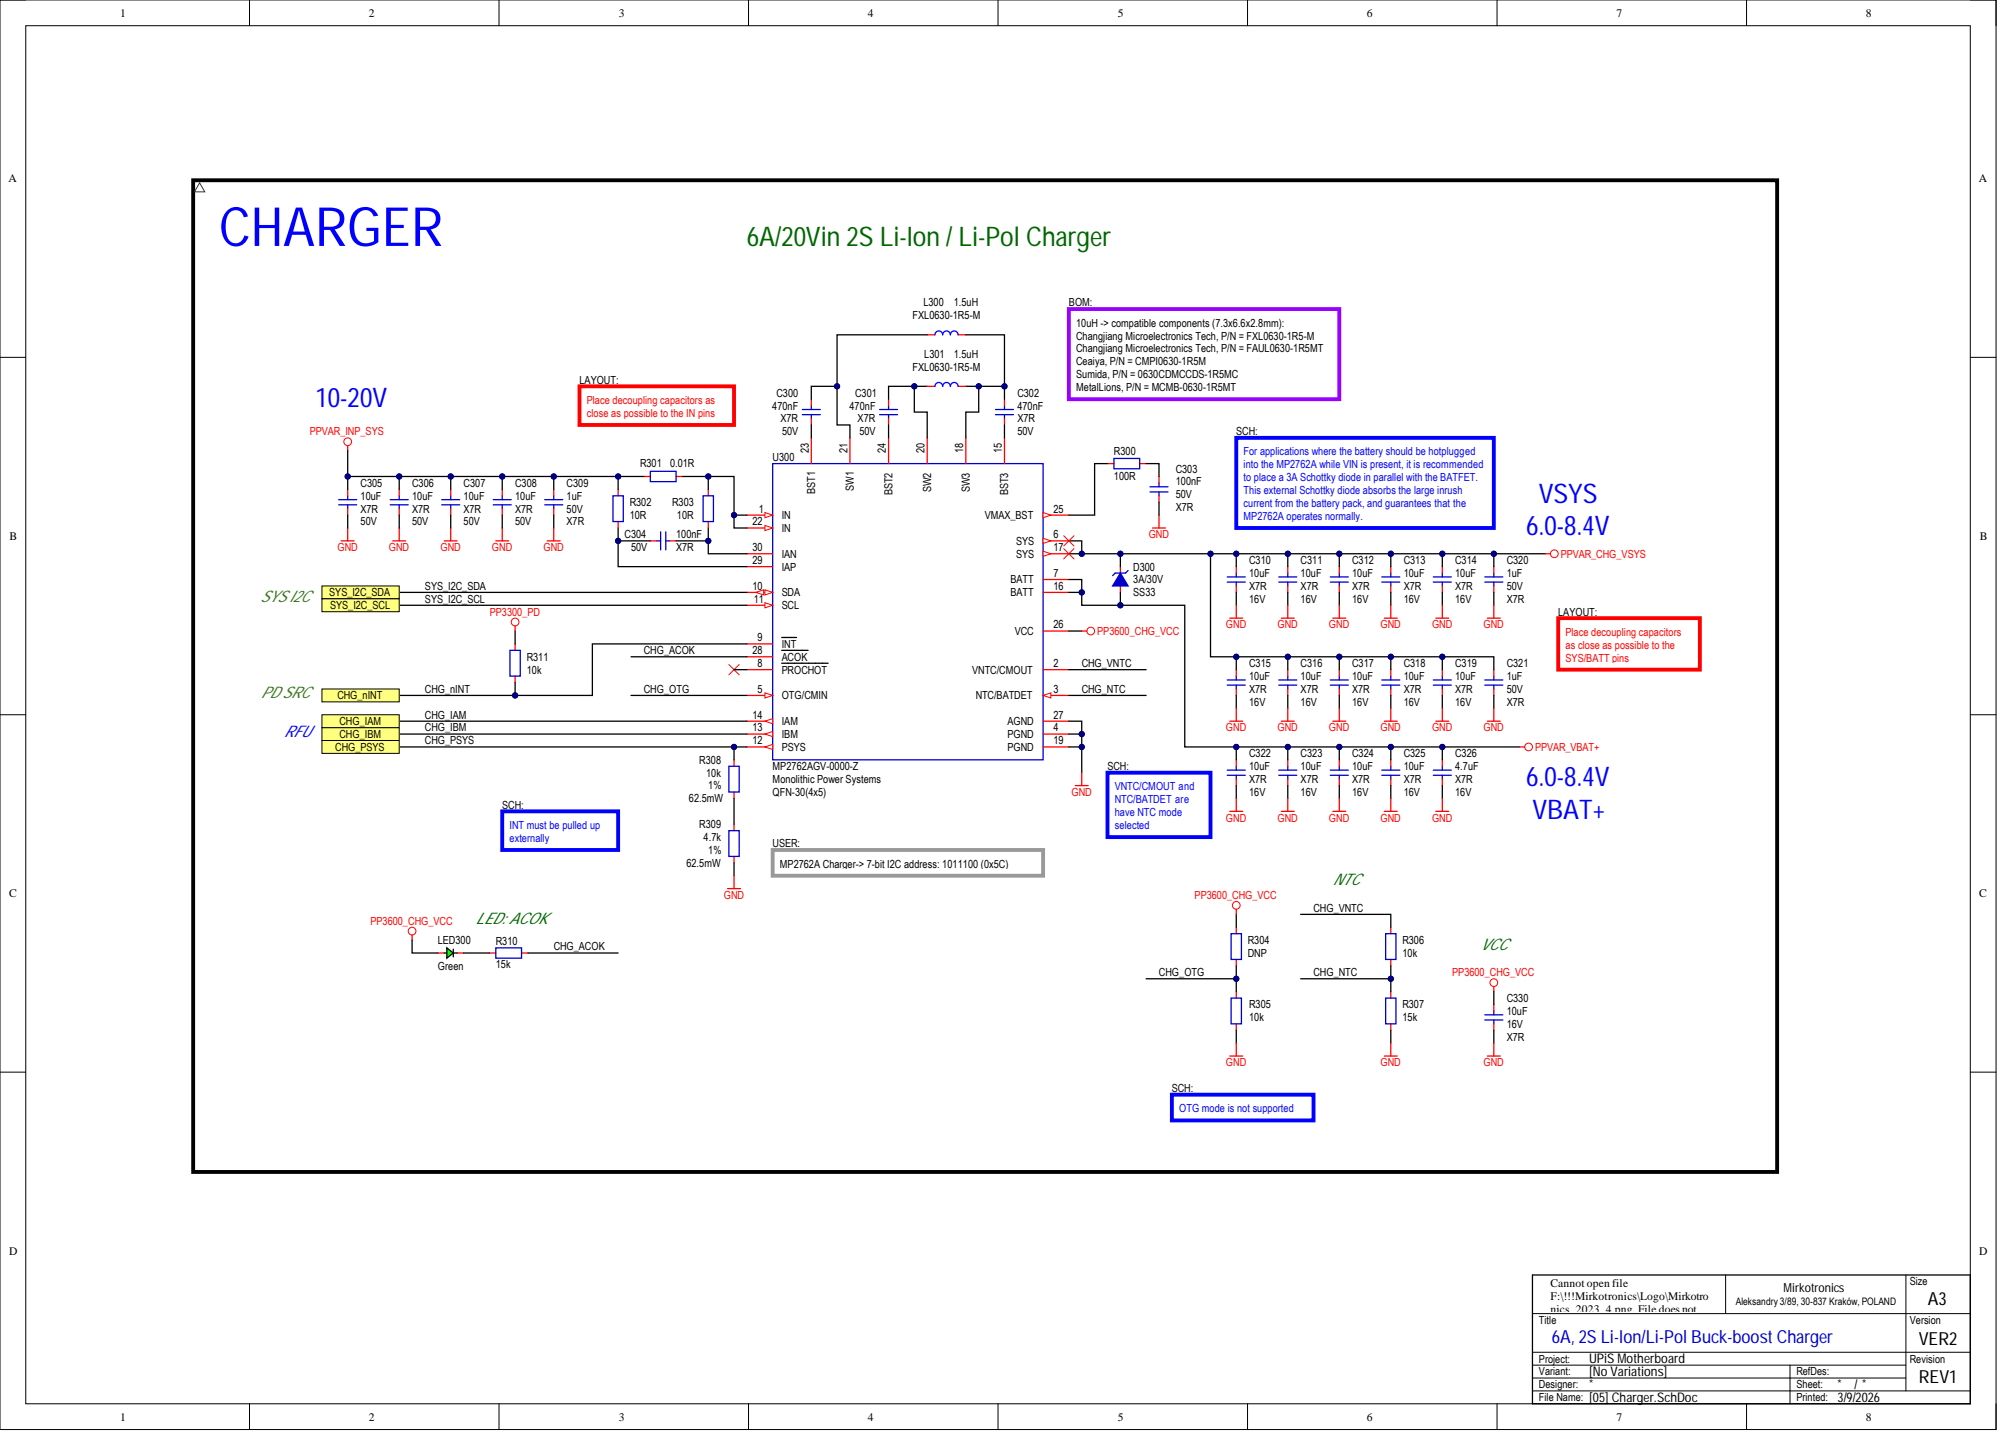
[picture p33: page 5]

6A/20Vin 2S Li-Ion / Li-Pol Charger

LAYOUT:
Place decoupling capacitors as
close as possible to the IN pins

SCH:
For applications where the battery should be hotplugged
into the MP2762A while VIN is present, it is recommended
to place a 3A Schottky diode in parallel with the BATFET.
This external Schottky diode absorbs the large inrush
current from the battery pack, and guarantees that the
MP2762A operates normally.

Place decoupling capacitors
as close as possible to the
SYS/BATT pins

INT 9 | PP3600_CHG_VCC CHG_VNTC
ACOK 28 PROCHOT 8

INT must be pulled up
externally

OTG mode is not supported

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

6A, 2S Li-Ion/Li-Pol Buck-boost Charger | | VER2

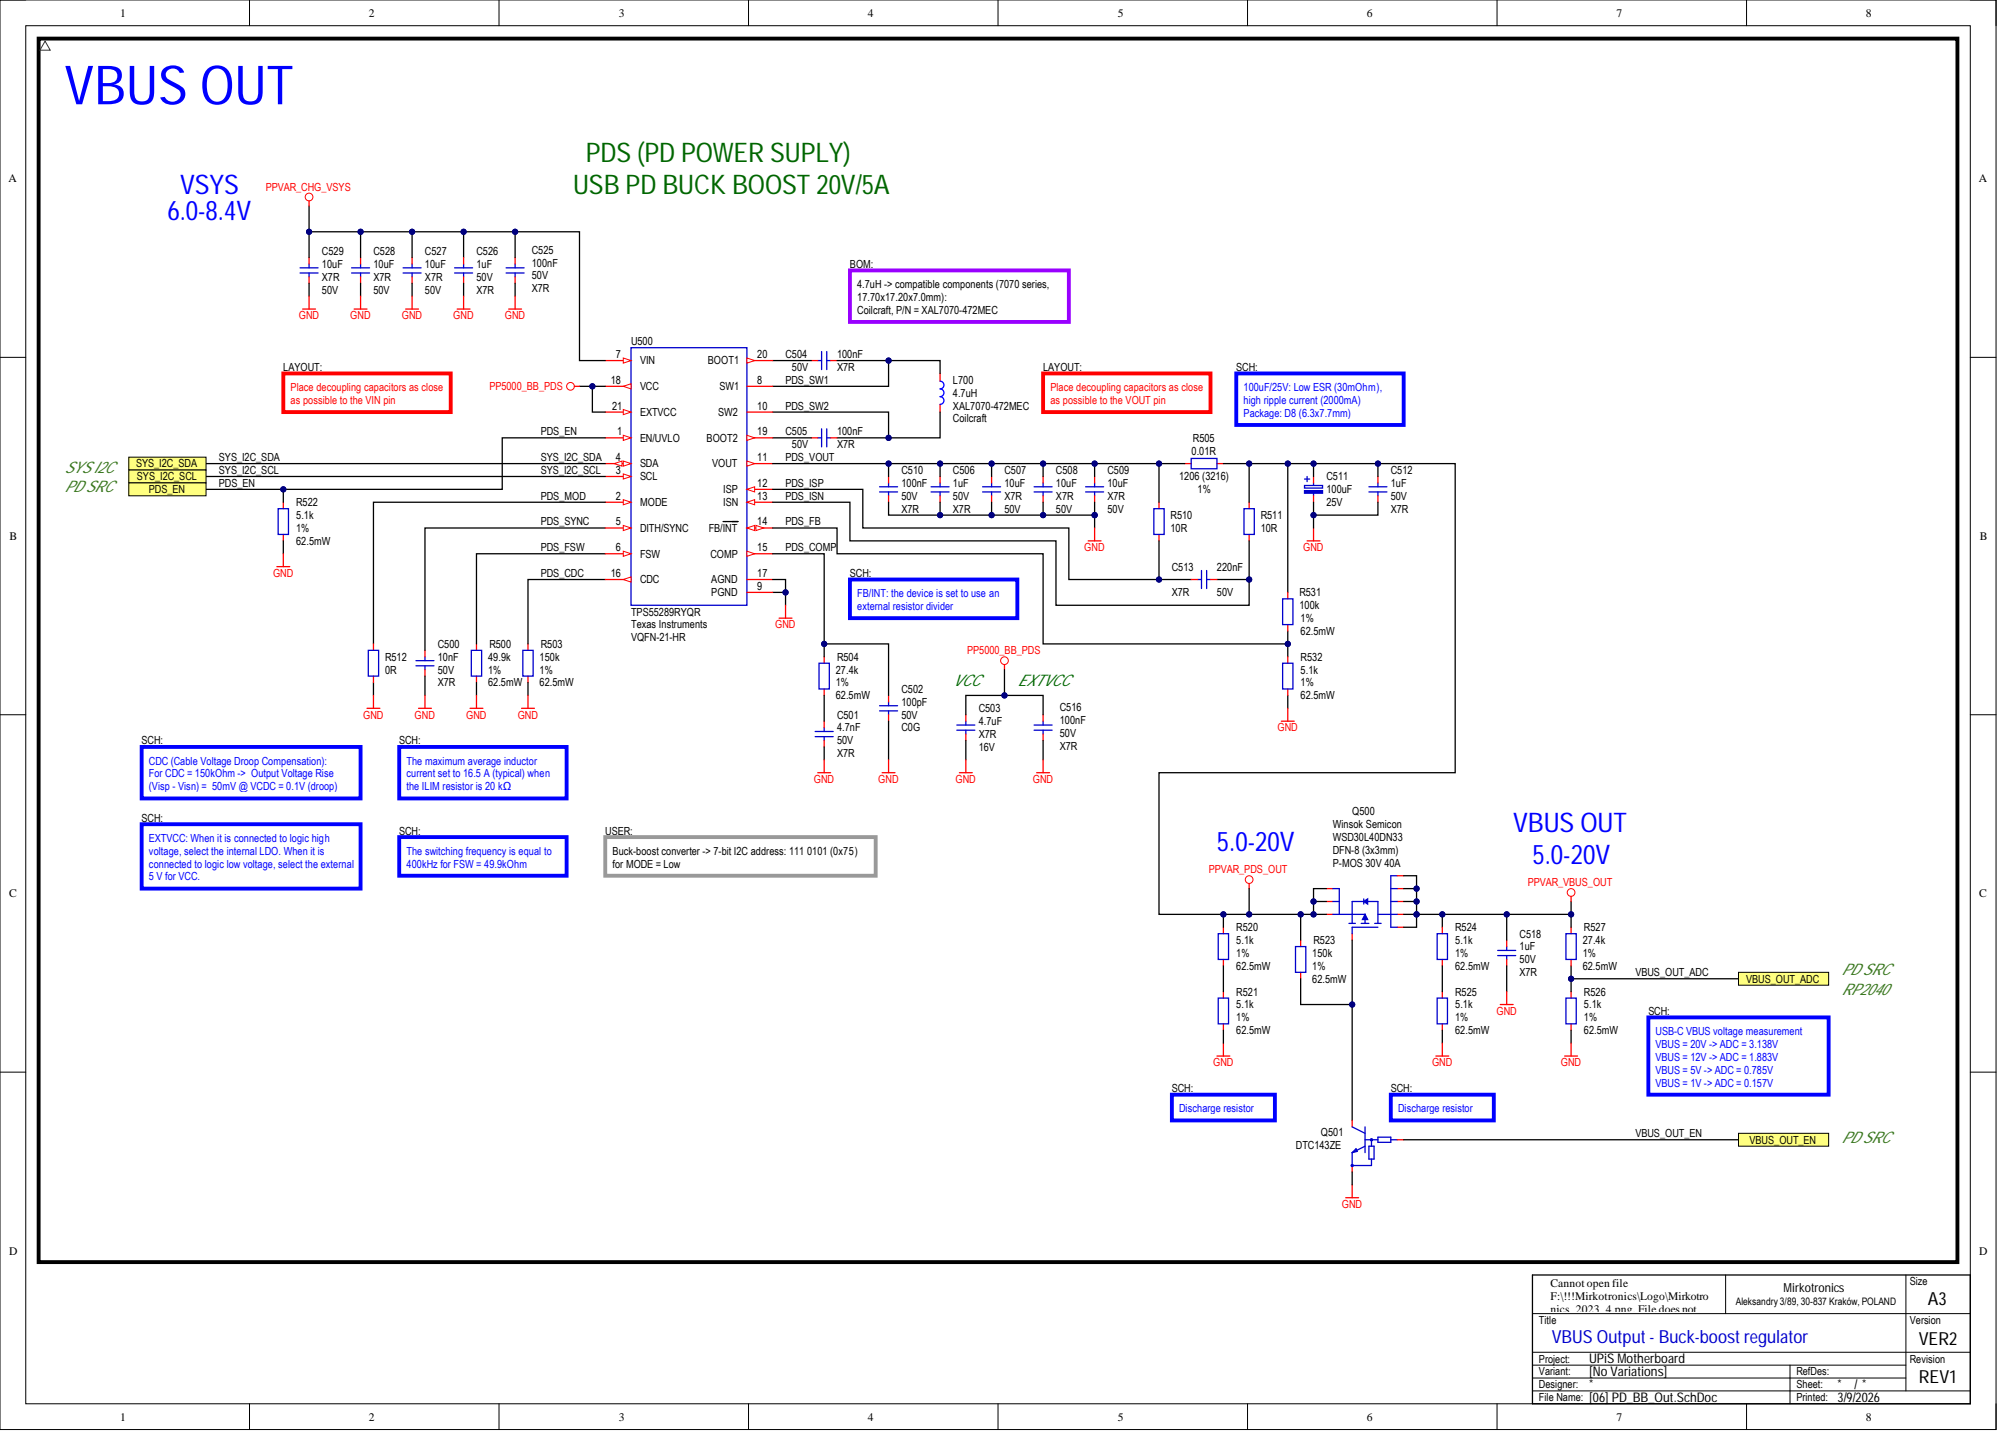
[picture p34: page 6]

PDS (PD POWER SUPLY)
USB PD BUCK BOOST 20V/5A

LAYOUT:
Place decoupling capacitors as close
as possible to the VIN pin

as possible to the VOUT pin

VCC 18 | PDS_SW1

EXTVCC 21

SCH:
FB/INT: the device is set to use an
external resistor divider

CDC (Cable Voltage Droop Compensation):
For CDC = 150kOhm -> Output Voltage Rise
(Visp - Visn) = 50mV @ VCDC = 0.1V (droop)

The maximum average inductor
current set to 16.5 A (typical) when
the ILIM resistor is 20 kΩ

EXTVCC: When it is connected to logic high
voltage, select the internal LDO. When it is
connected to logic low voltage, select the external
5 V for VCC.

The switching frequency is equal to
400kHz for FSW = 49.9kOhm

USER:
Buck-boost converter -> 7-bit I2C address: 111 0101 (0x75)
for MODE = Low

USB-C VBUS voltage measurement
VBUS = 20V -> ADC = 3.138V
VBUS = 12V -> ADC = 1.883V
VBUS = 5V -> ADC = 0.785V
VBUS = 1V -> ADC = 0.157V

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

VBUS Output - Buck-boost regulator | | VER2

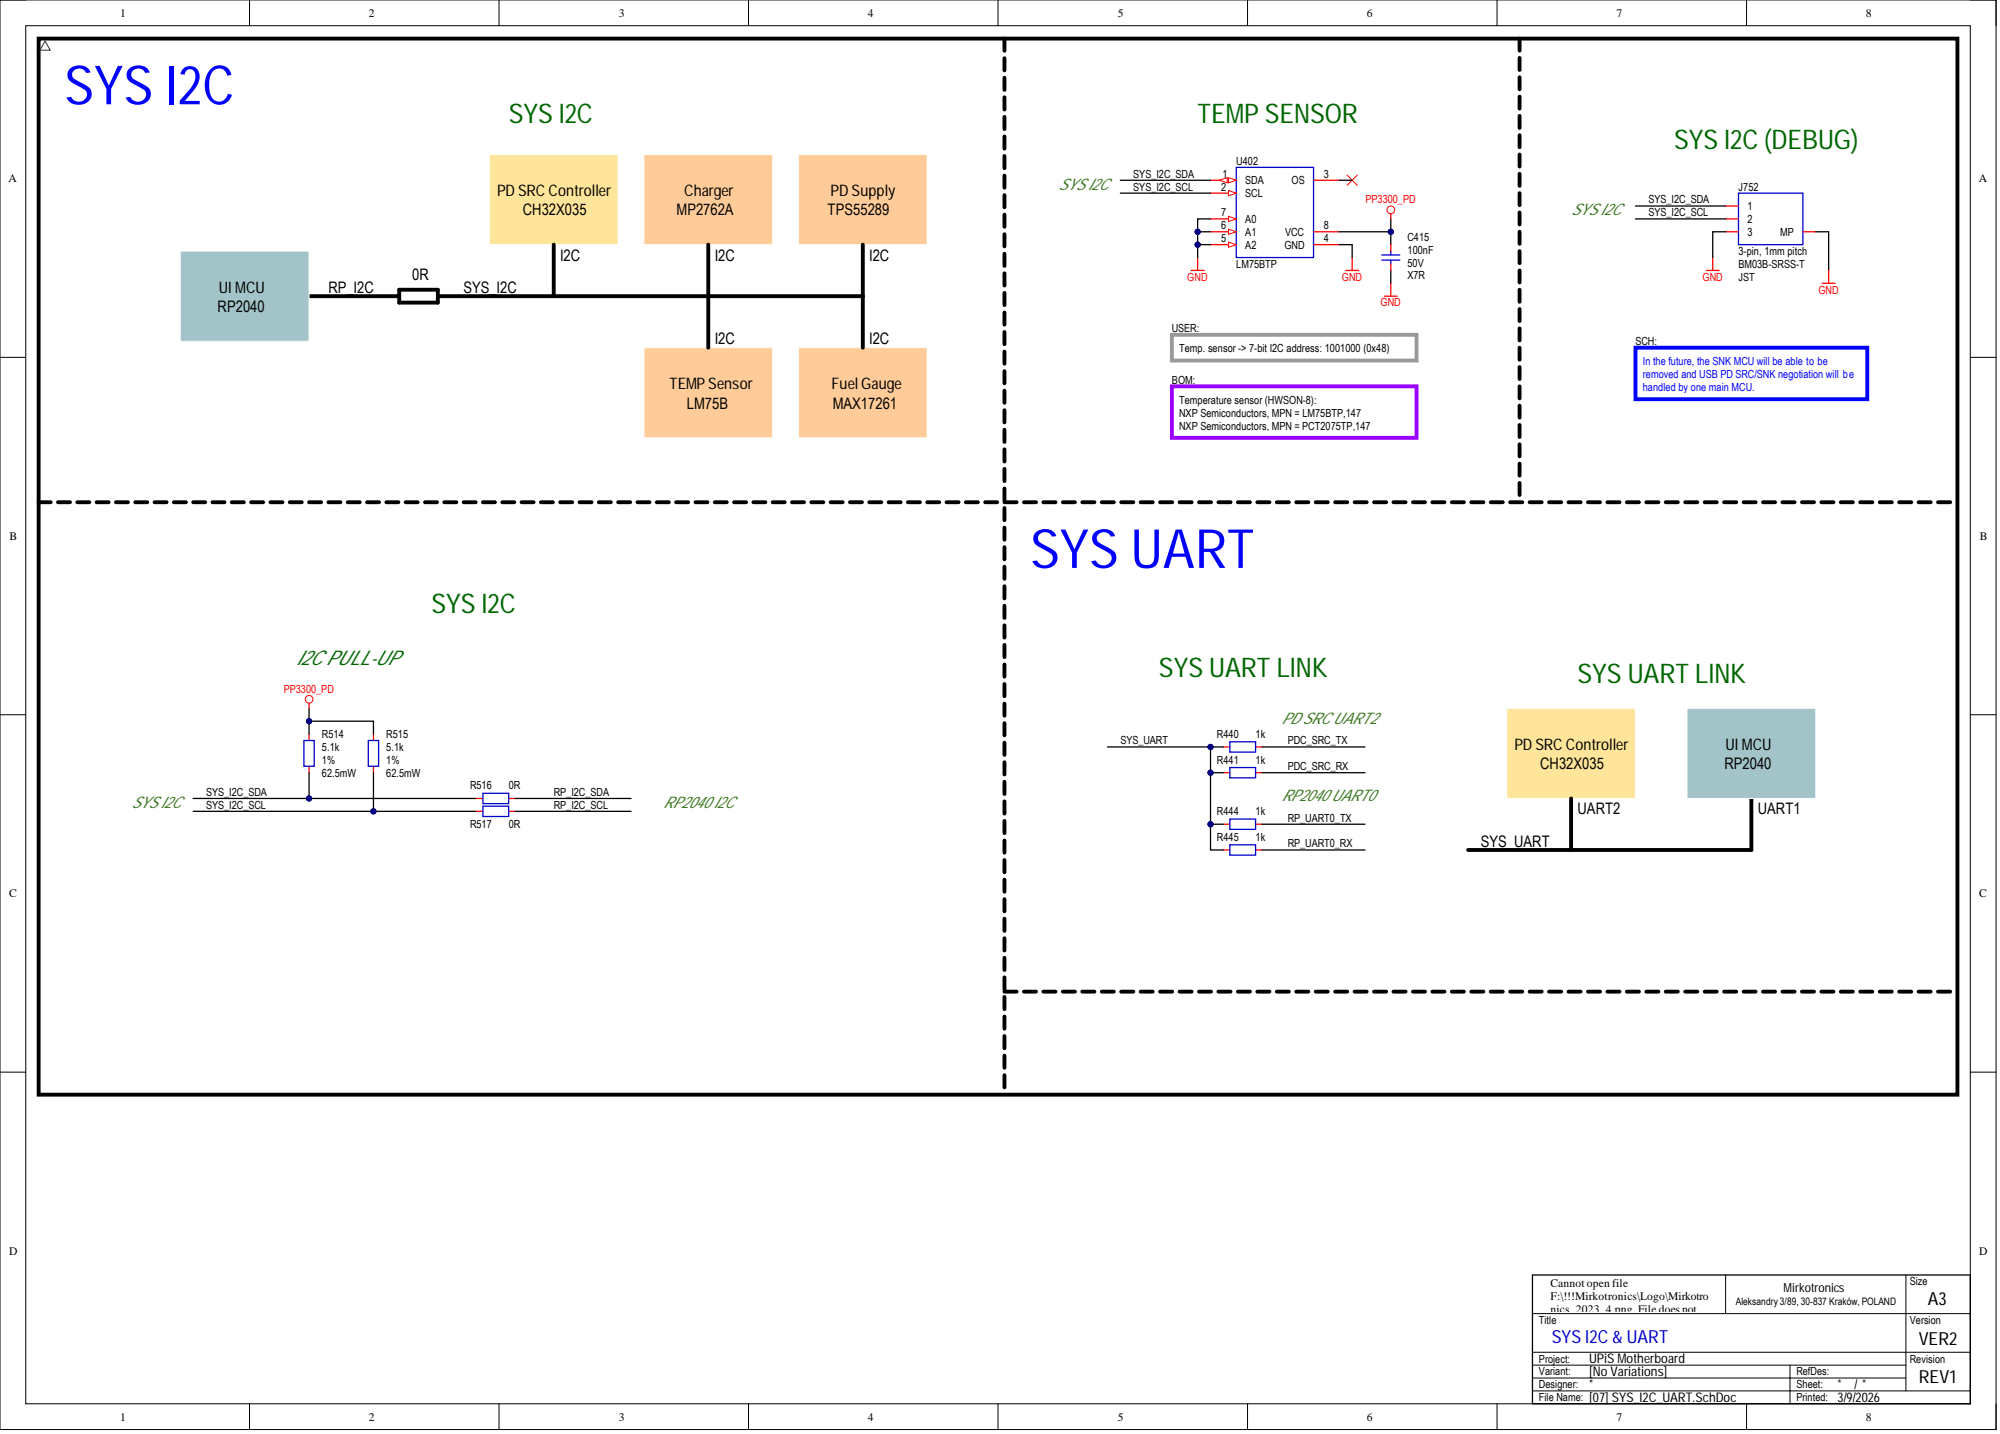
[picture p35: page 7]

USER:
Temp. sensor -> 7-bit I2C address: 1001000 (0x48)
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

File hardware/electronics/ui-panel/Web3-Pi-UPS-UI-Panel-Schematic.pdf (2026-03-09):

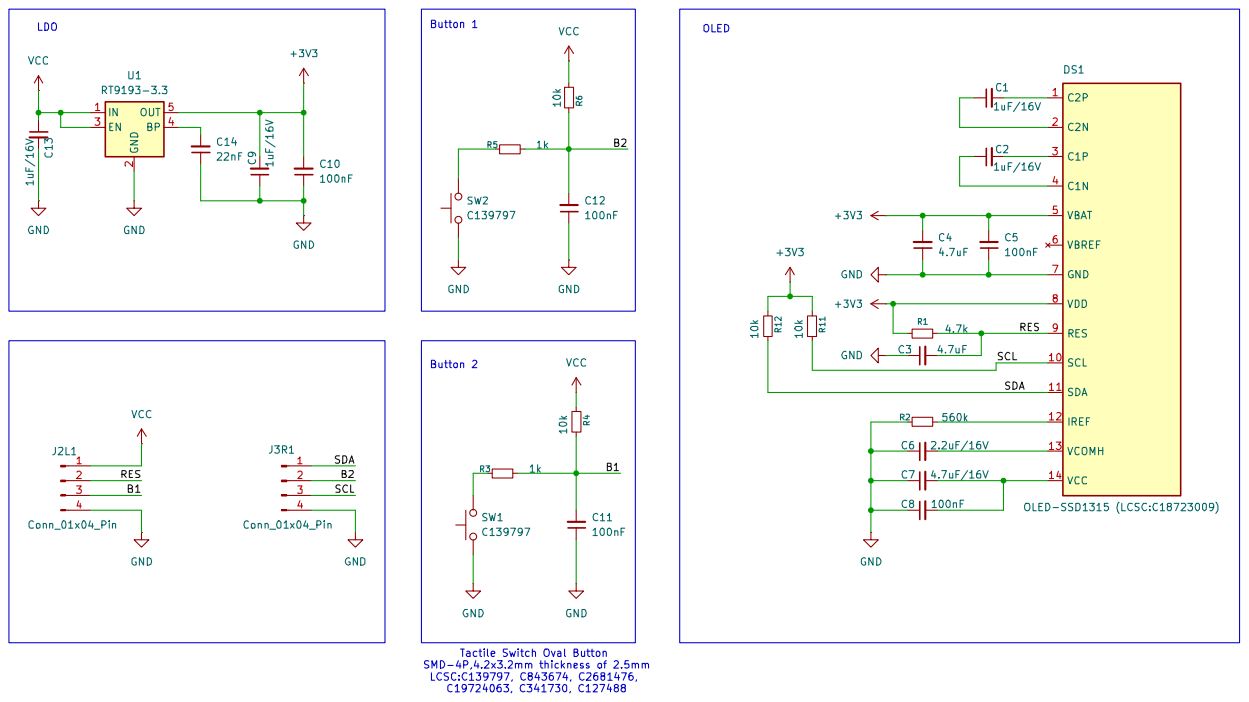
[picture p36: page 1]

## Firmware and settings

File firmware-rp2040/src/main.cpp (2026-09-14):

#include <Arduino.h>
#include <Wire.h>
#include <Adafruit_GFX.h>
#include <Adafruit_SSD1306.h>
#include <SerialPIO.h>
#include <string.h>
#include "wups_proto.h"
#include "wups_router.h"
#include "trust_ui.h"
#include "ui_settings.h"
#include "local_menu.h"
#include "fw_update.h"

// --- I2C for OLED ---
constexpr uint8_t I2C0_SDA_PIN = 8;
constexpr uint8_t I2C0_SCL_PIN = 9;
TwoWire WireCustom(i2c0, I2C0_SDA_PIN, I2C0_SCL_PIN);

// --- Debug serial via PIO software UART (J350 -> Raspberry Pi Debug Probe UART) ---
// Both hardware UARTs are claimed (UART0 = CH32X on GPIO16/17, UART1 reserved
// for the M.2 ESP32). J350 uses GPIO0 (TX) / GPIO1 (RX) — same data the host
// service sees on USB-CDC, mirrored here so we can monitor with the Probe
// while the Pi 5 holds the USB-CDC port.
constexpr uint8_t DBG_TX_PIN = 0;
constexpr uint8_t DBG_RX_PIN = 1;
constexpr uint32_t DBG_BAUD = 921600;  // match CH32X UART baud — no need to remember different speeds
SerialPIO dbgSerial(DBG_TX_PIN, DBG_RX_PIN, 32);

// Software ring buffer in front of dbgSerial. Earlephilhower's SerialPIO has
// only an 8-byte hardware TX FIFO and its write() calls pio_sm_put_blocking,
// so writing a ~250-byte burst (e.g. a debug log line) straight to it would
// stall loop() for ~22 ms (or forever if the PIO TX SM stops draining).
// DbgRing absorbs bursts in 1 KB of RAM, drops bytes silently when full, and
// is drained in loop() only as fast as the PIO HW FIFO has room — fully
// non-blocking.
class DbgRing : public Print {
public:
  static constexpr size_t SIZE = 1024;
  size_t write(uint8_t c) override {
    size_t next = (_head + 1) % SIZE;
    if (next == _tail) return 0;  // full, drop
    _buf[_head] = c;
    _head = next;
    return 1;
  }
  size_t write(const uint8_t* buf, size_t n) override {
    size_t written = 0;
    for (size_t i = 0; i < n; i++) {
      if (write(buf[i]) == 0) break;
      written++;
    }
    return written;
  }
  // Pump drains the ring. SerialPIO::write blocks max ~11 us per byte at
  // 921600, so worst-case pump time = SIZE * 11 us = 11 ms (full ring) —
  // well within the 50 ms loop budget. Bound by ring capacity to be safe.
  void pump(Stream& dst) {
    size_t budget = SIZE;
    while (_head != _tail && budget--) {
      dst.write(_buf[_tail]);
      _tail = (_tail + 1) % SIZE;
    }
  }
private:
  uint8_t _buf[SIZE];
  size_t _head = 0;
  size_t _tail = 0;
};
DbgRing dbgRing;

// Drops writes when the USB-CDC host has no port open. Earlephilhower's
// SerialUSB::write blocks ~50 ms per byte waiting for buffer space when
// DTR is deasserted — without this guard a ~290-byte debug burst freezes
// the loop for ~14 s, and nothing reaches the probe UART either.
class UsbCdcDropIfDetached : public Print {
public:
  size_t write(uint8_t c) override {
    if (Serial) Serial.write(c);
    return 1;
  }
  size_t write(const uint8_t* buf, size_t n) override {
    if (Serial) Serial.write(buf, n);
    return n;
  }
};
UsbCdcDropIfDetached usbCdcOut;

// Print fan-out to USB-CDC (best-effort, dropped when no host) and dbgRing.
class TeePrint : public Print {
public:
  TeePrint(Print& a, Print& b) : _a(a), _b(b) {}
  size_t write(uint8_t c) override {
    _a.write(c);
    _b.write(c);
    return 1;
  }
  size_t write(const uint8_t* buf, size_t n) override {
    _a.write(buf, n);
    _b.write(buf, n);
    return n;
  }
private:
  Print& _a;
  Print& _b;
};
TeePrint dbgOut(usbCdcOut, dbgRing);

// --- UART0 bidirectional (RP2040 <-> CH32X) ---
constexpr uint8_t GPIO16_PIN = 16;   // GPIO16 - UART0 TX (commands to CH32X)
constexpr uint8_t GPIO18_PIN = 18;   // GPIO18 - not used, set as input pullup
constexpr uint8_t GPIO19_PIN = 19;   // GPIO19 - not used, set as input pullup
constexpr uint8_t UART0_RX_PIN = 17; // GPIO17 - UART0 RX (status + responses from CH32X)

// --- UART1 (Serial2) — RP2040 <-> M.2 ESP32, hardware UART with full flow control ---
// All four pins are wired through the M.2 connector. CTS/RTS are wired up
// from day one so we never lose bytes when either side momentarily can't
// drain its FIFO; the deframer is robust against drops, but flow control
// keeps the link "boring" and saves debugging time later.
constexpr uint8_t  UART1_TX_PIN  = 20;  // GPIO20 - hardware UART1 TX
constexpr uint8_t  UART1_RX_PIN  = 21;  // GPIO21 - hardware UART1 RX
constexpr uint8_t  UART1_CTS_PIN = 22;  // GPIO22 - hardware UART1 CTS (input from ESP32 RTS)
constexpr uint8_t  UART1_RTS_PIN = 23;  // GPIO23 - hardware UART1 RTS (output to ESP32 CTS)
constexpr uint32_t UART1_BAUD    = 921600;

// --- GPIO26/27 - unused, set as output LOW ---
constexpr uint8_t GPIO26_PIN = 26;
constexpr uint8_t GPIO27_PIN = 27;

// --- ADC pins ---
constexpr uint8_t ADC_BATT_VOLT_PIN = A2; // ADC2 / GPIO28 - Battery voltage via divider
constexpr uint8_t ADC_VBUS_OUT_PIN = A3;  // ADC3 / GPIO29 - VBUS output voltage via divider

// --- Battery voltage divider resistors (kOhm) ---
// Divider connected to 2S battery pack (0-8.5V range)
// VADC = Vbat * R2 / (R1 + R2)
// R430=100k, R431=47k, C430=100nF filter, R432=0R to ADC
constexpr float BATT_R1_KOHM = 100.0f;  // R430 - Top resistor (to VBAT+)
constexpr float BATT_R2_KOHM = 47.0f;   // R431 - Bottom resistor (to GND)
constexpr float BATT_DIVIDER_RATIO = BATT_R2_KOHM / (BATT_R1_KOHM + BATT_R2_KOHM);

// --- VBUS output voltage divider resistors (kOhm) ---
// Divider connected to USB-C VBUS output (0-20V range)
// R527=27.4k, R526=5.1k
constexpr float VBUS_R1_KOHM = 27.4f;   // R527 - Top resistor (to VBUS_OUT)
constexpr float VBUS_R2_KOHM = 5.1f;    // R526 - Bottom resistor (to GND)
constexpr float VBUS_DIVIDER_RATIO = VBUS_R2_KOHM / (VBUS_R1_KOHM + VBUS_R2_KOHM);

// --- ADC calibration ---
constexpr float VREF = 3.3f;
constexpr int ADC_BITS = 12;
constexpr int ADC_MAX = (1 << ADC_BITS) - 1; // 4095

// ADC correction factor - set to 1.0 (no correction needed)
// RP2040 ADC reads within ~2% of actual voltage with this divider
constexpr float ADC_CORRECTION = 1.0f;

// --- OLED SSD1306 ---
constexpr int SCREEN_WIDTH  = 64;
constexpr int SCREEN_HEIGHT = 32;
constexpr int OLED_RESET    = -1;
constexpr uint8_t OLED_ADDR = 0x3C;
Adafruit_SSD1306 oled(SCREEN_WIDTH, SCREEN_HEIGHT, &WireCustom, OLED_RESET);

// --- Power hold ---
constexpr uint8_t RP_HOLD_VDD_PIN = 6;
constexpr uint8_t RP_UI_GPIO_PIN = 12;

// --- Buzzer ---
constexpr uint8_t BUZZER_PIN = 15;
constexpr unsigned long BAD_PSU_REMINDER_INTERVAL_MS = 10000; // Reminder beep every 10s
constexpr unsigned long LOW_BATTERY_INTERVAL_MS = 30000;      // <20% beep every 30s
constexpr unsigned long CRITICAL_BATTERY_INTERVAL_MS = 5000;  // <10% beep every 5s

// --- Buttons ---
constexpr uint8_t BTN_LEFT_PIN = 13;   // GPIO13 - left button (active LOW)
constexpr uint8_t BTN_RIGHT_PIN = 14;  // GPIO14 - right button (active LOW)
constexpr unsigned long DEBOUNCE_MS = 50;

// --- Screen navigation ---
// Screen strip (power.status v2 debug screens). Home (0) is the dashboard;
// 1..4 are the developer readouts split along the v2 struct sections.
constexpr uint8_t SCREEN_HOME    = 0;
constexpr uint8_t SCREEN_INPUT   = 1;   // VIN / input PD contract / source
constexpr uint8_t SCREEN_OUTPUT  = 2;   // Vout RP2040 vs CH32X / output PD / Ilim
constexpr uint8_t SCREEN_BATTERY = 3;   // Vbat RP2040 vs CH32X / mode / charge current
constexpr uint8_t SCREEN_SYSTEM  = 4;   // uptime / temps / fault bitmap
constexpr uint8_t SCREEN_COUNT   = 5;
constexpr unsigned long AUTO_RETURN_MS = 20000;  // Auto-return to home after 20s

// --- Bad charger alert state ---
bool badChargerAlertPlayed = false;
unsigned long lastReminderTime = 0;

// --- Battery power loss detection ---
bool previousPowerGood = false;     // Initialized after startup stabilization
bool powerLossAlertPlayed = false;  // Prevent repeated alerts

// --- ESP32-driven modem/network alert -------------------------------------
// The ESP32 modem supervisor sends ui.display_msg when cellular bring-up
// stays broken across power-cycles (e.g. marginal SIM contact / weak
// antenna). We render it as an OLED override (like BAD PSU) with a 10 s
// reminder beep, so a silent-in-panel unit is visible + audible on the bench.
// Cleared by an empty-text ui.display_msg (modem recovered) or by an ESP32
// reboot (system.hello) — the ESP32 re-raises it if still degraded.
// Two local escape hatches (the clear frame is a single unACKed msg on a
// no-flow-control UART, so it CAN be lost — field case: banner latched
// forever after the modem had recovered):
//   - any button press dismisses the banner; the SAME text re-raised by the
//     ESP32 then stays hidden for ALERT_DISMISS_COOLDOWN_MS, a DIFFERENT
//     text (new problem) shows immediately and drops the dismissal;
//   - a banner not re-asserted for ALERT_STALE_TTL_MS auto-clears (the
//     ESP32 re-sends an active alert every failing round, worst case
//     ~3 min apart, so 5 min of silence means the alert is gone).
char netAlertText[24] = {0};
bool netAlertActive = false;
bool netAlertBeeped = false;              // rising-edge error-sound guard
unsigned long netAlertLastReminder = 0;
bool netAlertOnScreen = false;            // banner actually rendered last pass
unsigned long netAlertLastAssertMs = 0;   // last non-empty display_msg (TTL basis)
constexpr unsigned long ALERT_DISMISS_COOLDOWN_MS = 10UL * 60UL * 1000UL;
constexpr unsigned long ALERT_STALE_TTL_MS        = 5UL * 60UL * 1000UL;
char netAlertDismissedText[24] = {0};     // [0]=='\0' → no dismissal in effect
unsigned long netAlertDismissedAtMs = 0;
// The ESP32 OTA (fw_ota.c ota_ui_banner) raises "FW UPDATE" through the same
// layer. It is progress, not a failure: rendered without the "no uplink" line,
// and silent while FW_UPDATE_BANNER_BEEP is 0 (set to 1 to restore the
// error-sound + 10 s reminder pattern once the firmware is final).
constexpr const char *FW_UPDATE_BANNER_TEXT = "FW UPDATE";
#define FW_UPDATE_BANNER_BEEP 0

// --- Info notice (ui.display_msg from a non-ESP32 sender) ------------------
// ui.display_msg is dispatched on the frame's SRC. Only the ESP32 (modem
// supervisor / OTA) may raise the MODEM alarm banner above. Any other source
// — the RPi host service over USB-CDC, the HTTP backend's operator 'msg' or
// the panel's MQTT downlink (both arrive with src = WUPS_ADDR_RPI because the
// net.downlink unwrap keeps the INNER frame's src) — renders as a plain INFO
// NOTICE: no "MODEM" / "no uplink" framing, no error sound (one short click
// chirp the first time it is actually drawn — not while hidden behind a
// higher-priority screen, and not for a same-text keepalive re-send),
// INFO_TTL_MS auto-expiry, any button press closes it.
// Before rp2040:1.2.2 every non-empty display_msg went into the modem-alarm
// path, so an operator 'msg' from the HTTP server showed up as a MODEM
// failure with the full buzzer pattern. The two layers are independent: an
// empty text clears only the sender's own layer (an HTTP operator cannot
// clear the modem banner, the ESP32 cannot clear an info notice). While the
// modem banner is up the notice stays stored but hidden; its TTL keeps running.
char infoText[41] = {0};                  // 40 visible chars = 4 rows x 10 cols
unsigned long infoUntilMs = 0;            // absolute millis() deadline (wrap-safe compare)
bool infoOnScreen = false;                // notice actually rendered last pass
bool infoChirpPending = false;            // new text stored, chirp not yet played
constexpr unsigned long INFO_TTL_MS = 60UL * 1000UL;

// Firmware version, reported in system.ping RESP / system.hello. The string
// rides the optional pong tail (protocol.h); the u16 stays as the coarse
// legacy field. Bump on release.
#define FW_VERSION_STR "rp2040:1.2.4"
#define FW_VERSION_U16 ((uint16_t)((1u << 8) | 2u))   /* coarse 1.2 */

// UPS-data staleness alert. CH32X pushes power.status at 1 Hz; when that
// stream dies the cached ui.* values FREEZE and everything downstream
// (OLED, alarms, uplink-on-change) silently runs on dead data — exactly
// what masked the 2026-07-11 CH32X wedge for 8 h (frozen "4.6 V" looked
// live on the OLED and panel, and produced a false BAD PSU). Detected
// here and surfaced as the HIGHEST-priority OLED override (above BAD PSU,
// which is computed FROM the frozen data and is meaningless when stale),
// plus a one-shot system.log to the RPi agent (journald evidence).
static const uint32_t UPS_STALE_MS            = 5000;   // 5 missed 1 Hz frames
static const uint32_t UPS_STALE_BOOT_GRACE_MS = 8000;   // never-seen-a-frame case
static const uint32_t UPS_STALE_REMINDER_MS   = 30000;  // beep cadence while stale
bool upsStaleActive = false;
bool upsStaleBeeped = false;              // rising-edge error-sound guard
unsigned long upsStaleLastReminder = 0;

// Deaf-RX auto-recovery. Field-verified failure (2026-07-11, 2/3 soak
// units): a garbage burst on UART0 during a mains transient (CH32X AWD-ISR
// printf ASCII shredding the frame stream — fixed at the source in
// firmware-ch32x) can wedge the Arduino-core Serial1 RX path: the UART IRQ
// keeps draining the HW FIFO (FR shows RXFE=1, no overruns) but
// available() returns 0 forever — ring state desync. loop() stays healthy,
// so the watchdog can't catch it; a Serial1 re-init clears it (verified:
// an RP2040 reset restored live telemetry with CH32X untouched). After
// UPS_RX_REINIT_AFTER_MS of staleness, re-init Serial1 and retry every
// UPS_RX_REINIT_RETRY_MS while the stream stays dead.
static const uint32_t UPS_RX_REINIT_AFTER_MS = 10000;
static const uint32_t UPS_RX_REINIT_RETRY_MS = 30000;

// BAD PSU debounce: display passes (~50 ms each) of continuous violation
// before the alert engages — ~3 s. See the badCharger comment in the
// display path.
static const uint8_t BAD_PSU_DEBOUNCE_PASSES = 60;
static uint8_t badChargerDebounce = 0;
unsigned long upsStaleSinceMs = 0;
unsigned long upsRxReinitLastMs = 0;
uint16_t upsRxReinitCount = 0;

static void reinitCh32xUart() {
  // Mirror the exact setup() sequence (pins, FIFO, baud). Same Serial1
  // object — the router's cached Stream* stays valid.
  Serial1.end();
  Serial1.setRX(UART0_RX_PIN);
  Serial1.setTX(GPIO16_PIN);
  Serial1.setFIFOSize(1024);
  Serial1.begin(921600);
}

// --- Low battery warning state ---
unsigned long lastLowBatteryBeep = 0;

unsigned long lastFrameTime = 0;  // millis() of the last power.status frame received

// --- Screen navigation state ---
uint8_t currentScreen = 0;
unsigned long lastInteractionTime = 0;
bool lastBtnLeftState = HIGH;
bool lastBtnRightState = HIGH;
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
void loop() {
  // Watchdog kick — first thing every iteration; if loop() ever stops
  // making rounds for >8 s the hardware resets us (see setup()).
  rp2040.wdt_reset();

  // Drain commands from the host service (USB-CDC) and the Probe UART (J350)
  // and forward both to CH32X. Each source has its own framing state.
  // Drain USB-CDC, UART0 (CH32X) and UART1 (ESP32) into per-port deframers,
  // route forwarded frames, and dispatch local frames to wups_on_local_frame().
  wups_router_drain();

  // Shovel as much of the debug ring buffer as the SerialPIO HW FIFO can
  // accept, then return. Non-blocking, runs every loop iteration (~50 ms).
  dbgRing.pump(dbgSerial);

  // OTA-2 timeouts: 30 s fw_xfer session idle discard + the ~5 min
  // pending-verify rollback (may reboot). Runs before every early-return
  // branch below so it ticks even while a menu owns the display.
  fw_update_tick();

  // OTA-2 — while a fw_xfer session is open the FW UPDATE screen owns the
  // OLED outright: placed ABOVE trust_ui / local menu / all alert banners
  // so nothing can preempt it, and buttons are simply not read (nav and
  // menu gestures suppressed). Frames keep flowing via wups_router_drain()
  // above; the short delay paces the stop-and-wait transfer faster than
  // the dashboard's 50 ms cadence (the sender waits for each RESP).
  if (fw_update_session_active()) {
    fw_update_render(oled);
    delay(5);
    return;
  }

  // Track 2 / ADR-0011 §10.1/§10.4 — the Paranoic owner-binding gate is a
  // security override: while a ui.trust_prompt is active the trust UI owns
  // the OLED and both buttons, and the normal dashboard / navigation is
  // fully suppressed. Buttons are active-LOW with pullups (LOW = pressed).
  if (trust_ui_active()) {
    // The ESP32 answered the "Network" hand-off — clear the No-modem deadline
    // HERE. This branch returns before the deadline check further down ever
    // runs, so if we don't clear it now the stale deadline fires the instant
    // the menu closes (spurious "No modem" + a second beep + the local menu
    // reopening instead of going Home, on every menu exit).
    menu_pending_deadline_ms = 0;
    s_btn_release_guard = true;   // swallow the lingering press on exit
    trust_ui_tick(oled,
                  digitalRead(BTN_LEFT_PIN)  == LOW,
                  digitalRead(BTN_RIGHT_PIN) == LOW);
    delay(50);
    return;
  }

  // ADR-0012 (revised) — the RP2040-LOCAL universal menu owns the OLED +
  // buttons while open, exactly like trust_ui above. Built from local state,
  // so it works with or without the M.2 module. Only opens while trust_ui is
  // inactive (checked above), so the two never fight over the display.
  if (local_menu_active()) {
    LocalMenuCtx ctx;
    ctx.uptime_s    = millis() / 1000UL;
    ctx.temp_lm_dC  = ui.temp_lm_dC;
    ctx.temp_mp_dC  = ui.temp_mp_dC;
    ctx.power_fresh = (Last_Power_Status_Ms != 0) &&
                      ((uint32_t)(millis() - Last_Power_Status_Ms) < 3000u);
    // Read the output rail live so the Output screen reflects a just-issued
    // enable/disable (the main ADC read below is skipped while we early-return).
    {
      float lsb_mV = (VREF * 1000.0f) / ADC_MAX;
      ctx.vbus_out_mV =
          (int)(analogRead(ADC_VBUS_OUT_PIN) * lsb_mV / VBUS_DIVIDER_RATIO + 0.5f);
    }
    s_btn_release_guard = true;   // swallow the lingering press on exit
    local_menu_tick(oled,
                    digitalRead(BTN_LEFT_PIN)  == LOW,
                    digitalRead(BTN_RIGHT_PIN) == LOW,
                    ctx);
    delay(50);
    return;
  }

  // A button still held from a just-closed menu (the press that selected
  // "Back"/exit) would otherwise be read by the dashboard nav as a fresh
  // press — phantom screen change + a second beep. Swallow until both release;
  // by the time nav runs the button reads HIGH, so no phantom edge fires.
  if (s_btn_release_guard) {
    if (digitalRead(BTN_LEFT_PIN) == LOW || digitalRead(BTN_RIGHT_PIN) == LOW) {
      delay(50);
      return;
    }
    s_btn_release_guard = false;
  }

  // Modem-alert banner dismiss: while the netAlert override is on the OLED,
  // ANY button press acknowledges it — drop the banner and fall back to
  // whatever screen the dashboard was on. Edge-triggered on the press
  // (HIGH→LOW seen while the banner is up): a button already held when the
  // banner appears — e.g. mid LEFT-hold menu gesture — is ignored, so an
  // in-flight press can neither silently dismiss an alert the user never
  // read nor double-act (its release still navigates exactly as before).
  // The prev-level trackers sample every pass, banner or not, so a held
  // LOW level is never mistaken for a fresh press. A consumed press is
  // swallowed via the same release guard used on menu exit (this block runs
  // before the hold-gesture and nav blocks, and the early return keeps them
  // from ever seeing the press), so it can't double as a nav tap or arm the
  // LEFT-hold menu gesture. Silent: no beep on dismiss, and the reminder
  // cadence stops with the banner. The dismissed text is remembered so the
  // ESP32 re-raising the SAME alert doesn't instantly bring the banner back
  // (see the ui.display_msg handler).
  {
    static bool s_dismiss_left_prev  = false;
    static bool s_dismiss_right_prev = false;
    bool left_down  = digitalRead(BTN_LEFT_PIN)  == LOW;
    bool right_down = digitalRead(BTN_RIGHT_PIN) == LOW;
    bool press_edge = (left_down && !s_dismiss_left_prev) ||
                      (right_down && !s_dismiss_right_prev);
    s_dismiss_left_prev  = left_down;
    s_dismiss_right_prev = right_down;
    if (netAlertOnScreen && netAlertActive && press_edge) {
      memcpy(netAlertDismissedText, netAlertText, sizeof(netAlertDismissedText));
      netAlertDismissedAtMs = millis();
      netAlertActive = false;
      netAlertText[0] = '\0';
      netAlertOnScreen = false;
      s_btn_release_guard = true;   // swallow this press until both release
      delay(50);
      return;
    }
    // Info notice (non-ESP32 display_msg) on the OLED: any press closes it
    // and is consumed the same way. Separate layer — does not touch the
    // modem-banner dismissal record or its cooldown.
    if (infoOnScreen && infoText[0] != '\0' && press_edge) {
      infoText[0] = '\0';
      infoUntilMs = 0;
      infoChirpPending = false;
      infoOnScreen = false;
      s_btn_release_guard = true;   // swallow this press until both release
      delay(50);
      return;
    }
  }

  // We're back on the dashboard with no hand-off pending: the ESP32 menu (if
  // any) closed by timeout, not its "Back". Drop the back-to-local intent so a
  // later unrelated set_screen(0) isn't misread as a menu back-out.
  if (menu_pending_deadline_ms == 0) s_esp32_menu_from_local = false;
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

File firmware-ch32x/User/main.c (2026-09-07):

/********************************** (C) COPYRIGHT *******************************
 * File Name          : main.c
 * Project            : Web3 Pi UPS v2 — CH32X035 PD SRC controller firmware
 * Author             : Robert Mordzon (Web3 Pi)
 * Based on           : WCH "PD SRC Sample code" V1.0.1 (2025/03/11)
 * Description        : Main program body — dual-role USB-PD, TPS55289 VBUS
 *                      control, MP2762A charger telemetry, LM75B temperature,
 *                      and Web3 Pi UPS binary wire protocol v1 over USART2.
 *********************************************************************************
 * Copyright (c) 2026 Robert Mordzon / Web3 Pi
 * Portions Copyright (c) 2021 Nanjing Qinheng Microelectronics Co., Ltd.
 *
 * Attention: This software (modified or not) and binary are used for
 * microcontroller manufactured by Nanjing Qinheng Microelectronics.
 *******************************************************************************/

/*
 *@Note
 *
 * PD SRC Sample code
 *
 * This sample code may have compatibility issues and is for learning purposes only.
 *
 * Be sure to remove the pull-down resistors on both CC wires when using this Sample code!
 *
 * The inability to control the VBUS voltage on the board may lead to some compatibility problems,
 * mainly manifested in the inability of some devices to complete the PD communication process.
 *
 */

#include <string.h>
#include <stdlib.h>

#include "debug.h"
#include "PD_Process.h"
#include "i2c_lib.h"
#include "tps55289.h"
#include "lm75b.h"
#include "mp2762a.h"
#include "husb238.h"
#include "wups_proto.h"

/* ADC WWDG Mode Definition*/
#define NoSCAN_MODE_WDT   0
#define SCAN_MODE_WDT     1

/* ADC WWDG Mode Selection*/
#define ADC_MODE_WDT   NoSCAN_MODE_WDT

/* WWDG Reset Enable Definition */
#define WDT_RST_ENABLE   0
#define WDT_RST_DISABLE  1

/* WWDG Reset Enable Selection */
#define WDT_RST   WDT_RST_DISABLE

/* Diagnostic mode: skip USB-PD negotiation entirely. From boot, force
 * TPS55289 to 5.1 V / 5 A and hold VBUS_OUT_EN high. PD_Init() still
 * runs so the CC-line Rp pull-ups exist (a sink will detect us as a
 * non-PD 5 V source and pull as much current as its e-load asks for —
 * up to 5 A from the TPS limit). Uncomment the define to bypass PD
 * negotiation again. */
/* #define DIAG_FORCE_5V_5A_NO_PD */

void TIM1_UP_IRQHandler(void) __attribute__((interrupt("WCH-Interrupt-fast")));
/* CRITICAL: every IRQ handler MUST carry the WCH interrupt attribute. The
 * 2026-07-11 soak failure (2/3 units, main loop dead after a mains dip) was
 * this handler compiled as a plain function: it returned with `ret` instead
 * of `mret`, destroying the interrupted thread context. See also the AWD
 * removal in ADC_Function_Init(). */
void ADC1_IRQHandler(void) __attribute__((interrupt("WCH-Interrupt-fast")));
void ADC_Function_Init(void);
u16 Get_ADC_Val(u8 ch);
void USART2_Init(uint32_t baudrate);
void USART2_SendString(const char *s);
static void Usart2_Dma_Rx_Init(void);
static void wups_send_power_status(uint8_t dst, uint8_t flags, uint8_t seq);
static void wups_send_hello_bcast(void);
/* Both wake handlers are DEFINED unconditionally below, so both MUST carry
 * the interrupt attribute unconditionally — a handler compiled as a plain
 * function returns with `ret` instead of `mret` and destroys the interrupted
 * context (the 2026-07-11 ADC1 failure class). Previously these were #if'd
 * on Wake_up_mode, leaving the inactive one attribute-less. */
void USBPDWakeUp_IRQHandler(void) __attribute__((interrupt("WCH-Interrupt-fast")));
void EXTI15_8_IRQHandler(void) __attribute__((interrupt("WCH-Interrupt-fast")));
volatile UINT8  Tim_Ms_Cnt = 0x00;
volatile UINT8  Led_Cnt = 0x00;
volatile UINT32 Uptime_Sec = 0;
static UINT16   Ms_Sub_Cnt = 0;
volatile u16    DC_Inp_ADC_Val = 0;
static UINT16   DC_Inp_Voltage_mV = 0;
volatile u16    Vbat_ADC_Val = 0;
static UINT16   Vbat_Voltage_mV = 0;
static UINT16   Vbus_Out_Voltage_mV = 0;   /* PA0 ADC, same 27.4k/5.1k divider as PA1 */
volatile u16    Vbus_Out_ADC_Val = 0;      /* PA0 raw counts, sampled in TIM1 ISR */
static volatile u16 Adc_RR_Cnt = 0;        /* TIM1 ISR round-robin tick (ISR-only) */
#define ADC_VAL_INVALID 0xFFFFu            /* Get_ADC_Val guard-expiry marker */
static UINT16   Json_Timer_Ms = 0;
static UINT16   Temp_Timer_Ms = 0;
static UINT16   Chg_Timer_Ms = 0;
static UINT16   Tps_Timer_Ms = 0;
static UINT16   Bat_Timer_Ms = 0;
static UINT16   Diag_Log_Timer_Ms = 0;
#define DIAG_LOG_INTERVAL_MS 5000
static int16_t  Board_Temp_c10 = 0;
static mp2762a_data_t Chg_Data = {0};
/* HUSB238 INPUT-side PD sink contract (rev.3). CH32X is a passive reader;
 * see User/husb238.h. Refreshed in the 2 s charger-poll block, surfaced in
 * the 5 s diagnostic system.log. NOT yet in the power.status wire struct —
 * v1 is full (20 B) and the strict RPi-host parser requires exact len +
 * version==1, so structured exposure is a coordinated protocol-v2 follow-up. */
static husb238_data_t Husb_Data = {0};
/* Auto input-PD negotiation (rev.3). The HUSB238 VSET/ISET straps pick the
 * highest source PDO meeting a fixed current floor, which on most chargers
 * yields a weak low-V contract (RPi 27W -> 5V/3.25A). Once per attach the
 * CH32X overrides via I2C (priority over the straps) and applies the
 * selection policy in husb238.h (satisfice >=45W at the most efficient
 * voltage; 9-20 V; <=5 A). */
static husb238_src_caps_t Husb_Caps = {0};
static uint8_t  Husb_Pd_Optimized = 0;   /* one-shot latch, re-armed on detach */
static uint8_t  Husb_Pick_Sel = 0;       /* HUSB238_SEL_* chosen for diag log */
static uint8_t  Diag_Toggle = 0;         /* alternates MP2762A / HUSBcaps diag lines */
static int16_t  Tps_Vread_v10 = 0;
static int16_t  Tps_Iread_a10 = 0;
/* TPS55289 STATUS register bits — accumulated across polls. SCP/OCP/OVP
 * latch in hardware until the register is read. We OR each poll's read
 * into Tps_Status_Latched so a brief trip is not lost between status
 * frames; the latch is cleared once a power.status frame ships out. */
static uint8_t  Tps_Status_Latched = 0;
#define JSON_INTERVAL_MS 1000
#define TEMP_INTERVAL_MS 5000
#define CHG_INTERVAL_MS  2000
#define TPS_INTERVAL_MS  2000
#define BAT_INTERVAL_MS  500

/*********************************************************************/
void VBUS_enable(void)
{
//VBUS_OUT_EN = 1
	GPIO_WriteBit(GPIOA, GPIO_Pin_7, 1);
//PDS_EN = 1
	GPIO_WriteBit(GPIOB, GPIO_Pin_0, 1);
//PDC_SRC_TX = 1
    //GPIO_WriteBit(GPIOA, GPIO_Pin_2, 1);
//LED
//	GPIO_WriteBit(GPIOB, GPIO_Pin_12, 1);
}
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

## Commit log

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2026-04-29 Add MQTT-over-TLS client to broker.w3p.ovh
    After PPP comes up, the firmware now SNTP-syncs the clock, runs the
    HTTP smoke test, then connects to broker.w3p.ovh:8883 with esp-mqtt:
    authenticates as TestUpsUser, subscribes to web3piups/<id>/cmd and
    web3piups/test, publishes a hello on the test topic and a retained
    {"online":true} on web3piups/<id>/status, with an LWT
    {"online":false} for ungraceful drops. Client ID is "ups-<MAC>" so
    sessions are stable across reboots.
    - main/mqtt.{c,h}: esp-mqtt client + event handler (CONNECTED,
    DATA, ERROR, ...). Stack bumped to 12 KB so the TLS handshake fits.
    - main/secrets.h{,.example}: broker URI / username / password.
    secrets.h is gitignored.
    - mai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
    [modem.c]
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2026-04-29 firmware: add PPP supervisor for auto-reconnect
    Replace the one-shot ppp_bringup_task with ppp_supervisor_task that
    watches IP_EVENT_PPP_LOST_IP / NETIF_PPP_ERRORUSER, tears down the DCE
    via esp_modem_destroy, and rebuilds it with exponential backoff
    (1s → 60s cap). After 5 consecutive bring-up failures, pulse PWRKEY
    to recover from a wedged radio. esp-mqtt stays started across PPP
    cycles and reconnects on its own once a route exists.
    [modem.c]
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2026-04-30 firmware-ch32x: bidirectional UART + JSON command dispatcher
    USART2 was TX-only (status JSON push to RP2040). This adds RX on
    PA3 with an interrupt-driven 128-byte ring buffer and a brace-
    balanced JSON frame parser, and implements ping / ups.status /
    ups.power.{disable,enable,cycle} / ups.reset. ups.power.cycle uses
    a non-blocking state machine (POWERCYCLE_OFF_MS = 1500 ms) so PD
    and charger processing keep running during the VBUS_OUT off window.
    Responses use {"resp":"<name>","id":<int>,"ok":<0|1>[,"err":"..."]}
    and travel on the same TX path as the periodic status JSON; the
    "resp" key tells the RP2040 to forward the frame to the host
    verbatim instead of augmenting it with bv/SOC/bd/vo.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
    [main.c]
2026-04-30 firmware-rp2040: SerialPIO debug, SWD upload, GPIO16 drive bump
    * main.cpp: add SerialPIO @ 921 600 on GPIO0/1 (J350 -> Pi Debug
    Probe UART). Both hardware UARTs are reserved (UART0 = CH32X,
    UART1 = M.2 ESP32), so debug serial uses a PIO state machine
    with a 1 KB DbgRing software buffer drained in loop(); writes
    are non-blocking so the Probe being unplugged never stalls main.
    TeePrint fans status frames and CH32X responses to USB-CDC and
    Probe simultaneously. Symmetric drainCmdStream() lets us inject
    commands from the Probe terminal as well as USB-CDC.
    * main.cpp: bump GPIO16 (UART0 TX to CH32X) PADS drive to 12 mA
    with slewfast for cleaner edges through the patched-in SYS_UA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
    [main.cpp]
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2026-04-30 ups.power.enable: force PD renegotiation; clear cached fields on disable
    The previous handler called VBUS_set_5V() but left the PD FSM at STA_IDLE,
    so a sink that had already negotiated >5V (e.g. a 15V load) just saw 5.1V
    come back without ever receiving a new SRC_CAP. The CC-line detector only
    fires on a physical hot-plug, so the cable being still attached meant the
    FSM never re-armed itself.
    Add Power_Output_Restart() which pushes the FSM straight into
    STA_SINK_CONNECT with timers reset. After 159 ms it sends a fresh SRC_CAP
    and the sink renegotiates cleanly. The STA_DISCONNECT path was tried
    first but its tick-by-tick PD_PHY_Reset() drops the Rp pull-up, leaving
    PD_Det_Proc unable to see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
    [main.c, tps55289.c, tps55289.h]
2026-04-30 Add Power Control screen; unblock loop when no USB-CDC host attached
    Add a 5th screen (SCREEN_POWER_CTRL = 4) where LEFT sends
    ups.power.disable and RIGHT sends ups.power.enable to the CH32X. On all
    other screens the buttons keep their original navigation role. The new
    screen shows ON/OFF derived from the RP2040's own VBUS_OUT ADC plus the
    measured Vo. drawScreenIndicator now scales with SCREEN_COUNT so the
    dot row stays inside the 64 px width. Replaces the temporary
    POWER_TEST_BUTTONS compile flag.
    Wrap Serial (USB-CDC) writes inside TeePrint via UsbCdcDropIfDetached,
    which checks (bool)Serial before each write. Earlephilhower's SerialUSB
    blocks ~50 ms per byte waiting for buffer space whe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
    [main.cpp]
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2026-05-04 ch32x: switch to binary wire protocol v1
    Replaces the brace-balanced JSON command/status path with the UBX-
    style binary protocol from Web3-Pi-UPS/common/protocol.h. CH32X is
    now a leaf node at WUPS_ADDR_CH32X (0x03) implementing only `system`
    and `power` classes:
    - power.status emitted unicast to RP2040 @ 1 Hz as EVENT, plus on
    demand as RESP to system.status_query
    - system.hello broadcast on boot
    - REQ handlers for system.ping and power.{enable,disable,cycle,reset}
    Drops ~200 lines of snprintf/strstr-based JSON parsing in favor of a
    Fletcher-8 framer, a state-machine deframer fed from the existing
    256 B DMA RX buffer, and packed v1 payload structs. The DMA path
    itself is unchan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
    [main.c]
2026-05-04 rp2040: switch to binary wire protocol v1, become the bus router
    Replaces the brace-balanced JSON command/status path with the UBX-style
    binary protocol from Web3-Pi-UPS/common/protocol.h. RP2040 is now the
    hub of the four-node star: it deframes USB-CDC, UART0 (CH32X) and
    UART1 (M.2 ESP32) per port, and routes by DST:
    - BROADCAST (0xFF): consume + retransmit on every other port
    - INTERNAL (0x05): consume + retransmit on MCU ports only
    - unicast: forward on the address-mapped port
    - self: dispatched to wups_on_local_frame() in main.cpp
    CH32X power.status is cached, projected onto the legacy `json_*`
    globals so the existing OLED/alarm code keeps working unchanged, and
    re-emitted unic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
    [main.cpp]
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2026-05-06 firmware-rp2040: replace json_* globals with the `ui` snapshot struct
    These 21 flat globals were a leftover projection from the JSON-line era.
    The protocol moved to binary v1 long ago, so the name was misleading.
    Group them into a single `static struct { ... } ui;` with three labelled
    sections (from CH32X power.status, held-over from the previous protocol,
    RP2040-local). Mass-rename references and adjust comments. Also rename
    lastJsonTime -> lastFrameTime, newJsonReceived -> newFrameReceived.
    [main.cpp]
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2026-05-07 ch32x: power-path validation fixes — TPS55289 + MP2762A configuration
    Long load-test debug session (2026-05-07) resolved a stack of stacked
    configuration bugs that were silently degrading USB-C output behavior.
    Power path now stable end-to-end at 4.5 A USB-C load (PDO #1) for 60+
    minutes, both with and without battery, on a 12 V / 6 A bench supply.
    TPS55289 (firmware-ch32x/User/tps55289.[ch]):
    - Preserve HICCUP bit (REG_MODE bit 5, default 1) on enable_output(1).
    Old 0x80 write was clearing it, leaving SCP trips latched instead
    of auto-recovering. New value MODE_OE_BIT|MODE_HICCUP_BIT = 0xA0.
    - OCP_DELAY 128 µs → 3 ms (REG_VOUT_SR bits 5:4 = 01). Default tripped
    OCP on PD-trigger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
    [PD_Process.c, main.c, mp2762a.c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]
2026-05-11 feat(firmware): publish UPS telemetry to panel over MQTT
    Per ADR-0002 / ADR-0004 / ADR-0005 — ESP32 becomes a dumb pipe to per-device
    t/{iccid}/* and c/{iccid}/* topics; RP2040 decides what to send.
    firmware-ESP32-LTE-M:
    - Read SIM ICCID via AT+CCID and trim the Luhn check digit (20→19 digits)
    so the device matches the 1NCE-portal form.
    - Derive per-device MQTT credentials: username = ICCID, password =
    hex(HMAC-SHA256(MASTER_SECRET, ICCID)) via PSA Crypto (mbedTLS 4 dropped
    the legacy single-shot mbedtls_md_hmac).
    - Replace web3piups/* with the ADR-0004 split: retained LWT/status/identify
    on t/{iccid}/, subscribe to c/{iccid}/cmd/request and forward bodies to
    RP2040 as net.dow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
    [main.c, main.cpp, modem.c]
2026-05-12 ch32x: read VBAT/VIN from CH32X ADCs, skip MP2762A when unpowered
    Power telemetry from CH32X reported garbage (vbat=0, temp=350.2°C) the
    moment external power was removed. Root cause: MP2762A is powered only
    from PPVAR_INP_SYS, so when mains drops the chip is fully dead — its
    I²C pins clamp the bus low via ESD body diodes, every register read
    returns 0x00, and the junction-temp formula maps raw=0 onto ~350°C.
    Switch the two affected fields to CH32X-local ADC sources and gate the
    MP2762A path on its actual supply state:
    - vbus_in_mV: source from PA1 (DC_INP_ADC_SRC) — measures PPVAR_INP_COM
    before Q222, so it works in every state and is independent of the
    charger IC.
    - vbat_mV: s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
    [main.c, mp2762a.c]
2026-05-12 feat(fw-rp2040): unwrap net.downlink into local dispatch
    ESP32 wraps every MQTT-arrived message in a net.downlink EVENT to
    RP2040 (hdr + topic + raw WUPS frame). Until now RP2040 had no handler
    for that class/op, so commands published by the panel hit the hub and
    were silently dropped — Wups_Frames_Rx ticked but nothing executed.
    Deframe the inner frame (Fletcher-8 verify, SYNC/END check) and recurse
    into wups_on_local_frame() so anything already dispatched locally
    (ui.beep, ups.power.*, …) just works without duplicating the table.
    Closes the panel → broker → ESP32 → RP2040 path end-to-end; verified
    with the ui.beep self-test from the web panel — buzzer chirps on click.
    [main.cpp]
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2026-05-12 feat(fw-rp2040): publish cmd/response RESPs for panel-issued REQs
    Until now every command from the panel ended in "Sent — command xxx…"
    and never advanced — the broker accepted the publish but no RESP was
    ever produced on t/{iccid}/cmd/response, so the panel's dispatcher had
    nothing to flip the commands row to 'done'.
    Add wupsPublishCmdResponse(cls, op, seq, code), a one-byte-payload RESP
    emitter built on top of wupsBuildFrame + wupsRequestPublish. Wire it
    into three sites in wups_on_local_frame():
    - power.status REQ — already served locally from Last_Power_Status,
    now also acks with code=0.
    - ui.beep — acks with code=0 after the tone() call.
    - power.{enable,disable,cycle,reset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
    [main.cpp]
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2026-05-18 feat(fw-esp32): per-device MQTT secret from NVS, retire fleet MASTER_SECRET
    Track 0 / WS-10. The MQTT password was HMAC(MASTER_SECRET, ICCID) with a
    fleet-wide secret compiled into the firmware; ICCID is on the device label,
    so one captured unit forged the whole fleet's credentials.
    - identity.c: read a random per-device 32B secret from a dedicated
    read-only `prov` NVS partition instead of deriving from MASTER_SECRET;
    fail loudly if unprovisioned (no fleet fallback)
    - partitions.csv: custom table adding `prov` (nvs) at 0x310000, separate
    from app `nvs` so state wipes / app flashes never touch the identity
    - sdkconfig.defaults: enable custom partition table
    - tools/make-nvs-blob + temp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
    [nvs-blob.template.csv, partitions.csv]
2026-05-18 feat(fw-esp32): verify backend-signed commands (WS-9 / ADR-0009)
    Default-mode commands were transport-trust only (Fletcher-8, no auth):
    anyone able to publish to the broker could drive the device, and a
    captured command frame replayed forever.
    The ESP32 now verifies every downlink command before forwarding it:
    - cmdauth.c: parse the WAE1 auth-envelope, check the backend
    secp256k1 signature (pinned op pubkey + epoch from the `prov` NVS
    partition), enforce a monotonic freshness counter (replay-proof,
    state in writable nvs) and optional NTP expiry, then STRIP the
    envelope so the RP2040 receives the exact bare WUPS frame as before
    (Decision C — RP2040/CH32X firmware untouched)
    - ven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
    [nvs-blob.template.csv]
2026-05-19 chore(fw-esp32): Track 3 Flash-Encryption dry-run profiles (deferred, no eFuse burned)
    Non-destructive groundwork for the secure-comms hardware foundation.
    Adds committed, key-material-free build profiles and a dry-run-only
    partition table used to evaluate Flash Encryption via EFUSE_VIRTUAL:
    - sdkconfig.secure: FE DEVELOPMENT mode, NVS keyed by Flash Encryption
    - sdkconfig.secure.virtual: EFUSE_VIRTUAL dry-run overlay
    - partitions.secure-dryrun.csv: canonical layout + efuse_em (sim only)
    - .gitignore: never commit SB/FE key material or custom build dirs
    - untrack .claude-flow/data/pending-insights.jsonl (auto-generated runtime data)
    Scope locked to Flash-Encryption-only (Secure Boot v2 def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
    [partitions.secure-dryrun.csv]
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2026-05-19 feat(fw-esp32): Arkiv command authority core — cmdauth_arkiv (P2-1, Track 2 / ADR-0011)
    Paranoic authority module paralleling cmdauth.c (WS-9) but the authority
    is the owner wallet, not a pinned backend key:
    - device keypair from read-only prov (ak_dev_priv) → device Ethereum
    address via arkiv_crypto; owner address bound only via the physical
    OLED gate (writable state, never provisioned/network).
    - writable w3arkiv state: owner_addr / key_epoch / last_ctr / cur_block
    / claim_state, with monotonic-counter replay baseline + Braga block
    cursor (§4.4) and epoch revocation (§4.5).
    - init/bind_owner/set_epoch/clear implemented; resale-safe counter
    reset per owner (§10.6). Non-fat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
    [main.c]
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2026-05-19 feat(fw-rp2040): OLED trust-anchor gate + 2-button hold (P2-4c, Track 2 / ADR-0011)
    The RP2040 side of the Paranoic owner-binding trust anchor (plan
    §10.1/§10.4). The OLED (SSD1306 0x3C) and the two buttons (GPIO13/14)
    physically exist only on the RP2040, so the physical confirm lives here —
    a scoped, owner-approved exception to the Track-1 "RP2040 unchanged"
    Decision C. The RP2040 stays a DUMB renderer: it shows the ASCII the
    ESP32 sends, runs the 5 s both-button hold, and reports the outcome. It
    never parses the fingerprint/claim-code and is never the authority; the
    ESP32 verifies the owner signature and owns the binding (cmdauth_arkiv).
    The in-board UART link is the trust boundary.
    -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
    [main.cpp]
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2026-05-25 feat(firmware): OLED menu polish, arkiv wallet regen, UART resilience
    Iterating ADR-0012 on the bench. Several distinct fixes in one pass
    because they all interact at the menu / mode-switch boundary.
    - common: ui.trust_prompt mode=2 (system menu). RP2040 renders text +
    forwards button events; ESP32 owns the state machine.
    - ESP32 oled_menu: hierarchical Debug / Mode / Reset / Wallet / Back
    with back-first defaults on confirm screens. Activation gesture
    moved from "hold both 3s" to "hold LEFT 2s" — one-button is much
    easier on this hardware.
    - ESP32 cmdauth_arkiv: arkiv_regenerate_wallet() — fresh 32B secp256k1
    key written to ak_dev_priv in the prov NVS partition, wipes the
    o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
    [main.c, main.cpp, modem.c]
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2026-05-27 rp2040: fall back to debug screens when ESP32 absent
    The system-menu activation gesture (hold LEFT 2s on home) broadcasts a
    ui.button_event to the ESP32, which normally responds with a
    ui.trust_prompt and trust_ui takes over. The M.2 module is optional, so
    the ESP32 may not be present — previously the gesture beeped and then
    silently hung waiting for a response that never came.
    Now, if no trust_prompt arrives within 1.5s of firing the gesture, jump
    directly to the Power debug screen (currentScreen=1) and play a second
    short beep. This matches what the ESP32 menu's Debug entry does (it just
    sends ui.set_screen back to us), so the fallback is a shortcut, not an
    emulation. Mode/Reset/RegenWa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
    [main.cpp]
2026-05-27 fix(fw-ch32x): cold-boot with Pi5 attached + USB-C PD input
    Three combined issues left VBUS_OUT dead when the UPS was cold-booted
    with Pi5 already on the output and USB-C PD on the input. Worked with
    barrel-jack (no CC ramp) or with Pi5 hot-plug (clean STA_SINK_CONNECT
    path), which is why the failure mode only surfaced in the worst-case
    production sequence.
    * PD_Det_Proc — drop the dual-role STA_SRC_CONNECT branch. On v3 the
    CH32X is source-only (HUSB238 U150 owns USB-C INPUT PD), so whenever
    a CC connect is detected we should advertise SRC_CAP via VBUS_set_5V
    + STA_SINK_CONNECT. The old branch skipped VBUS_set_5V and left TPS
    REF uninitialized + PA7 (VBUS_OUT_EN) low.
    * main loo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
    [PD_Process.c, main.c]
2026-05-27 refactor(fw-ch32x): rebase PD_Process on WCH V1.0.2 source-only sample
    v3 hardware moves USB-C INPUT PD negotiation to a dedicated HUSB238
    trigger IC (U150); CH32X is source-only from now on. The fork carried
    ~450 lines of dual-role / SINK FSM dead code that never executed on v3
    and risked subtle race conditions (false SINK switches off floating
    SRC_TPx pins, etc.). Replace the fork's PD_Process.c with the upstream
    WCH ch32x035 USBPD_SRC sample V1.0.2 and reapply just the customizations
    that v3 actually needs.
    Carried over from the fork:
    * 4-PDO source caps (5V/5A, 9V/3A, 12V/2.25A, 15V/1.8A) instead of the
    WCH sample's single 5V/1.5A PDO
    * TPS55289 reconfiguration in STA_TX_ACCEPT — se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
    [PD_Process.c, main.c]
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2026-06-11 fix(rp2040): keep home screen on long-LEFT when no ESP32
    Disable the debug-screen fallback gesture (guarded by
    ENABLE_DEBUG_SCREEN_FALLBACK). Still beeps "NO ESP32" to acknowledge
    the gesture, but stays on the home dashboard instead of jumping into
    the debug screen strip. Temporary; flip the flag to restore.
    [main.cpp]
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2026-06-12 feat(ch32x): power.event edge detector (mains / fault / charge transitions)
    wups_send_power_event() existed since the protocol-v1 port but was
    never wired into a detector — MAINS_LOST/RESTORED, FAULT, CHARGE_FULL
    and CHARGE_LOW never hit the wire and the panel's event log stayed
    empty.
    wups_power_event_tick() runs in the 1 Hz block BEFORE
    wups_send_power_status() (the status send clears Tps_Status_Latched
    after packing, and the charger poll clears Chg_Data.fault on recovery —
    the detector must see those bits first):
    - MAINS_LOST/RESTORED: DC_Inp_Voltage_mV with 5500/4500 mV hysteresis
    around the panel's 5 V "Mains" derivation, so a brownout hovering at
    the threshold doesn't flap ev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
    [main.c]
2026-06-20 feat(ch32x): HUSB238 input PD sink driver with autonomous max-power negotiation
    On HW rev.3 the CH32X is SOURCE-only; input USB-C PD is owned by the
    HUSB238 sink controller. Add an I2C driver and have the CH32X drive it.
    Driver (husb238.c/.h, I2C 0x08, shared bit-bang bus):
    - Read the negotiated contract (PD_STATUS0/1) and source capabilities
    (SRC_PDO_5V..20V); select/request a PDO (SRC_PDO + GO_COMMAND).
    - Current decode uses an explicit 16-entry LUT (the steps are non-linear,
    e.g. code 0xD = 4.0 A, not 3.75 A — no formula is correct).
    Autonomous selection (once per attach, I2C overrides the VSET/ISET straps):
    - The strap RDO sets a fixed current floor and picks the highest source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
    [husb238.c, main.c]
2026-06-21 feat(power.status): v2 protocol + RP2040 OLED debug screens
    - common: add wups_power_status_v2_t (version=2, 40 B) — separate INPUT
    (HUSB238) and OUTPUT PD contracts, real vsys_mV/iin_mA (no longer aliased
    onto pd_contract_*), split LM75B/MP2762A temps, packed flags byte;
    receivers dispatch on the version byte. protocol_desc.md updated + stale
    LEN example fixed.
    - ch32x: emit power.status v2 (drop the pd_contract VSYS/IIN hack), sample
    PA0 (VBUS_OUT ADC), derive the output PD contract from PD_Ctl.ReqPDO_Idx.
    - rp2040: version-dispatch parse (v1/v2), forward + MQTT-uplink the raw
    payload so the v2 tail is not truncated at the hub; replace the old debug
    screens with INPUT/OUTPU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
    [main.c, main.cpp]
2026-06-21 feat(rp2040): single voltage on OLED OUTPUT/BATTERY screens (drop R/C dual)
    The dual RP2040-vs-CH32X voltage rows were only useful while diagnosing the
    battery-sense issue (now resolved — see web3pi_scope PROGRESS). Keep just the
    RP2040 ADC reading, labelled "V", and shift the remaining rows up.
    [main.cpp]
2026-06-21 ch32x: bump output PD current limits for full-power headroom
    Set the TPS55289 current limit a few % above each negotiated PDO so the
    output rail can source full rated power (~27 W) under test load without
    folding into constant-current at the profile boundary:
    5A->5.2, 3A->3.1, 2.25A->2.3, 1.8A->1.9 A.
    Fix rounding so the values land exactly: set_current_limit and the 0.1 A
    telemetry set-caches now use roundf instead of truncation (previously
    1.8 A became 1.75 A, and 5.2f*10 truncated to 5.1 A on watchdog re-apply).
    [PD_Process.c, main.cpp, tps55289.c]
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2026-06-22 feat(fw-esp32): adapt modem to W3P MODEM V1 M.2 (pinout, ensure_on, AT diag)
    - Modem pinout for the M.2 card: PWRKEY=GPIO1, UART TX=GPIO2, RX=GPIO4, DTR=GPIO5, RI=GPIO6 (via TXB0108 translator; GPIO3 is a strap, NC).
    - modem_ensure_on(): the modem keeps its own VBAT across ESP resets, so a blind PWRKEY pulse toggled a running modem OFF (caused minutes of AT failures). Probe AT on a temporary raw UART first (with a '+++' data-mode escape) and pulse PWRKEY only if silent. SIM7080G has no RESET_N. Bring-up ~18 s.
    - MODEM_UART_DIAG (default 0): raw-UART AT sweep for bench bring-up without esp_modem/power-cycle.
    [main.c, modem.c]
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2026-06-24 fix(ch32x-pd): drop output rail to 0V on sink detach
    The USB-PD source left the last negotiated voltage (9V/15V) live on the
    output after the sink was unplugged. Two causes:
    - STA_DISCONNECT never disabled the TPS55289. The negotiated setpoint
    stayed cached and the 2s re-apply watchdog kept re-pinning the rail,
    so it never came down.
    - Lowpower was still LowpowerON (copied from the WCH EVT sample), so
    STA_DISCONNECT entered STANDBY before PD_PHY_Reset(); the MCU slept on
    every unplug and the CC wake came back as a reset. An always-on UPS
    controller must never sleep (already documented in CLAUDE.md).
    Set Lowpower=LowpowerOff and call VBUS_disable() in STA_DISCONNECT, which
    turns t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
    [PD_Process.c]
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2026-06-24 fix(rp2040): relax Network hand-off 'No modem' timeout 1.5->4s
    A BUSY-but-present ESP32 (mid TLS handshake / Arkiv telemetry submit) could miss the 1.5 s window and get falsely flashed as 'No modem'. 4 s avoids the spurious notice; a genuinely absent/wedged M.2 just waits a bit longer.
    [main.cpp]
2026-06-24 fix(rp2040): clear No-modem deadline on ESP32 menu entry
    When the local menu's "Network" item hands off to the ESP32 menu it arms
    menu_pending_deadline_ms as a "did the M.2 answer?" watchdog. The
    trust_ui_active() branch in loop() returns before the deadline check
    further down ever runs, so once the ESP32 *did* answer the deadline was
    never cleared. It then fired the instant the menu closed — a spurious
    "No modem" notice (plus its beep) on every menu exit.
    Clear the deadline inside the trust_ui_active() branch, where we know the
    hand-off succeeded.
    [main.cpp]
2026-06-24 fix(rp2040): swallow held button on menu exit to stop double-click
    Exiting a menu via "Back"/"Exit" registered twice: one beep + action from
    the menu, then a second beep + a phantom dashboard screen change. The
    button that selected the exit item was still held when the menu closed,
    and the dashboard nav read it as a fresh press — its debounced
    checkButtons() edge state had gone stale because it is not ticked while a
    menu owns the buttons.
    Latch s_btn_release_guard whenever trust_ui or the local menu owns the
    buttons; once back on the dashboard, swallow input until BOTH buttons
    release. By the time nav runs the level reads HIGH, so no phantom edge
    fires. (LEFT was already covered by s_left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
    [main.cpp]
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
